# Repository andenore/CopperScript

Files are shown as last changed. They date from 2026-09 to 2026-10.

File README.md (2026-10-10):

# CopperScript

CopperScript is a semantic, strongly typed language for describing PCB
connectivity, electrical intent, and design constraints.

Contributors and LLM agents adding components should read
[AGENTS.md](AGENTS.md) and the
[component integration guidelines](docs/component-integration-guidelines.md),
including RF matching/reference-layout checks and switched-power hard macros
or strong placement/trace-width constraints.

The v0.1 compiler parses `.copper` source into a typed intermediate
representation and runs electrical-rules checks (ERC). It deliberately does not
claim fabrication readiness from routing guidance. Its prototype physical
workflow can place components and attempt geometry-checked detailed routing,
but a routed board still requires independent physical and KiCad DRC signoff.

The [mechanical-geometry specification and checklist](docs/mechanical-geometry.md)
adds polygonal outlines, cutouts and round mounting holes to the physical IR.
Try the routed L-shaped inspection probe (including performance profiling):

```console
uv run python -m examples.mechanical_probe.mechanical_example
```

Output: ignored `build/mechanical-example/`. The frontend supports a separate
[`mechanical` section](docs/mechanical-language.md) for circle/rectangle/polygon,
rounded and closed line/arc outlines, cutouts, NPTH holes/slots and physical rules.
Curved-query limits are explicit; complete manufacturing qualification remains
separate from routing and inspection export. Board-specific
builders live under `examples/`, never in the generic `pcbir` package. The
[examples index](examples/README.md) keeps each standalone example and its
assets in one directory.

A local [mechanical/floorplan editor](docs/mechanical-editor.md) displays real
footprint pads/courtyards, mechanical geometry and locked DXF/enclosure guides.
It supports rough auto-placement, ratsnest/copper filters, checked dragging,
temporary poses and reviewed persistent source locks/geometry edits with undo.
Named datums/edges, attachments, body-only overhangs, height/access policies,
atomic closed-path editing and an optional VS Code host share generic compiler
code. Temporary placement remains unsaved unless explicitly locked into source;
source changes always require diff review and Save. The
[verified implementation checklist](docs/mechanical-editor-plan.md) records tests
and limitations, including convex curved paths and reference-only DXF overlays.

```powershell
uv run copper edit-mechanical examples/mechanical_editor_demo/board.copper --footprint-root "C:/Program Files/KiCad/10.0/share/kicad/footprints"
```

The tool opens a loopback-only browser UI; Ctrl+C stops the service.
Use `--no-browser` to open its printed URL yourself. Footprints may resolve from
explicit roots or pinned Git library assets; proxy inspection is opt-in only.
Scroll the wheel to zoom under the pointer; hold the right mouse button to pan.
Ordinary left-drags apply after checking (with Undo). Numeric poses and rough
auto-placement remain explicit previews; apply or discard them before more edits.

Try `make EXAMPLE=mechanical-curves route` for rounded geometry/slot routing or
`make EXAMPLE=mechanical-reference edit` for a checksum-pinned enclosure guide.
Source edits stale previous routed/fill outputs; rebuild before using them.

[Importable mechanical profiles](docs/mechanical-profiles.md) split reusable
outlines, holes, keepouts and anchored connector placement into separate `.copper`
files. They create no electrical connections. Try the fictional carrier demo
(uses the existing pinned CopperLib connector, no manual library checkout):

```powershell
uv run copper check examples/mechanical_profile_project/board.copper --locked
uv run copper edit-mechanical examples/mechanical_profile_project/board.copper --locked
```

For a real host pattern, see the [CM4 baseboard example](examples/cm4_baseboard/README.md).
It binds two real Hirose 100-pin sockets to a CopperLib mounting profile with
four holes, separates project-owned mechanics from connections, and reserves
module/antenna clearance. It includes a minimal Makefile, editor/placement
commands and a profiled routing workflow that saves ground fills and verifies
zero opens/violations with native KiCad. This four-layer eMMC carrier is a
**routed prototype**, not an order-ready board; no manual CopperLib checkout
is required.

```powershell
make EXAMPLE=cm4 route
```

All examples use the [same Make targets and generic build runner](docs/make-builds.md),
not per-board routing scripts. `make compile-examples` compiles all complete
registered examples; `make EXAMPLE=cm4 compile` builds just one. GNU Make is
required in addition to Python/uv (use `mingw32-make` on Windows if that is its name).

A [50 mm circular LED-ring example](docs/round-led-ring.md) uses an offset nRF52832
as a non-radio controller, twelve GPIO-controlled LEDs and a rear CR2032 holder.
It exports a true KiCad circle and fixed radial placement, with profiling and an
optional routing run:

Its circle, rear ground pour and all fixed placements are declared directly in
`examples/round_led_ring/board.copper`. No Python builder is needed to export it:

```powershell
uv run copper export-kicad-pcb examples/round_led_ring/board.copper --locked `
  -o build/round-led-ring/round_led_ring.kicad_pcb
```

The optional example wrapper adds placement previews, profiling and native checks:

```powershell
uv run python -m examples.round_led_ring.round_led_example `
  --offline
```

Output: ignored `build/round-led-ring/`; default is a placed, unrouted inspection
board. See the linked guide for `--route` and independent ground-fill checks.

## GitHub inspection builds

The [board-routing workflow](.github/workflows/board-routing.yml) attempts the
complete full-vertical routing flow on relevant `main` pushes and manual runs.
Every pushed tag also routes the nRF52 hard-macro example and publishes an
experimental prerelease with source distributions, KiCad projects/local
footprints, six layer SVG previews, reports, logs, profiling and checksums.
CopperLib is fetched by pinned URL into the managed cache; no separate checkout
is required. Failed or timed-out attempts remain inspection drafts, never
manufacturing releases. See [CI setup and downloads](docs/github-board-builds.md).

## Quick start

An opt-in [physical hard-macro trial](docs/physical-hard-macros.md) preserves
Nordic RF matching copper and demonstrates a separate Johanson antenna tee,
corner fill exclusions and whole-assembly rotations. CopperLib downloads through
the pinned URL dependency automatically:

```powershell
uv run python -m examples.nrf_antenna_macro.hard_macro_trial `
  --offline
```

Output: ignored `build/nrf-hard-macro/`. This is an RF-only geometry probe,
not an operational radio or full-vertical routing integration.

A [small powered nRF52/CR2032 example](docs/nrf52-coin-cell.md) adds a 10-pin
SWD connector, two LEDs, two buttons and the radio support circuit:

```powershell
uv run python -m copperscript check examples/nrf52_coin_cell/board.copper --locked
uv run python -m examples.nrf52_coin_cell.nrf52_example --offline
```

Output: `build/nrf52-coin-cell/`. The RF macro is locked and pre-routed;
the remaining circuit is placed but unrouted. Add `--route` to attempt the full
pipeline (the current nRF example still fails package-access gates; see its
linked report/remaining-work guide). This is not production signoff.

Python 3.11 or newer is required. From the repository root:

```console
python -m copperscript check examples/valid_board/board.copper
python -m copperscript check examples/invalid_board/board.copper
python -m copperscript power-check examples/valid_board/board.copper
```

The examples already have a committed lock. Populate the URL dependency cache,
then reproduce without network access:

```console
python -m copperscript check examples/full_vertical/board.copper --locked
python -m copperscript check examples/full_vertical/board.copper --locked --offline
python -m copperscript audit-footprints examples/full_vertical/board.copper --locked --offline
```

Compile a valid design to normalized JSON IR:

```console
python -m copperscript compile examples/valid_board/board.copper -o board.json
```

Generate a self-contained KiCad 8 schematic:

```console
python -m copperscript export-kicad examples/valid_board/board.copper -o valid_board.kicad_sch
```

Generate a KiCad 8 PCB draft with resolved footprint geometry:

```console
python -m copperscript export-kicad-pcb examples/resolved_footprint_board/board.copper -o build/resolved/board.kicad_pcb
```

All PCB export commands automatically write a same-stem `.kicad_pro`, a
project-local `fp-lib-table`, and a `CopperScript.pretty/` footprint library
beside the PCB. No manual KiCad library registration is needed: keep that
generated directory together when sharing or moving it. These are generated
outputs, not user-maintained source libraries. Backend export uses resolved
assets and does not modify your global KiCad configuration. Input resolution
may fetch pinned URL dependencies before generation. See [generated KiCad
projects](docs/kicad-project-export.md) for portability and safety details.

[Managed footprint dependencies](docs/footprint-dependencies.md) resolve exact
GitHub/GitLab `.kicad_mod` asset URLs or KiCad `Library:Footprint` identifiers
bound through `footprint-library` in `copper.mod`. They share the pinned package
cache and `copper.lock`, so no manual footprint download or installation path
is needed. Try the [standalone example](examples/managed_footprints/README.md).

Local `.kicad_mod` paths in imported parts/modules resolve from the declaring
source; board-local paths resolve from the board. Unbound KiCad identifiers can
still use explicit roots:

```console
python -m copperscript export-kicad-pcb board.copper --footprint-root path/to/kicad-footprints
```

Placement remains a deterministic inspection grid and routing is not generated,
so the output is not yet fabrication-ready. Generated proxy pads remain
available for backend development through explicit opt-in:

```console
python -m copperscript export-kicad-pcb examples/valid_board/board.copper --allow-proxy-footprints
```

Produce a deterministic legal placement candidate and a four-gate readiness
report:

```console
python -m copperscript plan-layout examples/valid_board/board.copper --allow-proxy-footprints --candidates 3 -o planned.kicad_pcb --report layout-report.json
```

The planner estimates global routing congestion but does not generate copper.
Its report therefore marks Route as not run and Verify as blocked. See the
[physical layout workflow](docs/layout-workflow.md) for the research,
consolidated stages, algorithms, and limitations.
Placement now estimates facing escape corridors from connected SMD pad demand,
reserving space for via banks from both packages and a transit lane. Fixed
poses and rigid/proximity units remain authoritative; unresolved corridors
appear as `ESCAPE_CHANNEL_DEFICIT` warnings in the layout report. Optional
`--escape-margin-mm 0.5` and `--escape-transit-lanes 1` control this soft
estimate on `plan-layout`, `route-global` and `route-board`, not DRC clearance.
See the [escape-aware placement plan](docs/escape-aware-placement-plan.md).
The physical planner also uses soft supply-domain distribution objectives:
`--power-domain-weight 0.25` is the default; `0` disables domain attraction.
Multi-supply parts participate in each rail group without a hard boundary or
midpoint rule. Declared plane nets have reduced generic wirelength attraction.
Package preflight reserves plane contacts by default with fanout enabled;
`--no-early-plane-stitch` opts out for comparisons. Regional power pours are
explicit `copper_zone` constraints, not automatically inferred planes. See the
[power-domain and routing plan](docs/power-domain-routing-plan.md) and
[language reference](docs/language-reference.md).
The [unprofiled full rerun and layer review](docs/routing-domain-access-review.md)
connects all signal nets and GND pads; one USB return-via warning still blocks
signoff. It also documents the subsequent removed-corner occupancy correction
and the remaining full-rerun requirement.
The [detailed-routing research](docs/detailed-routing-research.md) explains
the geometry checks, fabrication-rule profile, and current full-board limits.

Produce deterministic multilayer global-routing guides after transactional
placement feedback:

```console
python -m copperscript route-global examples/valid_board/board.copper --allow-proxy-footprints -o global-route.json
```

Global guides reserve corridors, layers, and proposed transitions for ordinary
signal nets; declared copper-zone nets are reported as deferred and consume no
global wire corridor. Guides are not tracks or fabrication data.

Attempt detailed routing and write a native DRC report plus an inspection-only
KiCad PCB draft:

```console
python -m copperscript route-board examples/valid_board/board.copper --allow-proxy-footprints --report route-report.json -o routed-draft.kicad_pcb
```

Detailed signal tracks prefer long straight runs and 45-degree bends. Nets with
declared copper zones (typically GND) are deferred from ordinary maze routing;
`route-board` instead attempts short pad escapes and plane vias. Their copper
fill remains provisional until KiCad refills the zones and verifies physical
connectivity. A net named GND without a declared zone receives no implicit
plane.

If a zone pad remains inaccessible, the router first tries a bounded local
rip-up: it reserves a legal plane escape, identifies the ordinary nets that
block it, and reroutes only those nets. If that fails, escape feedback tries
alternative via exits and legal local placement changes from a clean placement.
Use `--zone-local-ripup-trials 0 --zone-escape-trials 0` to disable both, or
adjust `--zone-escape-movement-mm` for the placement step. These trials never
move components under existing copper. Soft plane-aware layer costs and
alternating inner-layer directions can be tuned with
`--layer-preference-cost` and `--direction-preference-cost` (zero disables
either preference); they do not override explicit layer restrictions or DRC.
Accepted ordinary copper is straightened unless `--no-route-smoothing` is
given. Opt-in `--layer-assignment-passes`, `--local-demand-cost` and
`--guide-escape-mm` move ordinary guide runs away from same-layer crossings and
full channels; see the [layer-balance review](docs/routing-layer-balance-review.md).
A reserved package escape is one terminal of its pin, beside the pin's own
surface access and its launch via on every layer; escape copper the finished
route does not need is removed (`--no-escape-terminals` restores port-only
terminals). Opt-in `--package-destination-ports` turns boundary ports toward
each pin's nearest other terminal.
For intentional diagonal placement, add a
`constraint allowed_orientations(U1) { values = "0,45,90"; }`; unconstrained
parts retain 0/90/180/270-degree candidates.

The command exits nonzero when routing or DRC is incomplete. Even a successful
native check does not qualify proxy footprints or replace KiCad and CAM review.
Use `--progress` for flushed phase/group/trial events during long runs; the
shared Make routing workflow enables this automatically and saves them in
`routing.log`. Full ground-feedback trials can each rebuild the routing.
Progress is not completion or signoff evidence; see [routing progress](docs/routing-progress.md).
`--pitch-mm`, `--passes`, and `--search-budget` bound detailed-routing work;
exhausting the search budget is reported per net rather than silently accepting
an unfinished path.
The report's `critical_lane_review` section reviews the exported copper of every
critical net: track lengths, layers and vias, pair and `length_match` skew,
spacing to other copper inside and outside breakout regions, coupled length to
other pairs and bends. `route-board` and `python -m pcbir.critical_preflight`
(for its critical copper) print it as one `CRITICAL LANES:` line; see the
[language reference](docs/language-reference.md#critical-routing-and-qualification).
For difficult boards, `--fanout` pre-escapes crowded SMD pads, `--soft-ripup`
and `--maximum-ripup-blockers 4` try bounded transactional rerouting, and
`--detailed-feedback-trials 4` retries legal placement changes against exact
routing failures. These experiments do not waive physical DRC. Pass
`--verify-plane-fill "C:/Program Files/KiCad/10.0/bin/kicad-cli.exe"` to
refill a disposable KiCad copy and include authoritative open-net/island
findings in the report; a zone outline or stitched via alone is not proof of
connectivity. See [routing research tasks](docs/routing-research-tasks.md).
The [routing-review todo](docs/routing-review-todo.md) tracks correctness and
optimization work; the [first-pass repeated review](docs/routing-review-pass1.md)
records independent KiCad results and the remaining six-layer bottlenecks.
The [second-pass review](docs/routing-review-pass2.md) verifies joint ground
escapes with zero KiCad unconnected items; critical-net and production signoff
remain outstanding.
The [third-pass review](docs/routing-review-pass3.md) confirms consistent
duplicate-land closure and feedback reports without changing the verified copper.

### Full-vertical routing from a fresh checkout (Windows / PowerShell)

This runs the complete placement/global-routing, fanout, detailed-routing,
package-ground escape feedback, native DRC and independent KiCad plane-check
workflow. The [2026-10-06 clean-revision rerun](docs/routing-shared-reference-review.md)
at `52adb05` passes with **49/49 ordinary nets, all eight critical nets, zero
resource overflow and zero KiCad violations/unconnected items**. Every saved
copper layer has zero via/pad overlaps and zero off-angle tracks. The run takes
about 30 minutes without function profiling. Native manufacturing-file export
also succeeds; electrical, impedance and assembly qualification remain separate.

The current example has explicit USB/RF profiles, source-backed
[RF circuit corrections](docs/rf-layout-audit.md), fixed mechanical anchors,
power-domain-aware placement and negotiated package access. USB transitions
explicitly share the declared In1.Cu reference; required return vias remain the
default for other policies. The command below recomputes the current source,
not a historical board. The [cheap critical preflight](docs/full-vertical-example.md#explicit-critical-profiles-and-cheap-preflight)
is also available for inspecting access before a long run.

If exact critical routing fails, optionally add `--critical-feedback-trials 1`
to `route-board` or the critical preflight. This bounded
[critical placement feedback](docs/critical-placement-feedback.md) tries legal
whole-unit rotations/moves and rebuilds all critical copper; it does not relax
profile limits or imply fabrication readiness. Each trial can take minutes.
The historical [pass-9 verification](docs/routing-review-pass9.md) used an
incorrect choke winding mapping. **Do not fabricate those historical USB
routes.** [Pass 11](docs/routing-review-pass11.md) corrected the CopperLib mapping
from Coilcraft's schematic. Copper DRC cannot validate internal component
connections; electrical qualification remains open even with clean routing.
The [paired refinement pass](docs/routing-review-pass10.md) removes redundant
search-step segments while preserving connectivity. It does not yet shorten
the real-board USB detours.
The [access/miter review](docs/routing-review-pass12.md) removes the oblique RF
access segments and small USB backtrack at the unchanged corrected placement.
All eight critical nets remain connected. The earlier corrected-input
[full rerun and six-layer review](docs/routing-review-pass13.md) kept their
copper and all 51 placements unchanged: KiCad finds zero GND/critical opens,
but three ordinary signal nets remain open (34 unconnected items), alongside
the eight library findings. The review records spare inner/bottom capacity,
guide-cost and tree/seam cleanup tasks. [Per-net policy telemetry](docs/routing-search-policy.md)
reports requested/effective detailed layer costs without changing routing.
Production gates remain outstanding.
The historical [compatible-escape increment](docs/routing-review-pass17.md) improved the
matched partial package stage from 72 to 74 exits. Two MCU exits remain pending;
that stage predates the successful current full rerun linked above.
The [escape-first increment](docs/package-access-first.md) now reserves ordinary
package exits before critical long routes with `--fanout`. If package access or
critical compatibility fails, ordinary area routing is blocked with zero search
passes. Bounded legal placement feedback rebuilds the reservations; use
`--package-access-trials 0` to disable moves without disabling the gate.
Directional placement margins now account for ordinary/power/ground access;
the joint preflight still verifies the actual reservations. An allocated fanout
via is not complete-board connectivity.
The [boundary-capacity increment](docs/package-boundary-access.md) now gates area
routing on mutually compatible ordinary paths beyond package collars. Its
matched-placement diagnostic proves 76/76 local witnesses after a multi-bend
fallback. A ready preflight now commits owned local paths and exact-layer
boundary anchors for detailed routing; blocked preflights retain provisional
witnesses only. Neither local access nor those stubs replace full-board routing.
[Pass 18](docs/routing-review-pass18.md) allocates all 76 ordinary exits at the
unchanged saved placement, but the modem-side USB pair then fails. The access
gate correctly blocks area routing. Subsequent alternate-owner preflight passes
both USB pairs, four RF groups, selected ground contacts and all 76 ordinary
boundary paths. The current full rerun subsequently reserves 104 ordinary exits
and all 80 requested GND contacts and passes full-area/fill/native DRC gates.

Install Git, [uv](https://docs.astral.sh/uv/getting-started/installation/), and
KiCad 10 with its footprint libraries first. The latest closure run used
KiCad 10.0.6 and Python 3.13.1. Only CopperScript needs checking out:

```powershell
# Use consistent package line endings in these new checkouts.
git clone -c core.autocrlf=false -c core.eol=lf https://github.com/andenore/CopperScript.git
Set-Location CopperScript

uv sync --python 3.13
# Fetch the exact locked URL dependency (subsequent runs can use --offline).
uv run --no-sync python -m copperscript check examples/full_vertical/board.copper --locked
```

`copper.mod` pins CopperLib's GitHub commit; `copper.lock` verifies its exact
part, footprint and physical-asset inventory in `.copper-cache/pkg/`. No manual
library checkout, footprint download or lock refresh is required. Canonical
package line endings are declared in `.gitattributes`. This reproduces routing
inputs/options, not byte-identical historical output. After fetching,
`--locked --offline` verifies every package byte without changing the lock.
If resolution fails, investigate changed bytes/revisions rather than relocking.
Initial cloning, `uv sync` and uncached URL dependencies need network access.
See uv's
[project workflow](https://docs.astral.sh/uv/guides/projects/) for environment setup.

After the setup above, run the complete workflow with:

```powershell
make EXAMPLE=full-vertical route
```

The shared Make workflow recomputes placement and routing from source with the six-layer
settings below, including the pinned placement scene, critical routing, fanout,
ordinary routing, ground feedback, native DRC and independent KiCad plane
verification and saves native filled copper. Each run writes a fresh `build/full-vertical/runs/<UTC-run-id>/` with
`board.kicad_pcb`, `board.kicad_pro`, `route-report.json`, `routing.log` and
`run.json` (command, timestamps, elapsed time and exit code). `build/` is ignored
by Git. Errors/interruption may leave only logs/partial artifacts; file existence
does not imply routing success. No Gerbers are generated.

The generic runner uses the current Python/uv environment and downloads the locked
dependencies if uncached; it never updates `copper.lock`. Set `RESOLVE_ARGS="--locked --offline"`
to prohibit fetching. It discovers `kicad-cli` on PATH or the standard Windows
KiCad 10 installation. Managed Git footprints are resolved from the lock; the
optional `KICAD_FOOTPRINTS` setting is used for native KiCad verification.
Override paths when needed, preview without routing using `BUILD_ARGS=--dry-run`, or
select a new/empty directory inside `build/`:

```powershell
make EXAMPLE=full-vertical route BUILD_ARGS=--dry-run
make EXAMPLE=full-vertical route `
  KICAD_CLI="C:/Program Files/KiCad/10.0/bin/kicad-cli.exe" `
  KICAD_FOOTPRINTS="C:/Program Files/KiCad/10.0/share/kicad/footprints" `
  RUN_DIR="build/my-routing-run"
```

The runner preserves the router's exit code: **1** means unmet routing/DRC
gates, **2** means setup/execution error, and **130** means interruption.
GNU Make itself returns nonzero (usually 2) when its recipe fails.
An existing nonempty output directory is rejected so old results cannot be
mistaken for a new run. Exit 0 still does not constitute manufacturing signoff.
Allow tens of minutes for a full-vertical run; the shared workflow is not a claim
that every example has passed complete routing.

Function profiling is enabled by default. Each run also saves `routing.prof`,
readable/JSON hotspot summaries and `phase-timings.json` under the same ignored
directory. Instrumentation adds overhead; use `PROFILE=none` for uninstrumented
speed comparisons (phase events are still saved). See
[profiling and optimization assessment](docs/routing-performance.md) for details,
current evidence and the prioritized optimization work list.
The detailed [optimization todos](docs/routing-optimization-todo.md) track implementation.
Package preflight can now negotiate alternate ordinary/critical/selected-ground
escape patterns before placement repair. The default is at most two proposals;
use `EXTRA_ROUTE_ARGS="--package-pattern-trials 0"` for a baseline comparison.
Every accepted pattern preserves prior exits and passes fresh owner/native
checks; this does not certify onward area routing. See
[package-access design and remaining work](docs/package-access-first.md).
Local repair now supports bounded blocker-cone expansion; use
`EXTRA_ROUTE_ARGS="--zone-dependency-expansions 0"` to compare without that extension.
Small noncritical placement moves also try bounded incremental repair. Use
`EXTRA_ROUTE_ARGS=--no-incremental-placement-repair` to compare against full placement reroutes;
unsupported moves always retain that fallback.
Inspect a run without changing it using `uv run --no-sync python -m pcbir.routing_benchmark summarize "build/full-vertical/runs/<run-id>"`.
The [performance guide](docs/routing-performance.md) explains guarded before/after comparisons.

For the equivalent explicit CLI invocation, adjust the KiCad paths if your
installation is elsewhere. From the CopperScript repository root, run:

```powershell
$kicadCli = "C:\Program Files\KiCad\10.0\bin\kicad-cli.exe"
New-Item -ItemType Directory -Force "build/full-vertical" | Out-Null

uv run --no-sync python -m copperscript route-board examples/full_vertical/board.copper `
  --locked --offline --layers 6 --fab-profile jlcpcb-six-layer `
  --hard-macro examples/full_vertical/buck-macro.json `
  --hard-macro examples/full_vertical/nrf-antenna-macro.json `
  --candidates 3 --placement-candidate candidate-00 `
  --feedback-iterations 1 --router-iterations 5 --critical-feedback-trials 0 `
  --pitch-mm 1 --passes 2 --search-budget 20000 `
  --soft-ripup --fanout --constrained-pins-first --progressive-guides `
  --repair-budget-multiplier 10 `
  --plane-contact-radius-mm 5 `
  --zone-escape-trials 4 --zone-local-ripup-trials 6 `
  --verify-plane-fill $kicadCli `
  --report build/full-vertical/route-report.json `
  -o build/full-vertical/board.kicad_pcb

$routingExitCode = $LASTEXITCODE
Write-Host "Routing exit code: $routingExitCode (1 means a draft with unmet gates; inspect the report)"
```

This recomputes placement and copper from `.copper` and footprints; it does not
load an earlier routed board. Allow tens of minutes: the recorded pipeline took
about 19 minutes plus final export/verification, and harder feedback trials can
take substantially longer. No external timing wrapper is required. KiCad library
versions can change geometry and results; record the installed version and
footprint inputs when comparing runs.

The explicit CLI outputs are `board.kicad_pcb`, its same-stem `board.kicad_pro`, and
`route-report.json` under `build/full-vertical/`. Open the board with its project
so KiCad uses the exported design rules. The report includes the independent
`plane_verification` result. The [latest complete run](docs/routing-shared-reference-review.md)
exits **0** with no ordinary opens, native violations, unconnected items or
resource overflow. Its explicit-copper IR report still defers GND to native
plane fill; `routing_complete=true` does not mean `fabrication_ready=true`.
An output file or zero airwires is not electrical, USB/RF or assembly
qualification. Older failed reports remain unchanged as historical evidence.
Vias avoid all pads by default, including same-net pads and annulus-edge contact.
The shared routing workflow does not enable blanket via-in-pad. Explicit
`--ground-via-in-pad` permits filled-and-capped GND vias for this six-layer
profile; that process must be explicitly qualified with the fabricator before
ordering a board.

For independent copper-layer plots and via/pad/bend metrics, see
[the layer-review workflow](docs/routing-layer-review.md).

After a run passes, generate native Gerbers/drills from its saved filled board
using the [manufacturing-file workflow](docs/manufacturing-files.md):

```powershell
uv run --no-sync python -m copperscript export-manufacturing `
  "build/full-vertical/runs/<run-id>/board.kicad_pcb" `
  --kicad-cli "C:/Program Files/KiCad/10.0/bin/kicad-cli.exe" `
  --skip-independent-cam `
  -o "build/full-vertical/runs/<run-id>/manufacturing"
```

This refuses native opens/violations. It produces `gerbers-drill.zip` and
`manufacturing-package.zip`, not an independently qualified release. The
explicit CAM skip follows the requested prototype workflow. This fixture has
no reviewed assembly BOM/CPL; supplier availability and component/support-circuit
qualification still require review before ordering.

To repeat the final independent refill/DRC on a saved copy without modifying
the routed draft:

```powershell
Copy-Item "build/full-vertical/board.kicad_pcb" "build/full-vertical/verified.kicad_pcb"
Copy-Item "build/full-vertical/board.kicad_pro" "build/full-vertical/verified.kicad_pro"
& $kicadCli pcb drc --format json --severity-all --refill-zones --save-board `
  --output "build/full-vertical/kicad-drc.json" "build/full-vertical/verified.kicad_pcb"

$drc = Get-Content "build/full-vertical/kicad-drc.json" -Raw | ConvertFrom-Json
Write-Host "Unconnected items: $($drc.unconnected_items.Count)"
$drc.violations | Group-Object type | Select-Object Name, Count
```

Keep all reported findings visible. The second review found zero unconnected
items, no shorts/clearance/dangling findings, and four library issues plus four
library mismatches; this is a recorded result, not a guarantee for changed inputs.

Validate and inspect a KiCad footprint before resolving it into a physical
design:

```console
python -m copperscript check-footprint path/to/package.kicad_mod --strict
```

For a development installation with the `copper` command:

```console
python -m pip install -e ".[test]"
copper check examples/valid_board/board.copper
python -m pytest
```

## Example

```copper
board SensorBoard {
    use library "tiny";
    import sensors "github.com/copperscript/examples/sensors";
    import stm32 "github.com/copperscript/examples/stm32";

    component U1: stm32.STM32G0B1CBT6;
    component U2: sensors.BME280;
    component R1: RESISTOR { value = 4.7kohm; }

    configure U1.I2C1 as SENSOR_BUS {
        SDA = PB7;
        SCL = PB6;
    }

    net I2C_SDA {
        U1.PB7;
        U2.SDA;
        R1.2;
    }

    supply V3V3 {
        voltage = 3.3V;
        external = true;
    }
}
```

See the [design specification](docs/design-specification.md), the
[language reference](docs/language-reference.md), and the complete [valid
example](examples/valid_board/board.copper).

Device-library authors should use the compact, table-driven
[device generation workflow](docs/device-generation.md) rather than writing
large MCU definitions by hand.

The implemented [rich device model](docs/rich-device-model-proposal.md) describes
how CopperScript can represent flexible Nordic pin routing, mode-dependent FX10
pins, differential ADC channels, multi-unit op-amps, and package connection
rules and the cross-vendor acceptance fixtures used to validate them.

The [hierarchical example](examples/hierarchical_board/board.copper) instantiates a
reusable [5 V to 3.3 V buck supply](examples/packages/power/buck_5v_to_3v3.copper)
and imports the sensor part from a separate package.

## Packages

Imports use stable URL-like package paths and an explicit local alias:

```copper
import power "github.com/copperscript/examples/power";
module PWR: power.Buck5VTo3V3;
```

Versions and development replacements are deliberately kept out of source
files. They live in `copper.mod`:

```text
module github.com/anden/CopperScript
require github.com/copperscript/examples v0.1.0
replace github.com/copperscript/examples => ./examples/packages
```

The compiler resolves the longest matching required module, loads all
`.copper` part and module definitions in the selected package directory, and
records the complete downloaded asset inventory in `copper.lock`. Without a `replace`, v0.1 fetches
tagged GitHub modules into `.copper-cache`; package source is parsed as data and
no package code is executed. Local replacements remain editable and retain
their current content hash as IR provenance without being locked in the sum
file.

## Compiler architecture

```text
.copper source
    -> lexer
    -> source-aware syntax tree
    -> hierarchical electrical IR
         |-> JSON IR
         |-> KiCad schematic backend
         `-> derived flat view -> electrical-rules checker
                              `-> power-state analyzer
                              `-> footprint resolver + draft physicalizer
                                      `-> physical IR
                                          |-> legal placement + routability estimate
                                          `-> KiCad PCB backend
```

The stages are intentionally separate so editor tooling and a future language
server can reuse parsing, semantic lowering, and ERC independently.

Key modules:

- `pcbir.lexer` and `pcbir.parser` — dependency-free source frontend.
- `pcbir.syntax` — source locations and syntax-tree declarations.
- `pcbir.compiler` — semantic lowering and typed unit validation.
- `pcbir.packages` — manifests, package resolution, Git cache, and checksums.
- `pcbir.model` and `pcbir.quantities` — immutable semantic IR.
- `pcbir.elaborate` — explicit hierarchy-to-flat derivation for consumers that
  require a global connectivity view.
- `pcbir.erc` — reusable electrical-rules passes.
- `pcbir.power` — explicit steady-state power-domain analysis.
- `pcbir.physical` — immutable, backend-neutral board geometry, footprints,
  placements, nets, tracks, vias, stackup, and design rules.
- `pcbir.footprints` — deterministic `.kicad_mod` reference resolution from
  board-relative paths or explicit KiCad library roots.
- `pcbir.physicalize` — resolved-footprint and typed placement-constraint
  lowering; proxy geometry is an explicit development fallback.
- `pcbir.placement` — hierarchy-aware analytical placement, hybrid
  legalization, route-aware detailed refinement, and deterministic Pareto
  candidate generation.
- `pcbir.layout` — four-gate readiness orchestration and placement reporting.
- `pcbir.routing` — deterministic multilayer global routing with
  negotiated-congestion guides and explicit overflow diagnostics.
- `pcbir.routeflow` — full-route candidate selection, bounded legal placement
  moves, atomic rollback, stagnation control, and fresh-route certification.
- `pcbir.critical` — profile-driven locked copper for critical, differential,
  clock, CAN, RF-feed, power, and length/via-constrained routes.
- `pcbir.detailed` — guide-aware deterministic general routing with legal pad
  escape, exact foreign-copper clearance, locked critical copper, and bounded
  whole-pass rerouting. See [detailed-routing research](docs/detailed-routing-research.md).
- `pcbir.geometry`, `pcbir.any_angle`, and `pcbir.shove` — shared exact integer
  predicates, deterministic visibility walkaround, and atomic recursive line
  shove with fail-safe rollback.
- `pcbir.drc` — fail-closed exact-copper checks, explicit coverage, scoped
  waivers, and content-bound physical signoff tokens.
- `pcbir.flow` — compatible global/critical/detailed routing and DRC
  orchestration with no proxy-to-copper shortcuts.
- `pcbir.manufacturing` — gated KiCad 10 Gerber/drill/netlist releases with
  independent structural CAM parsing, manifests, checksums, and atomic publish.
- `pcbir.process_drc` — separate provenance-bearing fabrication, stencil, and
  assembly capability gates.
- `pcbir.engineering` — evidence-graded screening results that explicitly state
  claim scope and model limitations.
- `pcbir.cam_qualification` and `pcbir.constraint_coverage` — fail-closed
  independent-tool evidence and end-to-end ownership of hard constraints.
- `pcbir.physical` — immutable placement, exact copper, typed zone/keepout
  intent, and content-bound external fill provenance. Manufacturing boards with
  zones are authoritatively refilled and saved by the pinned KiCad toolchain.
- `pcbir.importers.kicad_mod` — dependency-free, fail-safe KiCad footprint
  parser and normalizer.
- `pcbir.devicegen` — compact JSON/CSV device bundles, bounded extraction work
  packets, validation, and deterministic library generation.
- `pcbir.backends` — immutable backend artifacts and the KiCad schematic and
  PCB generators.
- `pcbir.serializer` — versioned JSON IR output.
- `pcbir.cli` — checking, compilation, KiCad export, and footprint inspection
  commands.

Python IR constructions are confined to test fixtures. `.copper` is the only
user-facing source format accepted by the compiler.

The [full-vertical acceptance design](docs/full-vertical-example.md) combines
an STM32G0C1, CAN, an EG800G cellular modem over UART and USB, an nRF52832
Bluetooth slave, low-power motion sensing, GNSS, user I/O, and two SWD ports.
It is the integration fixture for progressing from CopperScript source toward
reviewed manufacturing outputs; its documentation distinguishes implemented
checks from the remaining production-layout work.

## Current ERC checks

- Unknown parts, components, pins, nets, and supply sources
- Duplicate component, net, supply, and interface names
- Pins assigned to multiple nets
- Multiple push-pull or power outputs on one net
- Supply voltages outside declared pin limits
- Invalid, missing, or off-net supply sources
- Disconnected and unsourced power inputs
- I²C signal bindings, pin compatibility, and SDA/SCL pull-ups
- MCU peripheral completeness, package-pin availability, and mux validity
- Duplicate exclusive peripheral/pin selections and incompatible mux-resource settings
- Package DNC/required-pin rules and required net traits
- Functional-unit endpoint resolution to canonical physical pins
- Differential-pair completeness and finite device-mode selections
- Parametric route-rule pad membership and power-domain operating ranges

`power-check` separately evaluates named rail states and warns when a driven net
may back-power an I/O domain declared off. It is intentionally a conservative
steady-state analysis, not firmware or transient simulation.

Physical constraints are separate from connectivity. During physical lowering,
placement regions, keepouts, fixed locations, legal orientations, alignment,
minimum/maximum distance, and explicit placement groups become typed physical
IR and are enforced by `plan-layout`. Hierarchy, interfaces, and proximity
constraints also produce soft semantic placement groups.

The physical Python API also supports [rigid reference-layout clusters](docs/rigid-placement-clusters.md).
Unlike soft groups, these retain identity-bound local footprint poses and
keepouts during whole-cluster placement/refinement and routing feedback.
Full-vertical now binds the experimental TPS62130A and Nordic/Johanson
[hard macros](docs/physical-hard-macros.md) by default. Their local copper is
locked, but regulator current/thermal performance and RF/antenna tuning remain
unqualified. See the [integration plan](docs/full-vertical-macro-ground-plan.md).

## Exact assembly-selection prototype

Exact board-side manufacturer/MPN and supplier selections can be prototyped with
`copper assembly snapshot`, `copper assembly check` and `copper assembly bom`.
These are offline checks, not stock lookup or production approval. See
[assembly pinning](docs/assembly-pinning.md) for the workflow and JLCPCB API scope.

## KiCad schematic backend

The initial backend targets KiCad 8's `20231120` `.kicad_sch` format. It embeds
deterministic generic symbols derived from part definitions, places symbols on
a backend-owned grid, and connects pins through short stubs and named labels.
Generated coordinates and UUIDs never enter the CopperScript IR.

This first revision emits one flat sheet. Hierarchical designs are elaborated
explicitly and retain their original qualified component paths in hidden
`CopperScriptPath` properties. Native KiCad hierarchical sheets and mappings to
standard KiCad symbols are planned follow-up work.

## Physical IR and KiCad PCB backend

The physical IR is separate from the electrical IR and stores exact geometry
as integer nanometres. It currently models polygonal board outlines, two-layer
stackups, basic design rules, footprint bodies, pads and courtyards, component
placement, regions, keepouts, fixed/relative rules, semantic groups, physical
net-to-pad assignments, track segments, and vias. It validates cross-references
when constructed.

The KiCad PCB backend targets KiCad 8's `20240108` board format. It emits a
self-contained board with deterministic UUIDs, embedded footprints, net
assignments, copper tracks and vias when present, and a closed `Edge.Cuts`
outline. Each PCB export also writes a same-stem `.kicad_pro` with the physical
IR's minimum clearance and default net-class widths/vias; open the board with
that project for KiCad DRC. Backend tests include a completely routed synthetic
physical board. Generated reference designators are on fabrication layers
until a collision-aware silkscreen labeling pass is available.

The `.copper` frontend supports selected placement, routing, and copper-zone
constraints, while arbitrary board-outline authoring is still pending.
`export-kicad-pcb` resolves selected `.kicad_mod` files into
physical IR, checks that their numbered pads exactly match the electrical part,
and arranges components on a deterministic grid. These unrouted drafts must not
be sent for fabrication. Generic proxy geometry is available only with
`--allow-proxy-footprints` and remains clearly marked in output warnings.

`plan-layout` replaces the inspection grid with a deterministic, clearance-legal
placement and emits coarse routability metrics. It still creates no tracks and
explicitly blocks fabrication sign-off.

## CAM and RF/power qualification

Final-native CAM audits and RF/power contract assessments are documented in
[engineering qualification](docs/engineering-qualification.md). The
[implementation checklist](docs/qualification-todo.md) separates tested algorithms
from missing qualified geometry adapters, supplier inputs and prototype evidence.

## KiCad footprint importer

`load_kicad_mod()` and `parse_kicad_mod()` convert KiCad 6–8 footprint files
into `PhysicalFootprint`. The initial importer covers common SMD, plated and
non-plated through-hole pads, circular and oval drills, rotations, independent
mask/paste presence, round-rectangle ratios, and the usual line, rectangle,
circle, arc, and polygon graphics. Imported geometry can be emitted directly by
the KiCad PCB backend.

The importer is intentionally fail-safe. Custom/trapezoid pads, copper or mask
graphics, drill offsets, and unrepresented fabrication modifiers are rejected.
Presentation-only omissions such as 3D models and user text produce explicit
warnings; `--strict` promotes those warnings to errors. Source format, version,
generator, path, and SHA-256 checksum are retained as footprint metadata.

Managed footprint URLs and manifest-bound `Library:Footprint` identifiers use
the declared provider revision and inventory. Local `.kicad_mod` paths are
relative to the declaring source. Unbound `Library:Footprint` identifiers search
`<root>/Library.pretty/Footprint.kicad_mod` and
`<root>/Library/Footprint.kicad_mod` for each `--footprint-root`. Resolution
fails on zero or multiple matches, and the selected name must agree with the
footprint name declared inside the file. CopperScript never searches an
installed KiCad library implicitly.

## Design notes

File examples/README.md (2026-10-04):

# CopperScript examples

Each standalone example owns a directory so its source, helper code, local
assets and generated reference inputs stay together. The reusable component
packages under `packages/` are separate from these board and language examples.

| Example | Entry point |
| --- | --- |
| Device model showcase | `device_model_showcase/board.copper` |
| Full vertical integration board | `full_vertical/board.copper` |
| Hierarchical board | `hierarchical_board/board.copper` |
| Invalid diagnostics fixture | `invalid_board/board.copper` |
| Mechanical anchors | `mechanical_anchors/board.copper` |
| Mechanical curves | `mechanical_curves/board.copper` |
| Mechanical editor demo | `mechanical_editor_demo/board.copper` |
| Mechanical outline | `mechanical_outline/board.copper` |
| Mechanical reference assets | `mechanical_reference/board.copper` |
| Mechanical routing probe | `mechanical_probe/mechanical_example.py` |
| nRF52832 coin-cell board | `nrf52_coin_cell/board.copper` |
| nRF antenna hard-macro probe | `nrf_antenna_macro/board.copper` |
| Resolved local footprint | `resolved_footprint_board/board.copper` |
| Round LED ring | `round_led_ring/board.copper` |
| Valid compiler fixture | `valid_board/board.copper` |

The CM4 carrier, managed-footprint, and simulation examples already use
multi-file directories and retain their existing folder names.

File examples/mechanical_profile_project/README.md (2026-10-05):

# Split-file mechanical profile example

This is a compiler/editor demonstration, not a complete circuit, Raspberry Pi
HAT, or production-ready board. It uses an existing CopperLib debug header.

```text
board.copper                 Components, nets and explicit profile bindings
mechanics/carrier.copper     Reusable outline, holes, keepouts and pad anchor
```

The board applies `carrier.Carrier as host`, binding `debug` to `J_DEBUG`.
Imported holes become `host/H1` and `host/H2`; the board's extra `LOCAL` hole
remains project-owned. The profile fixes header pad 1 at `(15mm,10mm)`, with
90-degree front-side orientation and an exact footprint requirement. It creates
no component or electrical connection. Profiles can be consumed by additional
boards, or published in a versioned library and imported by URL-like package path.

From the CopperScript repository root:

```powershell
uv run copper check examples/mechanical_profile_project/board.copper --locked
uv run copper edit-mechanical examples/mechanical_profile_project/board.copper --locked
uv run copper export-kicad-pcb examples/mechanical_profile_project/board.copper --locked -o build/mechanical-profile/demo.kicad_pcb
```

Add `--offline` after dependencies are cached. This example inherits the
repository's pinned `copper.mod` and lock; copying it to a separate project
requires that project's own CopperLib requirement and lock, not a manual
CopperLib checkout. Local mechanics remain normal project source, without a
separate locked dependency.

Source saving is not yet enabled in the editor. Imported connector poses cannot
be dragged; imported/local geometry has ownership tooltips. Layer-scoped copper
keepouts are physical obstacles, not proof of routing or assembly qualification.

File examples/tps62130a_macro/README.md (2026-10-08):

# TPS62130A macro layout probe

This single-regulator board uses the CopperLib electrical module and its current
hard-macro asset. It has no CopperVigo components or ordinary board routing.
The output is a KiCad board for inspecting the regulator's own copper and filled
planes. The default 180° view puts VIN on the left, the inductor and VOUT on the
right, and the broad GND return below, matching the orientation of TI datasheet
Figure 11-1. The generated `board.copper` and local dependency manifest are
saved alongside the board for reproducibility.

From the CopperScript repository root, with a sibling CopperLib checkout and
KiCad footprints installed:

```sh
.venv/bin/python -m examples.tps62130a_macro.trial
```

Use `--copperlib PATH`, `--output-dir PATH`, `--footprint-root PATH`,
`--enabled`, or `--rotation 90` to vary the isolated probe. The script runs
KiCad 10 refill and DRC when `kicad-cli` is installed, and requires each owned
GND zone to have actual filled copper and the fixed VIN, SW and VOUT polygons
to remain netted.
This is a geometry probe,
not a production regulator qualification.

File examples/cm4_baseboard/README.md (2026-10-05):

# Raspberry Pi Compute Module 4 baseboard

A real CM4 connector/mounting-pattern example using importable mechanical
profiles, not a fictional host. **This is a routed carrier prototype, not an
order-ready PCB.** The installed CM4 must have eMMC with its OS already flashed
using a CM4IO or another USB-capable carrier. CM4 Lite and CM5 are not supported
by this example. No firmware is supplied.

The 70 x 70 mm, four-layer carrier contains two Hirose
`DF40C-100DS-0.4V(51)` sockets, regulated external 5 V input, a 3.3 V UART
header, four GPIO signals, a GLOBAL_EN shutdown jumper, a low-current activity
LED, and GPIO_VREF decoupling. The module itself is removable and purchased
separately, not an extra soldered footprint/BOM item.

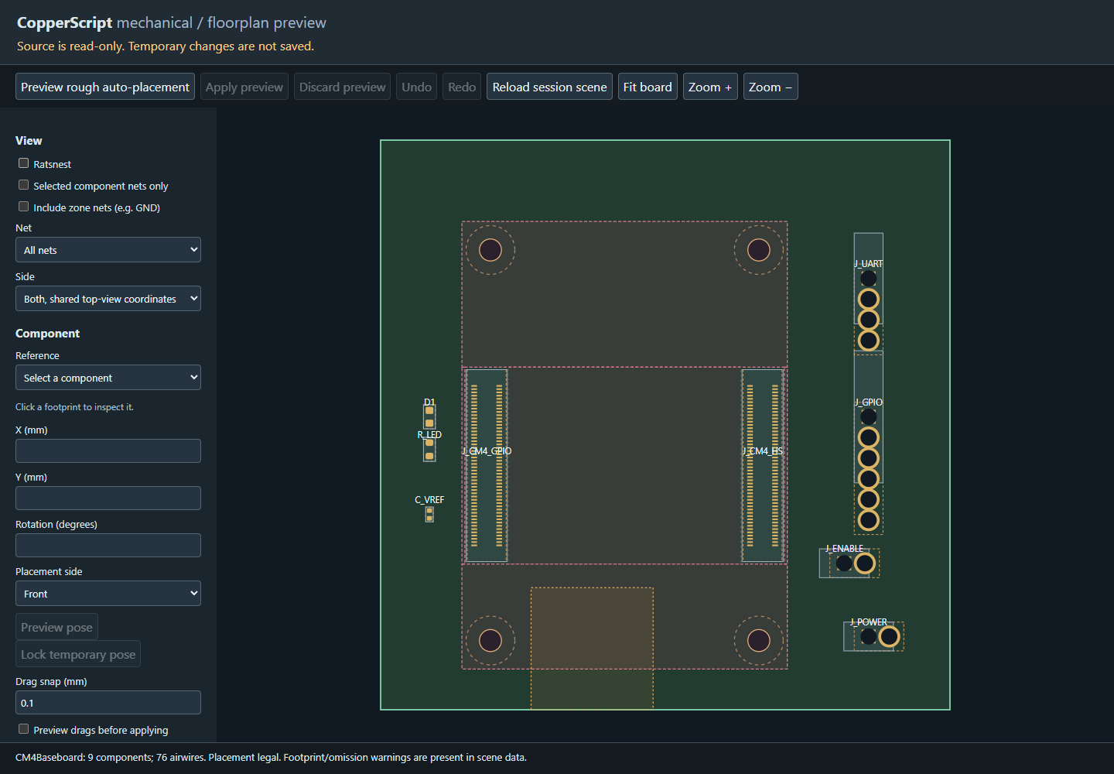
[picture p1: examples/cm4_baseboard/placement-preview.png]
CM4 carrier placement draft: two sockets, four holes and antenna clearance


Pink regions reserve the module body; the orange region is the antenna copper
keepout. This preview deliberately shows placement only, not completed routing.

## Reusing the mechanical pattern

`board.copper` owns electrical connections. `mechanics/carrier.copper` owns
the carrier outline, rules and four-layer antenna keepout. It imports
`cm4.CM4Mounting` from **CopperLib via its GitHub package URL**, then explicitly
binds its `gpio` and `high_speed` roles to the two sockets. No manual CopperLib
checkout is needed. `copper.mod` pins one revision; `copper.lock` authenticates
the downloaded library content. Local mechanical files remain editable.

The profile gives both connectors a 270-degree orientation and locks their
actual pad-1 positions, not guessed body centres. All 200 placed pad centres
are checked against Raspberry Pi's official CM4IO v5 carrier footprint.
It also contributes four M2.5 mounting positions with 2.7 mm NPTH carrier
drills, spaced 33 x 48 mm. The module envelope is x=10..50, y=10..65 mm.
There is no profile transform at the use site yet; changing this datum requires
an explicit profile revision, not moving one connector independently.

The selected 1.5 mm mating height leaves **no spare component height below the
CM4**. Front placement keepouts reserve its body, with two narrow courtyard
corridors for the sockets. Do not add other parts in those corridors. The
antenna clearance spans x=18.5..33.5, y=55..70 mm, excludes all copper on all
four layers, and reaches the bottom board edge. This is a conservative
projection of the datasheet's preferred antenna clearance, not RF qualification
or enclosure validation. Check the assembled module, screw/spacer heights,
cooling and surrounding metal in 3D before manufacture.

## Run from a CopperScript checkout

At the repository root, install the project once with `uv sync --extra test`.
The pinned Git footprint providers are resolved from `copper.lock`. On Windows:

```powershell
uv run --no-sync copper check examples/cm4_baseboard/board.copper --locked
uv run --no-sync copper plan-layout examples/cm4_baseboard/board.copper --locked `
  --layers 4 --fab-profile jlcpcb-four-layer `
  -o build/cm4-baseboard/cm4_baseboard.kicad_pcb `
  --report build/cm4-baseboard/placement.json
uv run --no-sync copper edit-mechanical examples/cm4_baseboard/board.copper --locked `
  --layers 4 --fab-profile jlcpcb-four-layer
```

The editor shows the locked imported sockets, mounting holes, keepouts and
toggleable ratsnest. Wheel zoom and right-button pan work as in other examples.
Run a fresh editor session for this board; existing sessions retain their own
in-memory poses. The editor currently previews poses but does not save them.

On Linux/macOS with `make`, from this example directory:

```sh
make check
make layout
make edit
```

The shared Makefile resolves managed footprints from the pinned Git providers.
Set `KICAD_FOOTPRINTS` only when native KiCad verification needs a nonstandard
installed footprint path. macOS and other custom installations should also
provide that override for native checks.

The `Makefile` produces placement drafts under ignored `build/cm4-baseboard`.
It intentionally does not call this a release/manufacturing build.
After the initial dependency download, add `--offline` to CLI commands for
cached builds. A full KiCad footprint installation is only needed for native
KiCad verification and routing.

### Complete routing and ground fill

From the repository root (Windows, KiCad 10 installed):

```powershell
make EXAMPLE=cm4 route
```

The shared [Make workflow](../../docs/make-builds.md) fetches pinned imports if needed, runs package escape
and detailed routing with profiling enabled, then **saves the ground fills**
and runs native KiCad DRC on that exact output board. No rule relaxation or
via-in-pad permission is added. Default outputs go in a timestamped directory
under ignored `build/cm4-baseboard/runs/`; open its `board.kicad_pcb` in KiCad.
`route-report.json`, `kicad-drc.json`, logs, input/output hashes and performance
reports are retained together. Success requires zero native violations and
zero unconnected items; a failed build returns nonzero and retains diagnostics.

For Linux/macOS or another KiCad installation, supply paths explicitly:

```sh
make EXAMPLE=cm4 route \
  KICAD_CLI=/usr/bin/kicad-cli \
  KICAD_FOOTPRINTS=/usr/share/kicad/footprints
# Or from this example directory:
make route KICAD_CLI=/usr/bin/kicad-cli KICAD_FOOTPRINTS=/usr/share/kicad/footprints
```

Set `RESOLVE_ARGS="--locked --offline"` after the first dependency download.
`RUN_DIR` selects a new/empty directory below the repository's `build/`; repeat
runs default to fresh timestamped directories. Use `PROFILE=none` for timing
comparisons. GNU Make is required (`mingw32-make` is also supported on Windows).
The example Makefile contains settings only; the same `make/board.mk` recipes
compile and route other boards without custom per-example Python scripts.

## Header wiring

| Header | Pins in footprint-number order |
| --- | --- |
| J_POWER | 1: regulated +5 V input; 2: GND |
| J_UART | 1: CM4 3.3 V sense; 2: CM4 TX/GPIO14; 3: CM4 RX/GPIO15; 4: GND |
| J_GPIO | 1: CM4 3.3 V; 2: GPIO2; 3: GPIO3; 4: GPIO17; 5: GPIO27; 6: GND |
| J_ENABLE | 1: GLOBAL_EN; 2: GND; leave open normally, short to power off |

Supply regulated 4.75..5.25 V at J_POWER. There is no reverse-polarity,
overvoltage, fuse or USB-C power-negotiation circuitry: use a suitable bench
supply and verify power routing/current sharing before connecting hardware.
Hirose rates each contact at 0.3 A; a supply's rating does not prove the socket
contacts can carry that current evenly. Every fitted ground contact and all
six 5 V contacts need a real carrier connection, not a routing waiver.

UART requires enabling/configuring the appropriate CM4 UART. Use a **3.3 V
logic** adapter, not RS-232 or 5 V logic. Cross host RX/TX and never inject power
through J_UART/J_GPIO. CM4 3.3 V outputs supply GPIO_VREF and the LED; the
`external = true` 3.3 V declaration describes the plugged-in module's source,
not permission to attach an independent 3.3 V supply. GPIO2/GPIO3 already have
CM4 pullups; extra I2C hardware is not modeled or validated here.

## Validation and remaining work

ERC checks the socket pin map, required power/ground contacts, 5 V limits and
reserved pins. Sockets expose passive signal contacts; this is **not** a full
active CM4 peripheral/mux/power-state model. Electrical sequencing, backfeed,
timing, loading and firmware assignments still need review.

Routing verified with KiCad 10.0.6: **all 11 ordinary nets routed**, GND connected
through escapes and filled In1.Cu/B.Cu zones, **zero unconnected items and zero
native DRC violations**. A separate copper-layer audit found zero via/pad
overlaps and only horizontal, vertical or 45-degree segments. In2.Cu carries
most signal length; In1.Cu is the ground reference. Some 90-degree joins remain,
so this is a connectivity/DRC-verified prototype, not an optimized reference
layout. The pre-fill IR-only checker still reports GND open because it does not
model filled zone copper; native filled-board evidence closes that check.

No Gerbers/assembly release or production-ready claim is made. Power traces
currently use the prototype minimum width: power routing/current sharing,
thermal performance and protection require review before powering hardware.
Manufacturing export remains a separate step.
The pin headers also need exact orderable selections before assembly ordering.
USB recovery, SD/Lite support, Ethernet, HDMI, camera, display and PCIe are
deliberately absent rather than partially connected.

Sources: [CM4 datasheet](https://datasheets.raspberrypi.com/cm4/cm4-datasheet.pdf)
(Fig. 4 and Table 6), [official CM4IO design files](https://pip.raspberrypi.com/categories/1210-design-files),
and [Hirose connector](https://www.hirose.com/en/product/p/CL0684-4033-4-51).
The downloaded sources and hashes are recorded in CopperLib's
`packages/profiles/raspberry_pi/cm4/evidence`;
raw vendor files are not redistributed with this example.

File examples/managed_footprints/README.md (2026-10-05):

# Managed footprint dependencies

This isolated project imports reusable resistor/capacitor parts and resolves
their geometry from a pinned KiCad Git repository commit. The resistor uses a
manifest-bound KiCad namespace; the capacitor uses an exact module URL. Both
share one repository download and one complete content inventory.

From the repository root, install the compiler and prepare the dependency:

```text
python -m pip install -e .
python -m copperscript lock examples/managed_footprints/board.copper
python -m copperscript audit-footprints examples/managed_footprints/board.copper --locked --offline --json
python -m copperscript export-kicad-pcb examples/managed_footprints/board.copper --locked --offline -o build/managed-footprints.kicad_pcb
```

The first command that resolves managed geometry downloads the complete pinned
footprint repository into this project's `.copper-cache`. The example's
`copper.lock` is created by `lock`; commit it in your own project. `--locked`
verifies the selected revision and inventory, and `--offline` requires the cache
to exist already. A lockfile alone does not contain the downloaded geometry.

No KiCad installation or `--footprint-root` is needed to audit or generate the
PCB. Native KiCad inspection remains a separate tool step. The layout is an
inspection draft; this example does not attempt manufacturing qualification.
See [footprint dependencies](../../docs/footprint-dependencies.md).

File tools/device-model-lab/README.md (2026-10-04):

# CopperScript device-model compatibility lab

This bounded research lab is kept with CopperScript tooling rather than in
CopperLib's reusable component catalogue. It records a provenance-first
`STM32G0B1CBT6` proof, CubeMX reconciliation fixtures and cross-vendor model
gap case studies. The results are incomplete and are not production packages.

From this directory, install the optional test/upstream dependencies and run:

```powershell
python -m copperscript_stm32g0 validate
python -m copperscript_stm32g0 generate
python -m copperscript_stm32g0 coverage
python -m pytest
python -m copperscript_stm32g0 compatibility
```

The normalized bundle is in `data/bundles/stm32g0b1/`; generated files are in
`generated/`. Source acquisition is opt-in and writes only ignored cache data.
The compatibility reports classify support gaps without changing CopperScript's
language or the generic CopperLib package contract.

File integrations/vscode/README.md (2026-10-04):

# CopperScript mechanical editor for VS Code

Optional custom text editor for `.copper` boards. Source stays authoritative;
reviewed edits use native WorkspaceEdit, document Undo/Redo, encoding and Save.
Unsaved text edits are compiled in memory. No backend source writes, downloads,
shell invocation or public server. A trusted **local workspace** is required.

Pin CopperScript in your project dependencies/lock first, run its normal fetch
workflow, and compute the exact compiler content identity:

```sh
uv run --locked --offline python -m pcbir.editor.document --fingerprint
```

Set `copperscript.mechanical.compilerDigest` to that 64-character result and
`copperscript.mechanical.footprintRoots` to installed KiCad footprint directories.
The default `compilerCommand` is `["uv", "run", "--locked", "--offline", "python"]`.
You may explicitly configure a pinned virtual environment's interpreter instead.
Commands are argv arrays, never shell strings. Compiler changes fail closed until
you intentionally update the digest. Layer/profile/template/macro settings must
match your build. Imports and footprint resolution remain locked/offline.

Build shared assets with `node integrations/vscode/build.cjs`, then launch an
Extension Development Host with `code --extensionDevelopmentPath=<absolute
build/vscode-extension/extension> <project-directory>`. On a `.copper` tab use
**Reopen Editor With → CopperScript Mechanical / Floorplan**. It is not the default
text editor. Select a component and **Show component source declaration** to open
its root declaration (or hierarchical instance) beside the board view.

Review source edits and choose Save reviewed source. Native document changes
invalidate old previews; invalid text remains editable in the regular text view
and can recover on the next valid document version. Native Undo/Redo restores
source, while temporary placement history is separate. A failed save leaves the
reviewed native edit dirty and undoable, rather than writing around VS Code.

This host deliberately uses VS Code's [custom text editor API](https://code.visualstudio.com/api/extension-guides/custom-editors)
and [workspace trust](https://code.visualstudio.com/api/extension-guides/workspace-trust).
Routed-reference import is currently available in the standalone host; advanced
mechanical formats remain governed by the main editor checklist.

Offline installable artifact (no npm/marketplace build dependencies):

```sh
node integrations/vscode/build.cjs
python integrations/vscode/package.py -o build/copperscript-mechanical.vsix
code --install-extension build/copperscript-mechanical.vsix
```

Packaging uses fixed archive timestamps and whitelisted runtime assets. Existing
VSIX files are never overwritten. CI publishes the staged extension as an artifact
and includes it in tagged inspection releases. This does not publish to Marketplace.

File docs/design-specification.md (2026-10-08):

# CopperScript design specification

**Status:** Draft specification with accepted architectural decisions
**Applies to:** CopperScript language, compiler, IRs, rule engines, and backends
**Last updated:** 2026-10-06

This document records the durable design decisions for CopperScript. It is the
normative architectural reference; the README explains usage and the language
reference describes current syntax.

The terms **MUST**, **MUST NOT**, **SHOULD**, and **MAY** express requirement
strength. Sections marked "Current implementation" describe temporary reality
and do not override the target architecture.

## 1. Purpose

CopperScript is a semantic language for electronic design. Authors describe
components, connectivity, electrical intent, and constraints. Tooling derives
validation results, exchange artifacts, and eventually physical layouts.

The central principle is:

> Describe electrical intent and constraints explicitly. Describe geometry only
> where physical geometry is itself the intent.

CopperScript is not a textual encoding of a schematic drawing application and
must not become one.

## 2. Architectural domains

The compiler architecture separates four domains:

```text
CopperScript source
        |
        v
+----------------------+       +----------------------+
| Electrical design IR |       | Constraint set       |
| parts, instances,    |<------| rules and targets    |
| nets, supplies,      | refs  | no connectivity      |
| interfaces           |       | ownership            |
+----------------------+       +----------------------+
        |                               |
        +---------------+---------------+
                        v
                +------------------+
                | Layout engine    |
                +------------------+
                        |
                        v
                +------------------+
                | Physical IR      |
                | placement,       |
                | routing, stackup |
                +------------------+
```

Schematic presentation is not another authoritative IR domain. It is a backend
artifact derived from the electrical design.

### 2.1 Electrical design IR

The electrical IR defines what the circuit is. It MAY contain:

- reusable part and pin definitions;
- package-independent device pads, electrical profiles, functional units,
  signal groups, power domains, peripherals, and route rules;
- component instances and selected footprints;
- explicit peripheral and pin-mux selections;
- nets and their endpoints;
- supplies, nominal voltages, and power sources;
- named discrete power states for analysis;
- protocol interfaces and their signal bindings; and
- typed electrical properties required for validation or generation.

It MUST NOT contain:

- schematic symbol coordinates or rotations;
- wire paths, junction drawing positions, or label positions;
- pages, sheets used only for drawing organization, title blocks, or view state;
- colors, fonts, zoom, selection, or other UI state;
- PCB placement, routing, board-outline, stackup, zone, or via geometry; or
- backend-specific object identifiers when they can be derived deterministically.

### 2.2 Constraint set

Constraints express requirements on a design; they do not define connectivity.
The compiler MUST lower constraints into a logically separate `ConstraintSet`
that refers to electrical objects through stable semantic references.

Changing or removing a constraint MUST NOT silently add, remove, or reconnect a
net endpoint. Conversely, moving a component between nets MUST require an
explicit connectivity edit rather than a constraint change.

Constraints MAY cover multiple domains, including:

- electrical limits, such as voltage, current, impedance, or timing;
- placement requirements, such as maximum distance or keep-together groups;
- routing requirements, such as width, clearance, topology, or length matching;
- manufacturing requirements; and
- advisory notes that remain machine-addressable.

Constraints SHOULD be declarative and typed. A constraint states the required
outcome, not a sequence of operations for producing it.

Source syntax MAY place constraints near related declarations for readability,
but source proximity MUST NOT merge their semantic ownership with connectivity.

### 2.3 Physical layout IR

The physical IR will describe one concrete realization of an electrical design.
It MAY contain board outline, stackup, component placement, footprint geometry,
tracks, vias, copper zones, and other fabrication geometry.

The physical IR MUST be a separate model generated from:

1. the electrical design IR;
2. the constraint set;
3. selected library and fabrication data; and
4. layout-engine decisions.

PCB coordinates belong here. Schematic drawing coordinates do not.

The physical IR MUST retain traceable references to the electrical objects it
implements. A track, pad, or zone may identify a net; it must not redefine that
net's logical membership.

The initial physical IR uses integer nanometres for coordinates and dimensions
so backend output is deterministic and does not accumulate binary floating
point error. It contains a closed polygonal board outline, stackup, basic design
rules, resolved footprint geometry, placements, physical net-to-pad mappings,
track segments, and vias. Physical objects use stable electrical component and
net names for traceability.

The model validates its internal references independently of any backend. A
placement must resolve a footprint, a net endpoint must resolve an existing
placement and pad, and copper geometry must resolve a physical net and stackup
layer. This structural validation is not a substitute for geometric DRC.

### 2.4 Presentation and tool artifacts

Backends MAY generate coordinates and other presentation data required by a
target format. Such data is backend-owned and MUST NOT flow back into the
electrical IR merely because a target application requires it.

For example, a KiCad schematic backend may arrange symbols on a grid and place
net labels. Those positions are rendering decisions, not CopperScript design
semantics.

## 3. Core semantic decisions

### 3.1 Connectivity has one source of truth

`Net.endpoints` is the canonical connectivity definition. Components, supplies,
interfaces, constraints, and backend renderings MUST NOT create a second
connectivity mechanism.

The compiler MUST reject or diagnose a pin assigned to more than one net.

### 3.2 Parts and component instances are distinct

A `PartDefinition` describes reusable facts about a part: pins, electrical pin
capabilities, device-pad bonds, limits, manufacturer data, and compatible
physical packages.

A `ComponentInstance` describes use of that part in one design: reference,
value, chosen footprint, and instance properties.

Backend symbol bindings and library lookup information SHOULD live in explicit
adapter or library metadata rather than in user-authored connectivity.

### 3.3 Supplies are explicit semantic objects

A supply annotates an existing net with voltage and sourcing information. It
does not create the net or connect pins implicitly.

Power-source validation and voltage-range checking consume supply annotations.
Ground is not a special parser primitive; it is a named supply/net with explicit
semantics.

### 3.4 Interfaces overlay connectivity

Interfaces describe protocol-level meaning, such as I²C signal roles and device
bindings. They refer to existing nets and pins and MUST NOT duplicate or replace
net membership.

Protocol-aware checks MAY require supporting components, such as I²C pull-up
resistors, by examining ordinary components and nets.

### 3.5 Quantities are typed

Physical values MUST carry dimensions. Units are normalized internally while a
display unit may be retained for diagnostics and serialization.

Cross-dimension operations, such as comparing voltage with resistance, MUST be
rejected. Backends MUST NOT infer a unit from an untyped number where the
language requires a physical quantity.

### 3.6 References are semantic, not positional

Components, nets, interfaces, and constraints refer to stable semantic names or
IDs. Source offsets and generated coordinates are provenance or presentation;
they are not design identity.

Renaming support should eventually update all semantic references through the
compiler model rather than textual search and replace.

### 3.7 Hierarchy is reusable electrical structure

A module defines a reusable electrical design with typed boundary ports. A port
MUST connect to exactly one internal net, and a parent connects a module instance
through ordinary net endpoints. Ports therefore expose connectivity without
creating a second connectivity system.

Modules MAY instantiate other modules. Circular imports or instantiation cycles
MUST be rejected.

The authoritative electrical IR MUST preserve module definitions, module
instances, typed ports, local component and net names, and boundary connections.
A module definition MUST be represented once regardless of how many times it is
instantiated. Compilation MUST NOT replace this structure with a flattened
netlist.

Hierarchy elaboration is an explicit derived operation. It MAY produce
deterministic qualified identities such as `PWR/U1` for ERC, global analysis, or
backends that need a flat connectivity view. The derived view MUST NOT become
the source of truth and MUST NOT be required by hierarchy-aware backends.

Constraints declared inside a module are instantiated and qualified with that
module. They remain in the constraint domain rather than becoming part of the
module's connectivity definition.

### 3.8 Packages have stable source identities

Reusable parts and modules are shared through packages identified by URL-like
paths such as `github.com/vendor/library/sensors`. Source files import a package
under a local alias and refer to its exports through qualified names. An import
path identifies source; it does not select a version.

Dependency versions and local development replacements MUST live in the
project-level `copper.mod`, not in individual source imports. Downloaded module
content MUST be authenticated by `copper.sum`. All resolved dependencies,
including mutable local replacements, retain their current content hash as
compiled IR provenance. A package is declarative: the compiler parses `.copper`
definitions and MUST NOT execute dependency-provided code.

Resolution uses the longest required module-path prefix. v0.1 supports GitHub
Git repositories and explicit local `replace` directives; this may later be
generalized without changing source import identity.

Reusable production part, device, footprint, and circuit-module definitions
MUST be maintained in the separate CopperLib project, whose stable module path
is `github.com/andenore/CopperLib`. The CopperScript compiler repository MAY
contain deliberately tiny built-in fixtures and compiler tests, but product
examples MUST consume newly created reusable definitions from CopperLib rather
than duplicate them locally. Local development uses an explicit `copper.mod`
replacement for the sibling CopperLib checkout.

### 3.9 Complex devices separate capabilities from packages

Complex programmable parts such as MCUs MUST distinguish three concepts:

- a package-independent `DeviceDefinition` describing named silicon pads,
  power domains, peripherals, peripheral signals, mux options, and shared
  configuration resources;
- a `PartDefinition` describing one orderable/package variant, its physical
  package pins, and explicit bonds from those pins to device pads; and
- a `PeripheralSelection` describing the explicit mux choices made for one
  component instance.

A device pad and a physical package pin are different identities. A mux option
maps a device pad to one peripheral signal and retains the target-specific
selector needed by a backend, such as `AF6`. A package pin may bond to one or
more device pads, and multiple package pins may bond to the same logical pad
where the package requires it. ERC resolves a selected package pin through its
declared bonds before validating mux availability.

Physical pins and device pads use an `ElectricalProfile` rather than one pin
type or capability bag. Signal domains, directions, drive modes, extensible
traits, and typed ranges are orthogonal. A pad may therefore be analog and
digital, bidirectional, and support both push-pull and open-drain drive without
inventing a combined enum value. Protocol signals declare required profiles;
ERC checks that a selected physical endpoint satisfies them.

Part categories and interface type names are open strings. Standard meanings
use the `std.` namespace, while dependency packages may define namespaced
vocabulary. Generic ERC MUST consume typed fields rather than infer behavior
from an unknown taxonomy string.

Functional units are package-independent semantic views over device pads. A
unit terminal resolves through its pad and package bonds to one canonical
physical pin. Source endpoints MAY use paths such as `U1.A.OUT`; connectivity
and pin-on-multiple-net checks operate on the resolved physical identity. Units
do not create connectivity and may guide backend presentation without adding
schematic geometry to IR.

Signal groups describe relationships such as positive and negative members of
a differential pair. Package pins carry explicit normal, required,
do-not-connect, or optional connection policy and may require net traits such
as `ground`. These are structural electrical rules, not name-based heuristics.

Finite mode groups and equality-only conditions control pad, bond, group, or
route availability. A component makes an explicit choice or uses a declared
default. General boolean expressions and conditions derived from connectivity
are not part of the language.

An optional, physically numbered package pin may have no electrical profile
while its function is unresolved. It is a structural placeholder only: ERC
must reject any net attached to it. This separates complete land-pattern
coverage from evidence-backed electrical modeling.

Explicit mux rows remain appropriate for irregular mappings such as STM32
alternate functions. Regular routing such as Nordic PSEL uses concrete named
pad sets and a typed selector scheme, avoiding an N-by-M expansion while still
retaining a deterministic concrete selection in compiled IR.

Optional resource and setting fields express device-wide configuration state.
Selections are exclusive by default. Exclusive selections requiring different
settings for the same resource conflict; multiple signals requiring the same
setting are compatible. A selection explicitly marked `firmware_managed` MAY
share a peripheral, pin, or resource only when every conflicting selection is
also firmware-managed. This
waiver suppresses only resource-ownership conflicts: unknown pads, invalid mux
options, missing required signals, and electrical incompatibilities remain
errors. A design may omit peripheral configuration and use a pin as ordinary
GPIO when detailed firmware mode checking is not useful.

Peripheral configuration annotates component behavior and MUST NOT create or
modify net connectivity. A configured pin is connected only by appearing as a
net endpoint. This preserves nets as the single source of electrical
connectivity.

v0.1 requires explicit pin assignments. Automatic pin assignment MAY later be
implemented as constraint solving, but its result MUST lower to the same
concrete `PeripheralSelection` IR and retain every selected pin and mux
selector. Device packages are declarative data. Source document, revision,
location, URL, and checksum are optional metadata and MUST NOT be required for
compilation. Generated production libraries SHOULD retain such provenance when
available so data can be audited; hand-authored or experimental definitions may
omit it.

### 3.10 Power domains and discrete power states

Device pads MAY belong to named power domains. Each domain identifies the
device supply pads that establish its powered state. I/O pads may also declare
their unpowered behavior as `high_impedance`, `tolerant`, `clamped`, or
`unknown`.

A board MAY define named power states by assigning each relevant `Supply` the
state `on`, `off`, or `unknown`. Power states annotate the existing electrical
design; they MUST NOT create rails, sources, switching connections, or implicit
net membership. Modules do not own board-level power scenarios in v0.1.

Power-state analysis is a separate IR consumer from ordinary ERC. The v0.1
analyzer performs conservative steady-state checks, including warning when a
driven net reaches a clamped or unknown I/O pad whose domain is off. It does not
simulate firmware, analog transients, ramp timing, regulator dynamics, or the
internal behavior of power switches. Later sequencing and transition models
MUST build on the same explicit domains and states rather than embedding a
hidden simulator in connectivity checking.

### 3.11 Generated device libraries use compact normalized data

Large devices SHOULD be maintained as normalized metadata and tables rather
than hand-authored repetitive CopperScript. The repository generation workflow
uses JSON for device/package metadata and CSV for pads, pins, peripheral
signals, and mux options. Deterministic tooling validates references and emits
ordinary `.copper` definitions; generated source remains declarative and is
compiled through the same frontend as hand-written packages.

The normalized bundle is authoritative library input. Generated CopperScript
MUST be reproducible and SHOULD carry a generated-file notice. CI SHOULD fail
when checked-in generated files differ from the bundle.

Unknown or disputed extracted values use an explicit marker and MUST block
generation. Tooling SHOULD produce small work packets containing only selected
or unresolved rows plus the relevant enum vocabulary and optional provenance.
This permits datasheet agents to work on bounded tables without repeatedly
loading complete devices or emitting repetitive syntax.

Machine-readable vendor data SHOULD be preferred over PDF extraction. Source
provenance remains optional as required by CS-027, but generators SHOULD retain
it whenever available. Generation tooling MUST NOT execute dependency-provided
code.

## 4. Language and compiler

`.copper` is the only user-facing source format. Executable Python is permitted
only in internal tests and development fixtures.

The compiler pipeline is:

```text
UTF-8 source
    -> lexer
    -> source-aware syntax tree
    -> semantic lowering
    -> electrical IR + constraint set
    -> ERC and constraint validation
    -> one or more backend artifacts
```

Each stage SHOULD have a narrow API and be independently testable. Parsing MUST
NOT perform backend generation. Backends MUST NOT reparse CopperScript source.

Diagnostics MUST have stable machine-readable codes. Syntax and semantic
diagnostics SHOULD include source spans. ERC diagnostics must eventually map
back to the declaration or reference that caused them so a language server can
publish precise editor diagnostics.

Compilation MUST be deterministic for identical source, libraries, compiler
version, and options.

## 5. Validation

Electrical-rules checking is a consumer of the electrical IR, not parser logic.
It SHOULD remain usable by tests, editor tooling, importers, and backends.

ERC currently covers unknown references, duplicate references, pins on multiple
nets, conflicting outputs, supply voltage limits, unsourced power inputs, basic
I²C rules, and explicit device mux selections. Device checks include package-pin
availability, required peripheral signals, valid mux choices, exclusive pin and
peripheral use, electrical compatibility, and shared resource settings. New
checks SHOULD be independent passes with stable diagnostic codes.

Discrete power-state analysis is also an independent IR pass. It reports
unknown state rails and possible back-power paths without changing electrical
validity or connectivity. Firmware-managed sharing waives ownership conflicts,
not structural or electrical validation.

Constraint validation is distinct from ERC even when both run under `copper
check`. This separation allows electrical validity, constraint consistency, and
physical feasibility to be reported independently.

A backend MUST NOT silently repair an invalid electrical design. Generation may
stop on errors or proceed only through an explicit diagnostic/testing option.

## 6. Backend architecture

A backend consumes compiled semantic models and produces named artifacts. It
MUST NOT mutate the electrical IR or constraint set.

Conceptually:

```text
Backend.generate(
    electrical_design,
    constraint_set,
    backend_options,
) -> ArtifactManifest
```

An artifact manifest may contain one or more files, warnings, target-version
metadata, and provenance.

Target-specific names, symbol mappings, file versions, and generated UUIDs
belong in the backend or its adapter registry. They SHOULD NOT leak into the
core electrical model unless they represent genuine cross-backend semantics.

Backends SHOULD generate stable ordering and deterministic identifiers so small
source changes produce reviewable diffs.

### 6.1 KiCad schematic backend

The first external backend generates a KiCad schematic as an
interoperability artifact. Its goals are to:

- validate that CopperScript electrical semantics map to a real EDA tool;
- provide a visual, inspectable schematic;
- carry references, values, footprints, nets, and labels into KiCad; and
- support KiCad's normal schematic-to-PCB workflow.

It is not a layout engine and MUST NOT introduce schematic coordinates into the
electrical IR.

The initial implementation:

- targets KiCad 8 and schematic format `20231120`;
- creates embedded generic symbols from CopperScript part definitions, with a
  future adapter layer responsible for mappings to standard KiCad libraries;
- creates deterministic, version-4-shaped UUIDs from stable semantic identity;
- uses a simple backend-local grid arrangement;
- uses short pin stubs and named net labels instead of aesthetic wire routing;
  and
- verifies generated artifacts through deterministic fixtures and should also
  use KiCad tooling when it is available.

The first revision emits one flat sheet by explicitly elaborating the compiled
hierarchy. Qualified CopperScript instance paths are retained in hidden
`CopperScriptPath` properties when they cannot be used directly as KiCad
references. This is an interoperability limitation, not a change to the
authoritative hierarchical IR. Native KiCad sheets are planned after the basic
artifact path is proven.

The generated schematic is not the source of truth. Round-trip import and
back-annotation are outside the first implementation and require a separate
design decision.

### 6.2 KiCad PCB backend

A KiCad PCB backend consumes the physical IR, not schematic drawing data. It
serializes placement and routing decisions while preserving references to
electrical nets and components.

Generating an unrouted board skeleton directly from the electrical IR MAY be a
useful intermediate feature, but any automatically chosen placement belongs to
backend output or physical IR, never to the electrical IR.

The initial implementation:

- targets KiCad 8 board format `20240108`;
- emits embedded footprint pads and simple body outlines rather than relying on
  the receiving installation's footprint libraries;
- emits physical net assignments, track segments, vias, and a closed
  `Edge.Cuts` outline;
- uses deterministic, version-4-shaped UUIDs derived from stable object
  identity; and
- accepts only `PhysicalBoard`, making the electrical/physical boundary
  explicit in its public API.

The temporary physicalization adapters are not placement engines. The normal
path resolves verified footprints and creates deterministic grid placement;
`prototype_physicalize` additionally creates generic proxy pads only when the
caller explicitly requests that development fallback. Both outputs MUST be
marked as not fabrication-ready, and the backend MUST report the remaining
placement/routing limitations as warnings.

### 6.3 Physical-design workflow

The user-visible physical-design workflow has exactly four gates: Prepare,
Place, Route, and Verify. Detailed activities such as floorplanning, global
placement, legalization, local refinement, and routability estimation are
internal Place substeps rather than independent public phases. Global corridor
and layer assignment, detailed routing, rip-up/reroute, and tuning are Route
substeps. DRC, electrical/thermal/RF analysis, DFX, and CAM inspection are
independently reportable Verify checks.

A completed Place gate MUST mean that all represented components are inside the
board and satisfy represented component-clearance constraints. It SHOULD include
a coarse global-routing estimate so congestion can feed back into placement.
Such an estimate MUST NOT be represented as routed copper. Route remains not run
until geometrically valid tracks and vias exist, and Verify MUST remain blocked
until required sign-off checks have passed.

Placement MUST consume typed physical constraints rather than interpreting
source text. The physical IR represents courtyard geometry, keepouts, placement
regions, fixed placement, legal orientations, minimum/maximum distance,
alignment, and semantic groups. Groups derived from preserved module hierarchy,
interfaces, and proximity constraints provide soft clustering intent without
changing electrical connectivity.

Reference-layout macros are separate **hard rigid physical clusters**. Their
member poses MUST be bound to resolved footprint geometry and source identity,
with an explicit evidence locator and anchor physical pad/origin. Translation
and permitted rotation MUST preserve all local poses and layer-scoped keepouts.
Fixed members freeze the unit; conflicting fixed poses, unsupported mirroring,
incompatible footprints or overlap between rigid clusters MUST fail closed.
Ordinary legalization, refinement and placement/routing feedback MUST NOT split
a macro. No electrical net/pin mapping changes with a physical transform.

An explicit physical scene MAY bind a content-addressed vendor reference to
resolved footprint hashes and declared physical pad/net roles. This binding MUST
be data-only, reject mismatches and unknown rules, and leave connectivity in the
electrical source. A source locator's local filesystem path is not asset identity.
An explicit internal macro courtyard gap MAY differ from the ordinary additional
gap; non-overlap, external spacing and all copper/fabrication checks still apply.
Provisional footprint adaptation MUST NOT be reported as reference-layout or RF
qualification. See
[rigid-placement-clusters.md](rigid-placement-clusters.md) for the initial API,
bounded-search limitations and separation from RF qualification.

The initial placement engine uses deterministic multi-seed analytical global
placement, hybrid discrete legalization, hard relative-rule repair, and legal
local refinement with coarse per-layer routing feedback. Wirelength and
routability metrics use transformed footprint pads. Multiple legal results are
Pareto-filtered and deterministically ranked; reports MUST retain both the
selected result and candidate metrics. Proxy crossings, vias, pin escape, and
congestion are estimates only and MUST NOT be serialized as routed copper.
High-pin-count packages receive a soft escape-channel spacing objective,
measured between placed courtyards. It may use free board area but MUST NOT
override fixed positions, board/keepout legality, or relative constraints;
close-placement companions move together when a legal cluster translation
improves the score. Spacing remains a placement heuristic, not a routing
guarantee.

Automated placement and routing artifacts MUST retain their algorithm identity,
gate state, metrics, and non-fabrication-ready status. See
`docs/layout-workflow.md` for the researched algorithm choices and implemented
scope.

### 6.4 Footprint importers

External footprint formats are adapters into `PhysicalFootprint`; they are not
alternate physical IRs. Importers MUST normalize exact geometry, retain source
identity and checksum metadata, and report every unsupported construct. They
MUST reject fabrication-relevant geometry that cannot be represented rather
than silently approximating or dropping it.

The KiCad `.kicad_mod` importer parses KiCad 6–10 S-expressions without
executing code or requiring KiCad. It supports ordinary SMD and through-hole
pads, circular and slotted drills, pad rotations, mask and paste layer presence,
paste-only apertures, per-pad zone/heatsink/layer-removal properties,
footprint-local clearance, round-rectangle ratios, and common footprint drawing
primitives including mask and paste artwork. Simple footprint-local copper
keepouts are typed, transformed with each placement (including back-side
mirroring), conservatively excluded from routing grids, checked against exact
copper geometry in DRC, signed with the geometry, and emitted
as deterministic KiCad board zones. Active footprint-placement keepouts,
connected footprint zones, and polygon holes remain unsupported and fail
closed. Ignored
presentation-only constructs produce warnings, and strict mode promotes all
warnings to errors. Custom pads, copper graphics, drill offsets, and
unsupported fabrication modifiers are errors until the physical IR can retain
them losslessly.

Board-level `PlacementKeepout` constrains component placement only; it is not a
copper obstacle for global or detailed routing. Only typed copper keepouts may
block tracks and vias. The two keepout classes must not be conflated.

Footprint selection and footprint resolution are separate phases. The
electrical IR retains the user-selected string; physical lowering resolves it
through a dedicated adapter. A direct `.kicad_mod` path is relative to the
board source. A KiCad `Library:Footprint` identifier is searched only in
explicit caller-provided roots. The resolver MUST NOT inspect an installed EDA
tool's implicit library configuration because that would make builds
machine-dependent. No match and multiple matches are both errors.

The selected name MUST agree with the name declared inside the footprint file.
Before placement, the set of non-empty electrical pad numbers MUST exactly
match the part's physical pin numbers. Duplicate footprint primitives sharing
one pad number are allowed, and unnumbered non-plated mounting holes are ignored
for electrical matching. Proxy geometry requires explicit opt-in and MUST
remain marked as non-fabrication-ready.

Repeated physical lands with one pad number are one logical electrical pin,
but they remain distinct copper objects for layout and independent KiCad DRC.
The PCB flow SHOULD bridge them with exact-clearance copper where legal and
MUST report any unbridgeable lands as pending. Existing exact copper paths on
any common physical layers MUST be reused rather than demanding a redundant
surface bridge. Land closure MUST precede full/subset candidate scoring and
its actual added copper MUST be measured. Native checking MUST include multiple
physical lands even when a net contains just one logical pad reference.
It MUST NOT interpret a shared
pad number alone as proof that all lands are externally connected. A future
explicit, qualified internal-tie declaration may avoid unnecessary copper,
but no such waiver is implied by the current footprint importer.

## 7. Serialization and versioning

Serialized IR MUST declare a schema identifier and version. Readers MUST reject
unsupported incompatible schema versions rather than guessing.

The default serialized electrical IR MUST preserve hierarchy. A serialized flat
view, if offered for debugging or interoperability, MUST be clearly identified
as derived and non-authoritative.

Serialization SHOULD be stable and suitable for testing, inspection, and tool
integration. It is a compiler artifact, not necessarily the long-term source
format.

Backend artifacts MUST identify CopperScript as their generator where the
target format provides such a field.

## 8. Non-goals for v0.1

The following are deliberately outside the current scope:

- production-ready automatic PCB placement and routing;
- copper pours and direct fabrication output;
- schematic beautification beyond a deterministic basic rendering;
- importing arbitrary KiCad projects into CopperScript;
- lossless round trips through external EDA tools;
- advanced design variants and parameterized/generic modules; and
- global component sourcing or lifecycle management.

These exclusions prevent target-tool details from distorting the language
before its semantic core is stable.

## 9. Current implementation and required refactoring

The current `Board` dataclass combines electrical objects and a `constraints`
tuple. This is transitional. Before physical-layout work expands, it SHOULD be
replaced by a package-level result similar to:

```text
CompiledDesign
  electrical: ElectricalDesign
  constraints: ConstraintSet
```

The current constraint syntax may remain unchanged; the separation is semantic
and architectural, not necessarily visual in source.

Footprint strings are opaque selections in electrical IR. The physical
resolver interprets explicit `.kicad_mod` paths and KiCad library identifiers;
the KiCad PCB backend itself receives only normalized physical IR.

## 10. Open design questions

These questions are intentionally unresolved:

- Should stable identities be explicit in source or derived from qualified
  semantic paths?
- Should stable hierarchical identities remain path-derived if instances are
  renamed, or should source-level persistent IDs be introduced?
- Can separate constraint-profile files override or extend inline constraints?
- What is the serialized schema for the physical IR?
- Which external-tool edits, if any, are safe to back-annotate?
- How are multiple footprint candidates selected before layout?

An open question MUST NOT be treated as an implicit decision by a backend.

## 11. Decision log

| ID | Status | Decision |
|---|---|---|
| CS-001 | Accepted | CopperScript describes semantic intent, not drawing primitives. |
| CS-002 | Accepted | `.copper` is the sole user-facing source format. |
| CS-003 | Accepted | Net endpoint lists are the single source of connectivity. |
| CS-004 | Accepted | Part definitions and component instances are separate concepts. |
| CS-005 | Accepted | Physical quantities are dimensioned and unit-aware. |
| CS-006 | Accepted | Supplies and interfaces annotate existing connectivity. |
| CS-007 | Accepted | Constraints are semantically separate from electrical connectivity. |
| CS-008 | Accepted | Electrical IR contains no schematic UI or presentation coordinates. |
| CS-009 | Accepted | PCB geometry belongs in a separate physical IR. |
| CS-010 | Accepted | Backends are target-specific consumers of compiled models. |
| CS-011 | Accepted | Backend-generated identifiers and output are deterministic. |
| CS-012 | Accepted | KiCad schematic generation is the first interoperability backend. |
| CS-013 | Accepted | Generated schematics are artifacts, not authoritative design input. |
| CS-014 | Accepted | ERC remains independent of parsing and backend generation. |
| CS-015 | Accepted | Serialized IR is explicitly schema-versioned. |
| CS-016 | Accepted | Modules expose typed ports through ordinary net endpoints. |
| CS-017 | Accepted | The authoritative IR preserves hierarchy; flattening is an explicit, non-authoritative derived view. |
| CS-018 | Accepted | Reusable parts and modules are imported from URL-like package paths under explicit local aliases. |
| CS-019 | Accepted | Dependency versions and local replacements belong in `copper.mod`, not source imports. |
| CS-020 | Accepted | Downloaded package content is verified by `copper.sum`; all dependencies retain hash provenance and dependency code is never executed. |
| CS-021 | Accepted | Package-independent device capabilities are distinct from package-specific physical part pins. |
| CS-022 | Accepted | Peripheral configuration annotates pin behavior and never creates connectivity; nets remain authoritative. |
| CS-023 | Accepted | Explicit mux selections lower to typed IR containing concrete pins, selectors, and shared resource settings. |
| CS-024 | Accepted | Automatic pin assignment is deferred and must eventually lower to the same explicit selection IR. |
| CS-025 | Accepted | Device pads and physical package pins are distinct identities connected by explicit bonds; mux options name device pads. |
| CS-026 | Accepted | Physical pins and device pads carry capability sets rather than one mutually exclusive electrical pin type. |
| CS-027 | Accepted | Source-document and revision provenance is optional; production generators should retain it when available. |
| CS-028 | Accepted | Peripheral selections are exclusive by default; `firmware_managed` suppresses ownership/resource-sharing conflicts but not structural or electrical validation. |
| CS-029 | Accepted | Power domains and named discrete rail states are explicit IR, analyzed by a separate conservative steady-state pass. |
| CS-030 | Accepted | The initial schematic backend targets KiCad 8 format `20231120`, owns all presentation geometry, embeds generic symbols, and explicitly derives a flat single-sheet artifact. |
| CS-031 | Accepted | Large device libraries use compact normalized JSON/CSV bundles and deterministic source generation; unresolved values block generation and bounded work packets minimize extraction context. |
| CS-032 | Accepted | Electrical profiles separate signal domains, directions, drive modes, traits, and typed ranges. |
| CS-033 | Accepted | Part categories and interface type names are open; generic behavior depends on typed semantics, not taxonomy strings. |
| CS-034 | Accepted | Functional-unit terminals resolve to canonical physical pins and never create connectivity. |
| CS-035 | Accepted | Signal groups represent differential and other multi-signal relationships independently of protocols. |
| CS-036 | Accepted | Package pins have typed connection policies, required net traits, and conditional bonds. |
| CS-037 | Accepted | Device modes are finite named choices and conditions are conjunctions of equality selections. |
| CS-038 | Accepted | Regular pin routing uses concrete pad sets and selector schemes; irregular mappings retain explicit mux options. |
| CS-039 | Accepted | The physical IR is a backend-neutral immutable model using integer nanometres, validated references, and traceability to electrical component and net identities. |
| CS-040 | Accepted | The KiCad PCB backend consumes only physical IR and initially targets KiCad 8 format `20240108`; prototype proxy footprints are explicitly non-fabrication-ready. |
| CS-041 | Accepted | Footprint importers normalize external files into physical IR, retain checksum provenance, and fail instead of silently losing unsupported fabrication geometry. |
| CS-042 | Accepted | Footprint resolution is explicit and deterministic: board-relative files or caller-provided library roots only; ambiguity and electrical pad mismatches are errors. |
| CS-043 | Accepted | CopperLib is the canonical project for new reusable part, device, footprint, and circuit-module definitions; product examples import them rather than duplicating them in the compiler repository. |
| CS-044 | Accepted | Physical design exposes four gates—Prepare, Place, Route, Verify. Placement includes legalization and routability feedback; estimates never masquerade as routed copper, and release remains blocked until routing and sign-off pass. |
| CS-045 | Accepted | Placement consumes typed physical constraints and preserved semantic hierarchy, then uses deterministic analytical global placement, hybrid legalization, pad-aware route feedback, detailed refinement, and Pareto-ranked candidates. |
| CS-046 | Accepted | Global routing uses deterministic multilayer capacity guides and negotiated congestion; guides and proposed vias are planning artifacts and only detailed routing may create physical copper. |
| CS-047 | Accepted | Placement–routing feedback is transactional: only complete global-route improvements are accepted, rejected moves roll back atomically, and a fresh full reroute is required for certification. |
| CS-048 | Accepted | Critical nets route before ordinary nets from explicit physical profiles; coupled bundles and exact locked copper retain external qualification assumptions, and geometric proxies never claim impedance, SI, RF, current, or thermal signoff. |
| CS-049 | Accepted | General detailed routing consumes global guides, preserves locked critical copper, owns exact tracks and vias, and reroutes in bounded deterministic passes. Each net's pad-aware grid uses physical-coordinate resource identities. Foreign-net and unconnected pads and locked copper are immutable geometric obstacles. Existing ordinary routes may be tentatively crossed only for a transactional rip-up proposal; the proposal is committed solely if all displaced nets reroute and exact clearances hold. Congestion costs alone cannot legalize overlapping copper. Routing success never substitutes for physical DRC. |
| CS-050 | Accepted | Physical signoff is fail-closed and reports check coverage separately from findings; exact waivers are fingerprint-bound, and every signoff token is content-bound to the complete physical geometry, rules, policy, and report. |
| CS-051 | Accepted | Manufacturing releases use a qualified KiCad CLI as the geometry exporter, require a matching complete signoff token, generate Gerber X2 plus metric drill and IPC-D-356 data, and publish atomically only after independent CAM parsing, manifesting, and checksums succeed. |
| CS-052 | Accepted | Routing stages compose in one direction through immutable typed results: global guides, locked critical copper, general exact copper, physical DRC, then manufacturing; a partial or stale result cannot satisfy a later gate. |
| CS-053 | Accepted | Copper zones and keepouts are typed physical intent. CopperScript owns their deterministic identity, rules, and freshness fingerprint; a pinned KiCad refill is the authoritative manufacturing fill until a native filler passes differential qualification. Stale or missing required fill evidence blocks release. |
| CS-054 | Accepted | Routing and physical DRC share deterministic integer geometry predicates. Interactive shove operations are transactions: recursive movement commits only when the complete result is legal, while locked-object or boundary conflicts return the original immutable board. |
| CS-055 | Accepted | A differential pair is one atomic routed object. Signoff measures coupled and uncoupled portions, skew, and geometrically paired transitions; impedance remains an explicitly external claim. |
| CS-056 | Accepted | Stackups are ordered physical copper/dielectric constructions. Vias select a named fabrication technology whose span, drill, annular-ring, aspect-ratio, and microvia-adjacency limits are validated and exported consistently. |
| CS-057 | Accepted | Fabrication, stencil, assembly, engineering-analysis, and CAM qualification are separate gates. Process limits carry source/revision provenance; engineering results state evidence grade, scope, and validity; unavailable required evidence yields `incomplete` or `blocked`, never an optimistic pass. |
| CS-058 | Accepted | Every normalized hard or external constraint has named downstream consumers and a verifier. Missing ownership or results block release. Soft preferences may affect scoring but cannot weaken a hard requirement. |
| CS-059 | Accepted | Independent CAM tools are identified by exact version and executable digest. Production qualification compares normalized semantics from the required tool tuple over the exact hashed staged bytes; parser disagreement fails and a missing capability is incomplete. |
| CS-060 | Accepted | Coupled route shoves expand collisions by complete net so pair/bus geometry moves atomically. Locked conflicts roll back the immutable transaction; deterministic acute-angle cleanup may replace only a safe degree-two spike and remains subject to physical DRC. |
| CS-061 | Accepted | Differential-pair completion uses bounded local tuning, paired layer transitions, and explicitly bounded return vias. External impedance evidence is content-addressed and suppresses only the corresponding unqualified-model warning; geometric DRC remains mandatory. |
| CS-062 | Accepted | Physical DRC normalizes copper to integer point/segment/polygon spines swept by exact radii, uses a stable spatial broad phase and exact rational narrow-phase decisions, checks normalized zone fills and concave boundaries, and guarantees incremental results equal the authoritative full run. Unsupported copper primitives fail at import rather than being approximated. |
| CS-063 | Accepted | Fabrication, stencil, and assembly DRC derive mask, paste, silk, drill/slot, courtyard, orientation, edge-plating, height, and outer-layer balance evidence from normalized physical assets under a provenance-bearing process profile. Required unsupported artwork yields `incomplete`, and manufacturing profiles may require all three gates to pass. |
| CS-064 | Accepted | Engineering analyses always report status, evidence grade, claim scope, validity limits, and any report digest. Analytical impedance/delay, return-path, DC/via drop and reduced-order thermal results are screening evidence; only explicit content-addressed external reports may claim external-solver evidence. |
| CS-065 | Accepted | CAM qualification adapters parse the exact staged bytes under an exact executable identity. The release profile may require a pinned multi-parser PASS; missing tools/capabilities are incomplete and parser disagreement fails publication. PyGerber is pinned as a semantic parser; subprocess-isolated libgerbv re-exports RS-274X for normalization through the same rendering path. |
| CS-066 | Accepted | `copper.lock` content-addresses local replacements and remote modules alike with a canonical per-file asset inventory. Production uses `--locked --offline`; missing entries, byte drift, symlinks, and remote cache misses fail closed. |
| CS-067 | Accepted | Source `routing` constraints lower directly to `NetRoutingRule`, including critical-net geometry, layers, pair/return-path limits, and content-addressed impedance evidence. Constraint ownership metadata survives semantic and serialized IR. |
| CS-068 | Accepted | Footprint readiness is an explicit whole-board audit that resolves every selected asset, retains its source SHA-256, validates electrical pad mappings, and reports all gaps in one result. Proxy footprints cannot satisfy it. |
| CS-069 | Accepted | KiCad fabrication-only pad apertures are distinct from electrical copper pads. The physical IR retains paste/mask apertures, footprint clearance, heatsink/zone behavior, and unused-layer removal; export, process DRC, geometry fingerprints, and audit preserve those distinctions. |
| CS-070 | Accepted | A CAM-required manufacturing release must freshly qualify its exact tool tuple against a hashed positive/negative corpus before inspecting staged production artwork. The manifest records corpus hashes; a missing tool, missing corpus, unsafe file, parser disagreement, or failed case cannot be published as a qualified release. |
| CS-071 | Accepted | CAM-required release reconciles metric Excellon hits and IPC-D-356 pad/via records against the signed physical IR before publication. KiCad drill and IPC-D-356 coordinates are Cartesian-up relative to PCB/IR Y-down; unknown drill commands and missing, extra, moved, or remapped contacts fail closed. |
| CS-072 | Accepted | Footprint-local copper keepouts are first-class physical IR. They move and mirror with placements and participate in routing, DRC, KiCad export, and geometry-bound signoff; unsupported embedded zones fail closed. |
| CS-073 | Accepted | Prototype fabrication rules are selected explicitly, never inferred from a footprint or target name. The JLCPCB four- and six-layer profiles currently use their published 0.09 mm minimum copper space and track-width floor while retaining 0.20 mm ordinary tracks. Router acceptance checks exact copper and copper keepouts against those rules; a profile alone cannot certify KiCad project rules, stackup, assembly, or manufacturing readiness. |
| CS-074 | Accepted | Detailed routing builds a deterministic nonuniform search grid that includes connected pad centers as well as regular coarse coordinates. Multiple direction-diverse, geometry-checked pad accesses are search alternatives; only the selected lead-ins become copper. Physical-distance costs and an admissible heuristic prevent irregular grid spacing from distorting route preference. A bounded guide-corridor search precedes bounded unrestricted walk-around; budget exhaustion is explicit and never commits partial copper. |
| CS-075 | Accepted | Source `copper_zone` constraints identify a net and physical layers without adding coordinates to the electrical connectivity IR. Lowering creates deterministic, unfilled physical zone intent with an explicit board-edge inset. The declaration alone cannot close a net or satisfy release: authoritative refill, connected-copper validation, and content-bound signoff remain separate downstream gates. |
| CS-076 | Accepted | KiCad footprint pad positions remain footprint-local, but emitted pad angles include the component placement angle. Export and native DRC must agree on rotated copper shapes; a textually valid board is not proof that rectangular pads remain separated after rotation. |
| CS-077 | Accepted | Every exported KiCad PCB is paired with a same-stem KiCad project carrying the physical IR's minimum clearance, explicit minimum track width, and Default net-class widths/vias. Default widths and via sizes are not mislabeled as global fabrication minima. The project is included in manufacturing staging, checksum inventory, and KiCad DRC; a standalone board checked under machine defaults is not an authoritative signoff result. |
| CS-078 | Accepted | Imported footprint-local keepouts remain nested inside their footprint on KiCad export, with board-space polygon coordinates in PCB artifacts and canonical local coordinates in library artifacts. Board-level keepouts remain board-level. Native DRC exempts the owning footprint's own pads from its local keepout while still checking foreign pads, tracks, and vias; flattening a local keepout into a board rule area changes semantics and is forbidden. |
| CS-079 | Accepted | Until a geometry-aware silkscreen label pass exists, automatically generated reference designators go to the fabrication layer, not silkscreen. This preserves assembly identity without printing overlapping text. Imported footprint silkscreen graphics remain intact; an unimplemented label placement pass cannot be counted as silkscreen signoff. |
| CS-080 | Accepted | Inner-zone pad stitching is a distinct, provisional physical step: exact-clearance surface traces and vias may escape pads into the declared zone outline, but an outline is not a fill. Unstitched pads remain explicit, and even a fully stitched pad set cannot satisfy connectivity or manufacturing release until a pinned fill and connected-copper check prove the resulting plane. |
| CS-081 | Accepted | Physical IR uses board coordinates with Y increasing downward. A positive KiCad footprint or pad angle maps local +X toward board -Y at 90 degrees; native placement, clearance, DRC, and KiCad export must use the same transform. Geometry equivalence is checked against KiCad DRC on routed drafts, not inferred from textual footprint syntax. |
| CS-082 | Accepted | Non-plated footprint drills are mechanical obstacles across every copper layer, including when their pad number is empty. Routing and native DRC enforce the board's explicit minimum copper-to-hole clearance, which is exported to KiCad project rules and bound to the physical signoff digest. The only exception is a `hole_clearance(COMPONENT)` constraint: it applies a smaller, reasoned value between that component's own copper pads and its own non-plated holes, and nothing else. Native DRC records every pair that passes only because of it, the value enters the signoff digest, and the export writes a matching same-stem `.kicad_dru` rule so KiCad's DRC agrees. |
| CS-083 | Accepted | Detailed-route repair distinguishes an exhausted search budget from an exhaustive no-path result. A coarse-grid no-path failure receives one bounded half-pitch retry (not finer than 0.25 mm); budget exhaustion does not inflate the search graph. All retries retain exact copper and hole-clearance checks. |
| CS-084 | Accepted | Multi-pass detailed routing retains two baseline admissible-heuristic passes, then varies weighted-A* guidance deterministically across later passes. Every proposed route still passes exact geometric clearance, and the merge stage accepts only compatible complete alternatives; search-weight diversity never weakens the physical-rule gate. |
| CS-085 | Accepted | Dense SMD fanout is an explicit physical package-access stage before ordinary detailed routing. With fanout enabled, CS-131 moves ordinary local reservations ahead of critical long routes. It uses legal, non-via-in-pad track/via pairs, preserves exact clearance, records unresolved pads, and exposes only verifiable locked-copper via anchors to the downstream router. Fanout is not electrical connectivity intent or a proof of overall route completion. With CS-163 a reserved escape is one terminal of its pad, not its replacement. With CS-172 a pin whose net may not change layer escapes on its own surface instead of to a via. |
| CS-086 | Accepted | Placement feedback may use exact detailed-routing failures after global routing. It moves only legal, movable components on a bounded trial set, reruns every routing and DRC stage from an unrouted placement, and accepts only a strictly improved completion/DRC score. Existing copper is never dragged implicitly with a component. |
| CS-087 | Accepted | Detailed repair may transactionally rip up a bounded group of ordinary nets, but cannot displace locked critical/fanout copper. It tries deterministic displaced-net orders, rebuilds the clearance state for each trial, and commits only when the candidate and every displaced net reconnect. A failed trial leaves the original route unchanged. Within one routing run, a search repeated with identical inputs (board and checkpoint identity, ordered clearance insertions, net, rule, guide, anchors, congestion, mode and options) may return the earlier attempt from a bounded memo; any changed blocking geometry is a new search, and reuse never changes selected copper. |
| CS-088 | Accepted | Filled-plane connectivity requires version-qualified, same-stem KiCad PCB/project refill and DRC evidence bound to the exact source, exported, filled-board, and report bytes. Any open connection, isolated island, missing report field, tool error, or other DRC violation fails the gate. Provisional zone outlines and pad stitching never count as this evidence. |
| CS-089 | Accepted | Drill-to-drill spacing is checked independently of electrical net, including same-net via pairs and via-to-plated-pad holes. The incremental router and authoritative native DRC share this requirement; copper clearance alone cannot certify hole spacing. An existing same-net via may be reused at its exact position without drilling another hole. |
| CS-090 | Accepted | Pre-escape vias are provisional until a detailed route uses a second copper layer. After routing, an unused fanout via is removed while its connected surface stub may remain, trimmed back to the centre of a same-net land it crosses so no end is left open; abandoned stubs and vias of failed nets are removed. Before final DRC, route-board sweeps ordinary nets once more and cuts any routed track whose open end runs past a land of its net that it crosses back to that land's centre, if the net stays connected; input, hard-macro, critical and zone copper are never changed. With CS-163, the land, via and boundary witness copper a successful net does not need is released transactionally and no stub is left open. KiCad dangling-via findings remain a required independent check. |
| CS-091 | Accepted | Global resources estimate usable copper crossings and legal via sites from physical geometry, never from footprint courtyards. A through-via consumes one shared site resource across its full physical span. Pads may offer multiple individually DRC-checked local access candidates; a `region_only` access certifies only its pad exit, not a complete path to the coarse guide center, and is reported separately. Only detailed copper plus DRC can establish connectivity. |
| CS-092 | Accepted | A nearly board-wide inner copper zone reserves that layer for its net. Foreign-net global, critical, fanout, and detailed tracks may not consume it; legal through-vias may cross it. Coarse guides are geometric capacity reservations rather than mandatory detailed-route layers, so bounded detailed search may project a guide across other allowed signal layers while retaining exact via and copper checks. |
| CS-093 | Accepted | Repeated footprint lands with one logical pad number remain separate physical copper objects. A bounded, exact-clearance post-route stitch may join them; separate legal plane contacts may also join them only after authoritative filled-plane verification. Blocked lands are reported, not silently accepted as externally connected. Native logical-pin connectivity and independent KiCad physical connectivity must both pass before release. |
| CS-094 | Accepted | An early plane-pad escape stage can reserve legal surface traces and through-vias before ordinary detailed routing. With fanout enabled, CS-131 places selected plane contacts after ordinary access reservations and critical routing; without fanout, they follow critical routing directly. Signal routing treats these provisional escapes as locked copper. Broad reservation of every GND pad is not the default: it can block a nearby signal or high-fanout power exit. Explicitly selected pads or bounded feedback may reserve only late-failing lands, then rebuild and compare the complete signal route before acceptance. Filled-zone continuity still requires independent evidence. |
| CS-095 | Accepted | A zone net explicitly deferred for filled-copper verification is not a detailed maze-route failure and MUST NOT trigger ordinary detailed-route placement feedback. Actual signal search failures remain trial targets. Pending zone-pad contacts have a separate escape-aware placement objective that can nominate local moves without treating the zone itself as a failed global wire route. |
| CS-096 | Accepted | Provisional surface-pad-to-plane-via escapes first try a short straight or two-segment 45-degree path, then a bounded two-segment Manhattan or three-segment lateral path on the pad side. An arbitrary-angle direct lead-in is a last-resort local fallback, not a long-net routing style. Repeated same-number lands may use the same bounded detour. Every new segment must satisfy exact foreign-copper, keepout, and board-edge clearance; a candidate through-via must satisfy drill and edge rules. Local paths do not assert filled-plane continuity, and unresolved contacts remain pending. |
| CS-097 | Accepted | A logical pad number can identify multiple physically separate SMD lands. Plane stitching must inspect and escape every such land independently, reporting the logical pad as stitched only if all target lands receive legal provisional plane contacts. The electrical IR may retain one pad reference, but that reference alone cannot certify physical continuity of repeated lands; the authoritative filled-zone and KiCad connectivity gates remain mandatory. |
| CS-098 | Accepted | Provisional plane-via candidate grid step and search radius are explicit, reportable routing parameters. Finer search is an experiment, not permission to relax geometry or manufacture rules; only independently refilled KiCad DRC may establish whether it reduces actual opens without adding slivers or other findings. |
| CS-099 | Experimental | A plane-pad escape may use an explicitly selected local trace width only if it is at least the physical IR's minimum track width and clearance floor, never below 0.09 mm, and no narrower than a net-specific width rule. The default remains the ordinary 0.20 mm board track. JLCPCB currently lists 0.09 mm minimum width/space for [six-layer boards](https://jlcpcb.com/resources/6-layer-pcbs); this capability is not a current-carrying, yield, assembly, or CAM qualification. The minimum track width is signed by native DRC and emitted in the same-stem KiCad project; narrow escapes still require independent KiCad DRC and later manufacturing signoff. |
| CS-100 | Experimental | After direct pad-to-via attempts, an opt-in bounded second pass may connect an unescaped zone-net SMD land to a same-side, same-net land already proven to reach a prospective plane via. Only exact-clearance local surface paths within the declared contact radius are accepted; newly rescued lands become anchors for a finite chained retry. This is provisional connectivity only, and filled-zone/KiCad verification remains required. The default radius is zero because the present full-vertical board gained copper without reducing KiCad opens. The contact radius is explicit in route reports. |
| CS-101 | Experimental | A six-layer JLCPCB GND plane escape may optionally place a 0.30 mm diameter / 0.20 mm drill through-via at the center of an SMD GND land when ordinary off-pad access fails. It must satisfy exact all-layer copper, keepout, edge, actual-drill spacing, and drilled-hole-to-foreign-copper checks; any violation leaves the land pending. Such a via is explicitly tagged `filled-capped` in physical IR and counted in the route report. When one exists, the companion KiCad project pins its 0.30/0.20 mm via and 0.05 mm annular minima for independent DRC without relaxing the separate hole-clearance rule. KiCad PCB/Gerber geometry alone does not specify plated-over-filled via processing: the fabrication order must explicitly require it. This is not available for other profiles or non-GND nets, and it does not by itself prove filled-plane continuity or assembly readiness. See [JLCPCB's POFV process dimensions](https://jlcpcb.com/news/free-via-in-pad-6-20-layer-pcbs-pofv). |
| CS-102 | Accepted | General detailed routing uses an eight-heading octilinear search: long straight runs and 45-degree diagonals are preferred through Euclidean step cost and angle-proportional turn cost; a 90-degree turn remains legal when needed. A high-fanout net with at least 16 pads starts in four-heading mode to bound Steiner-tree search growth; a smaller net may also retry once in four-heading mode if octilinear search exhausts its bounded state budget. Each net reports whether this orthogonal mode was used. Only horizontal, vertical, or exact 45-degree shortcuts may replace a detailed path. Exact-clearance and blocked-grid checks remain mandatory, and collinear segments may be merged only without moving copper or erasing a branch junction. Short pin-access lead-ins may have other angles when exact legal access requires them. |
| CS-103 | Accepted | A declared copper-zone net is plane-first by default across global planning, detailed routing, and the `route-board` CLI: it consumes no fictitious global wire corridor and is not maze-routed as a long ordinary net. Global reports explicitly count it as deferred rather than connected or failed. The CLI attempts local pad-to-plane escapes and vias after signal routing; a bounded feedback trial may selectively reserve late-failing pads early. Zone intent and provisional escapes do not establish continuity: authoritative zone refill, connected-copper check, and KiCad DRC are still required. A net merely named `GND` without a declared zone is not silently treated as filled copper. |
| CS-104 | Accepted | Placement geometry and exact legality checks admit explicitly allowed 45-degree orientations; no orthogonal-only normalization may reject such a rule. Unconstrained components retain cardinal default orientations so connectors and assembly-sensitive components are not rotated diagonally without design intent. Candidate generation, transformed pad coordinates, courtyard clearance, region rules, relative constraints, and KiCad export all use the same angle. |
| CS-105 | Accepted | When direct, two-segment, and bounded lateral pad-to-plane-via paths fail, a bounded eight-heading local search may find a short legal off-pad via exit. It checks every edge against exact foreign copper, keepouts, and board edge, checks the via against all spanned layers and drilled-hole rules, and coalesces only collinear segments. Legal coarse via candidates guide A*; the search may inspect finer sites when no coarse site is available. Adjacent same-net lands may share an already committed plane via. The result remains a provisional contact, not proof of filled-plane continuity. |
| CS-106 | Accepted | After the ordinary signal route and late zone-pad escape, a bounded placement/escape feedback pass may target only still-pending zone pads. It tests the nearest local exit, then legal nearby component moves and explicitly allowed rotations from an unrouted placement snapshot, prioritizing components with more pending lands; alternative exit directions follow. Each candidate is preflighted for local contact, fully rerouted with its placement fixed, stitched again, and accepted only if it reduces pending zone pads without worsening the identity of failed signal nets, global/critical status, or hard native DRC. An accepted improvement consumes trial budget, carries its reserved early contacts into subsequent reroutes, and retargets any newly pending pad. A rejected trial never mutates accepted copper. Reports retain each trial outcome and rejection reason. This bounded transactional placement-and-route loop follows the margin/routability principle in [NS-place](https://arxiv.org/abs/2210.14259) and prioritizes package escapes and power access as advised by [TI's AM62x escape-routing guide](https://www.ti.com/lit/an/sprad13a/sprad13a.pdf); it is not an assertion that those methods are implemented verbatim. |
| CS-107 | Accepted | Before moving placement for a late-failing zone pad, a bounded local transaction may remove only detailed-router-created ordinary copper, find an exact-clearance candidate pad escape, query the committed-copper index for its actual blocking nets, and reroute only those nets around the reserved escape. Critical routes, fanout, pads, earlier plane contacts, keepouts, and other ordinary nets stay fixed. Fanout cleanup is scoped to attempted nets; removing input vias requires explicit ownership evidence, and failed subset attempts preserve input escapes. Acceptance compares unaffected-copper identity and fresh complete-candidate ordinary-net connectivity, not cached connected flags. All displaced nets must reconnect, no new ordinary net may open, pending zone pads must decrease, and hard native DRC must not regress; otherwise the immutable original route is retained. Committed metrics are recomputed from actual copper. The final filled-zone and independent KiCad DRC gates remain authoritative. |
| CS-108 | Accepted | Global and detailed routing use soft layer and direction costs in addition to congestion, via, and bend costs. A full-board dedicated plane makes adjacent inner signal copper preferable for long ordinary runs, while surface layers and layers without an adjacent declared reference receive small nonnegative penalties; absent a dedicated plane, no inner-over-outer preference is inferred. With multiple inner signal layers, preferred horizontal and vertical directions alternate. These are optimization hints, not hard restrictions: 45-degree paths, short surface escapes, legal crossings of preferred headings, explicit per-net layer rules, and exact DRC remain valid. If a biased detailed search strands an ordinary signal under its finite budget, it retries with neutral costs and keeps the more complete result. High-speed/RF return-path or impedance signoff is not inferred from a layer preference. |
| CS-109 | Accepted | Planar baseline, layer, and wrong-way search costs use physical length with a shared 1 mm reference, not edge count or configured grid pitch. Integer micro-costs preserve nanometre-scale subdivision invariance; bend and via events remain separately weighted. The baseline planar rate is 10 cost units/mm. Inserting pad-access coordinates must not remove an otherwise valid physical 45-degree successor: octilinear search follows the nearest coordinate-compatible diagonal ray beyond intermediate axis splits, retaining blocked-grid and exact copper clearance checks. Neither a preferred heading nor a grid coordinate is electrical connectivity intent. |

| CS-110 | Accepted | Native explicit-copper connectivity is a layer-aware contact graph of rounded track shapes, placed pad shapes and vias over their actual spans. Positive-area overlap at interior T/cross contacts, pad edges and annuli counts; shared boundaries alone, a nonzero copper gap, a foreign net or an absent common layer do not. Open drills are not solid disks, while explicitly filled/capped vias have surface caps. Repeated pad numbers do not invent a connection between separate lands. Zone outlines and unverified fills never substitute for independent filled-zone connectivity evidence. Optional installed-KiCad differential regression tests exercise these predicates. |
| CS-111 | Accepted | A late zone-escape feedback trial reserves the failing package's entire same-zone-net pin group, including already escaped neighbour pins, before fanout and ordinary routing. Reservations do not extend automatically to unrelated packages or rails. Accepted sequential trials retain those package reservations, compare fresh explicit-copper connectivity, and require independent filled-zone verification. No hard-coded reference or pin number determines this grouping. |
| CS-112 | Accepted | Nonuniform-grid line-of-sight follows physical coordinates. Exact polygon containment detects even narrow concave-outline crossings; physical track-blocking keepouts and on-ray blocked nodes remain obstacles, while off-ray index-space nodes and via-only keepouts cannot remove a track ray. The actual width/clearance query remains mandatory. Cached ray results contain only static outline/keepout/node legality, bound to immutable geometry and axes, not mutable copper clearance. Physical-span via legality is cached only within a single immutable single-net search and never reused after a clearance-index mutation. Neither cache bypasses a check. |

| CS-113 | Accepted | Duplicate-land closure runs before full and subset routing feedback evaluates connectivity. Stitching uses the same exact copper-contact graph as native DRC, reuses existing pad-edge/interior/track/via/multilayer paths, and only joins disconnected physical land groups with bounded, clearance-checked paths on allowed layers. Failed search flags, deferred zone nets and resource overflow are not promoted to success; added ordinary copper and fresh native opens update candidate metrics/status. Native checking includes separated lands on a single-logical-pad net. Final helper reports distinguish surface-pending work from independently verified zone contacts. Only fresh board/export-bound KiCad evidence with zero unconnected items/islands and no non-library violations may resolve pending zone-net references. Library issues remain visible signoff failures; native findings, signoff tokens and fabrication readiness are never waived by this reconciliation. |

| CS-114 | Accepted | Critical copper is committed atomically only after fresh native physical DRC verifies the candidate together with all physical pads, keepouts, board edges, drill envelopes and previously accepted critical geometry. Only unrelated opens and full-route completeness are expected omissions in this early stage; no geometry error is waived. A failed candidate contributes no locked copper. Aligned differential terminals may use a midpoint channel with symmetric 45-degree tapers; non-aligned pair escapes still require joint search, never independent ordinary-net repair. Single-ended critical nets may use bounded exact maze search against immutable earlier reservations, with the original profile rechecked before acceptance. General fanout, subset repair and duplicate-land closure cannot synthesize or prune critical copper. Explicit USB/RF example profiles are geometric intent, not evidence of impedance, antenna performance or manufacturer reference-layout compliance. |

| CS-115 | Accepted | Non-aligned differential terminals use a joint same-layer package escape and heading-aware common-spine search, never two independent maze routes. Legal paired exits preserve member order; coupled lanes use offset-line intersections at straight/45-degree corners. The package taper is actual reserved copper, not an invented straight extension behind its port. Search retries at 1/0.5/0.25 mm with at most eight port combinations and 30,000 expanded states per search at each pitch. Full cross-member geometry, existing critical reservations, original profile budgets and fresh native DRC gate atomic acceptance. Reports retain aggregate searches/states/candidate attempts, including unsuccessful searches. Parallel projected overlap is unioned when measuring coupling so split and unequal mitered edges do not erase or duplicate coupled length. This geometric proxy is not impedance or signal-integrity evidence. New paired layer transitions, non-octilinear pin rows and multi-terminal pairs remain unsupported by this search and fail closed; coarse-guide transitions are proposals, not mandatory copper. Explicitly permitted 45-degree placements are supported without changing electrical pin mapping. |

| CS-116 | Accepted | Reference-layout macros are hard rigid clusters in the physical IR, distinct from soft semantic groups. Local member poses are bound to resolved footprint SHA-256 identities and an explicit source locator, with a unique physical anchor pad/origin. Bounded legalization and refinement transform complete units; fixed members freeze their unit, conflicting fixed poses fail, and ordinary component swaps/repairs cannot split it. Layer-scoped local copper keepouts follow the same transform into routing clearance, native DRC and KiCad export. Rules/templates participate in routing and signoff fingerprints. Front-side translation and explicitly permitted rotation, including 45 degrees, are initially supported; mirroring and overlapping macros fail closed. Reference copper is not transplanted, and no template/source locator is automatic RF, impedance, return-path or fabrication qualification. |

| CS-117 | Accepted | Opt-in physical JSON scenes bind content-addressed reference data to complete resolved footprint digests and declared physical pad/net roles before placement. They execute no template code, fetch no source and change no connectivity. Unknown fields or changed/missing identities fail closed. The machine-local footprint source_path is excluded from asset hashes; source bytes, geometry, library identity and remaining metadata stay bound. Explicit internal macro courtyard gaps never exempt courtyard overlap, external component spacing or copper/fabrication checks. The Nordic three-member example preserves reference midpoint/rotation/physical C3 numbering but is explicitly a provisional footprint adaptation; matching-ground copper, support circuit, antenna and actual stackup remain separate qualification requirements. |

| CS-118 | Accepted | Exact board-edge checks may recognize a four-vertex axis-aligned rectangle and test segment capsules/via disks against its convex erosion using doubled integer distances. Odd-nanometre diameters and boundary tangency retain the original predicate. Only immutable rectangle classification is cached; nonrectangular, concave and invalid vertex orders retain the original exact polygon/edge checks. This changes computation cost, not outline, clearance, search budget or copper acceptance. |

| CS-119 | Accepted | Before accepting a surface-only single-ended critical guide, compare bounded via-free local alternatives on a layer common to every actual physical land and permitted by the routing/plane policy. For two to eight lands, straight/45-degree-first legal paths form a weighted terminal graph; a deterministic minimum spanning tree must include every land, including repeated pad numbers. Clock/RF feed point-to-point limits remain enforced. Original profile budgets and fresh complete-candidate native DRC gate acceptance; a connected incumbent changes only for strictly shorter copper, and failed proposals never displace it or earlier critical reservations. Differential/CAN pairs, global transition ownership and general-net maze routing retain their existing owners. This is not a Steiner solver, source-reference copper transplant or RF qualification. |

| CS-120 | Accepted | Critical routing may emit observational started/finished group notifications. Preflight checkpoints record the running group, completed results and elapsed wall time separately from routing geometry/fingerprints, retaining incomplete status on interruption. Progress/timing telemetry cannot certify connectivity, relax budgets, or promote partial routing to production readiness. |
| CS-121 | Accepted | Opt-in bounded critical placement feedback must use legal whole-unit moves from an unrouted snapshot, rebuild global guides and every critical reservation, and accept only a strict subset of failed critical net identities with no fresh hard native DRC errors. Fixed/rigid/orientation rules, original critical budgets and prior connectivity are preserved. Reports retain rejected trials; this stage cannot certify ordinary routing, impedance or fabrication readiness. |
| CS-122 | Accepted | A joint-search pair may undergo bounded shared-spine compaction/shortcut proposals only with unchanged original package escapes, lane order and endpoint headings. Both lanes are remeasured and checked atomically against original profiles and fresh native DRC with prior reservations. Rejected proposals retain the accepted pair; neither member length may increase. Collinear segment reduction alone cannot be reported as physical wirelength or bend improvement. |
| CS-123 | Accepted | Physical pad coverage and copper connectivity do not validate a component's internal conductive paths or coupled-winding polarity. Source-backed library corrections require topology-specific regressions, updated dependency identities, and fresh routing/electrical review; historical geometry reports must explicitly identify superseded electrical acceptance. Logical signal names must not be reassigned merely to shorten routes. Sources remain optional in the general IR; this decision does not claim a general internal-component circuit solver. |
| CS-124 | Accepted | General detailed routing and its single-ended critical fallback select and emit the same bounded exact octilinear pad-to-grid access path, preserving the actual terminal, net, width and layer. Try both diagonal/straight orders before orthogonal-corner fallbacks; every leg requires board-edge and exact copper/keepout legality. No oblique chord or terminal snapping substitutes for failed access. Tentative rip-up may cross removable tracks but never immutable geometry; its normal transactional acceptance remains mandatory. Other access/zone/fanout owners are not silently rewritten. |
| CS-125 | Accepted | Joint paired offset construction must preserve each spine edge's forward heading in both physical lanes. Adjacent miters consuming a short spine edge may collapse or reverse an inner lane; reject the whole construction and continue bounded search/refinement. Near-goal search may try at most 24 direct/collar tails per state, retaining cheap bridges before one/two-pitch advances and two-leg half/full-pitch S-turn approaches into the fixed end collar. Both original port headings, expanded-state/port-pair limits, full lane/escape clearance and profile/native checks remain mandatory. Never trim one member, move original package escapes or accept stale incumbent provenance to remove a cusp. |
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

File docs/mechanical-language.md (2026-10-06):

# Mechanical source specification

Status: accepted and implemented (unreleased v0.1).

Named datums, stable straight boundary edges and component/pad/mating-face
attachments are supported; see [advanced mechanical intent](advanced-mechanical-intent.md).
That specification also defines component-owned body overhang, declared height,
side-specific enclosure limits and moving/rotating tool-access regions. None of
these mechanical policies relax copper DRC or alter the manufacturing outline.
`examples/mechanical_anchors/board.copper` demonstrates a rear 45-degree pad anchor
and an edge-relative mating-face point. Open it with
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

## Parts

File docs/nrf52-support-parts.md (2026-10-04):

# nRF52 demo support parts

Prototype-only support package for CopperScript's CR2032 hard-macro example.
The holder is [Keystone 3034](https://www.keyelco.com/product.cfm/product_id/798),
which accepts a CR2032. Its KiCad footprint has two positive lands numbered 1
and a negative contact numbered 2. The holder is passive; an installed cell,
not the empty holder, supplies energy.
The positive tabs are explicitly internally connected (`internal_pad_groups =
"1"`); solder both for mechanical retention, but no PCB bridge is required.
The negative contact still needs an external connection. See the repository's
[internal-contact generation checklist](../../internal-pad-connectivity.md).

The crystal and LED are explicit **reference placeholders**, not orderable
parts. Crystal oscillator terminals follow KiCad's Crystal_GND24 convention
(1/3 signal, 2/4 case ground). Select and verify an actual 32 MHz, CL=8 pF crystal
against [Nordic's reference circuitry, QFN48 LDO Table 1](https://docs.nordicsemi.com/r/bundle/ps_nrf52832/page/ref_circuitry.html).
The LED follows KiCad's cathode=1, anode=2 convention. Choose a low-current LED
with suitable forward voltage and check brightness over battery discharge.

Production publication is blocked by the unresolved orderable crystal/LED,
component tolerances, antenna tuning, and battery pulse-current performance.
No charging, cell protection, power switching or debug-probe power injection
is implied by these definitions.

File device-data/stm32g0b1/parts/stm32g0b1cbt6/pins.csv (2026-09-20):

name | number | bond | domains | directions | drive_modes | traits | connection | required_net_traits | voltage_min | voltage_max
VDD | 24 | VDD
VSS | 23 | VSS
PA2 | 10 | PA2
PA3 | 11 | PA3
PB6 | 45 | PB6
PB7 | 46 | PB7

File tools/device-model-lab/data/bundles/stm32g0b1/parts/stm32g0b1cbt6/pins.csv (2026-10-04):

name | number | bond | domains | directions | drive_modes | traits | connection | required_net_traits | voltage_min | voltage_max
PA0 | 25 | PA0 | digital | bidirectional |  |  | required
PA1 | 26 | PA1 | digital | bidirectional |  |  | required
PC0 | 21 | PC0 | digital | bidirectional |  |  | required
PC1 | 22 | PC1 | digital | bidirectional |  |  | required

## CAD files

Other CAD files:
examples/mechanical_reference/mechanical-assets/enclosure-guide.dxf

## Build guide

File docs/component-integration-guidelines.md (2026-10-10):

# Component integration guidelines for agents

Apply these rules when adding or replacing components in CopperScript examples,
projects or reusable circuit definitions, including components imported from
CopperLib. A correct pin map and electrical connectivity are only part of the
integration; preserve the manufacturer's layout-dependent requirements too.
This is contributor guidance, not a claim that the compiler enforces every item.

## Repository ownership: reusable components belong in CopperLib

Generic component definitions and circuit modules that can be reused by other
projects belong in CopperLib, together with their reusable footprints, evidence,
tests and physical hard macros. Check the existing catalogue before creating a
duplicate; consuming projects should import the shared package rather than copy
or maintain a project-local version. This applies even when the first use is a
single example or board.

Keep board-specific composition, placement, mechanics, selected operating
configuration and application constraints in the consuming project. Expose
reusable support/layout obligations through the library contract without baking
in one board's reference designators or coordinates. Clearly isolated synthetic
compiler test fixtures are not reusable component catalogue entries.

## RF components: always review matching and layout

1. Inspect the exact manufacturer's datasheet, reference schematic and reference
   layout for the selected part/package, bands and intended RF interface.
   Record source URLs, revision/page/figure locators and hashes for consumed
   assets. Do not treat distributor CAD as manufacturer layout qualification.
2. Explicitly determine whether chip matching, a balun, antenna tuning, filters
   or other RF support are required, already integrated, or unresolved. A
   nominal 50-ohm module port does not establish that its board antenna needs
   no matching. Record evidence when no external network is required; do not
   invent a network or omit one merely because ERC passes.
3. Check the reference layout for critical pin-to-part distances, orientations,
   topology, short interconnects, ground returns, layer/reference-plane and
   impedance requirements, return vias and antenna keepouts. Translate them
   into explicit physical constraints. Use a reviewed hard macro where fixed
   placement alone cannot preserve prescribed copper or matching-ground paths.
4. Check the placed and routed result with the real footprints and stackup.
   Component-centre proximity alone cannot prove short pin-to-pad routing.
   Preserve antenna copper/component exclusions and avoid generic ground fills
   or stitching that bypass a prescribed matching return. Different packages,
   antennas, bands or stackups require reviewed adaptations and tuning; do not
   reuse values or dimensions blindly.

## Switched power: prefer a hard macro, otherwise strong constraints

For switching regulators, converters and switching chargers, ideally generate
a source-backed physical hard macro from the applicable manufacturer's reference
layout. Include topology-specific support and preserve input/output capacitors,
inductor placement, high-di/dt current/return loops, switching-node geometry,
quiet feedback/sense paths and thermal/ground connections. Bind exact footprints,
pad/net roles, copper, ports, keepouts and permitted transformations. Label
authored or adapted geometry honestly; it is not automatically vendor-qualified.

If a macro cannot be created or reused safely, at minimum:

- Declare strong, explicit relative/fixed placement, orientations and
  pin-relative distance limits for critical support components; soft placement
  groups and generic proximity preferences are not sufficient.
- Define trace widths or conductor geometry for critical power/current paths,
  based on operating peak/RMS current, copper thickness, temperature rise and
  voltage-drop limits. Review neckdowns at pads and via current capacity.
  Do not rely on default board widths or widen every net indiscriminately.
- Bound the actual critical routes and loop geometry, maintain short local
  returns and keep feedback/sense routing away from switching copper. A short
  distance between component origins does not establish a small switching loop.
- Encode requirements using supported physical constraints, routing profiles or
  macro assets, and test generated placement/routing against them. Explicitly
  document missing enforcement and require manual geometry review for those
  gaps; do not invent language syntax or silently relax limits to get a pass.

Numerical limits must come from the applicable reference or a documented
engineering derivation, not a universal guessed distance or trace width. If
the source does not establish a requirement, mark it unresolved and explain
what evidence is needed. A standalone reusable part may delegate host-specific
geometry, but must expose these support/layout obligations to its consumers.

## Verification and handoff

Keep evidence and unresolved adaptations with the part/circuit or board. Add
regression checks for matching topology, exact footprint/pad bindings, critical
placement and conductor dimensions where enforceable. Inspect all relevant
copper layers after native refill/DRC. Rebuild physical outputs when parts,
footprints, constraints or reference evidence change.

ERC, a legal placement, short routes and zero native DRC errors do not certify
RF performance, converter stability, power transients, thermal behavior or EMI.
State those qualification limits and do not describe an unresolved design as
production-ready.

Implementation references:

- [Physical hard macros](physical-hard-macros.md)
- [Language constraints and routing profiles](language-reference.md)
- [Device and part generation](device-generation.md)
- [CopperLib hard-macro review checklist](https://github.com/andenore/CopperLib/blob/main/docs/hard-macro-review-checklist.md)

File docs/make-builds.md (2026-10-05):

# Shared Make builds

Every board uses the same recipes in `make/board.mk`. Board settings live in
`make/examples/*.mk`; electrical/mechanical intent remains in `.copper`, and
explicit hard-macro/placement scenes remain data files. There are no CM4 or
full-vertical Python routing wrappers. CI uses these same Make configurations;
it explicitly sets `PLACEMENT_TEMPLATES=` for its full-vertical run to preserve
its source-only placement policy, and owns timeout/artifact handling separately.

Requires GNU Make, an installed CopperScript environment (`uv sync --extra test`
from this checkout), and KiCad 10 plus its footprints for physical targets.
On Windows GNU Make is an additional tool, not bundled with CopperScript;
`mingw32-make` can be used wherever commands below say `make`.

## From the repository root

```sh
make EXAMPLE=cm4 check
make EXAMPLE=cm4 compile
make EXAMPLE=cm4 route
make EXAMPLE=full-vertical route
make EXAMPLE=nrf52 route
make EXAMPLE=round-led-ring route
make compile-examples
make check-examples
```

Targets:

| Target | Result |
| --- | --- |
| `all` (default) | ERC and JSON compilation; no expensive routing |
| `check` | ERC |
| `compile` | Hierarchical electrical/mechanical JSON IR |
| `layout` | Placement draft and report, not a routed board |
| `edit` | Mechanical/floorplan editor |
| `route` | Profiled package escape/routing, saved copper fill and native DRC |
| `compile-examples` (root only) | Compile all 16 registered complete examples |
| `check-examples` (root only) | Run `check`, `compile`, and a dry-run of `route` for every registered complete example |

`compile-examples` and `check-examples` exclude `examples/invalid_board/board.copper` and the intentionally
incomplete `examples/nrf_antenna_macro/board.copper` probe. It does not waive ERC. A selectable
example is not a promise of successful routing or production readiness: only
an actual passed route/fill/DRC run establishes that board's connectivity.
The CM4 four-layer routing preset has been verified with KiCad 10.0.6.

`check-examples` checks the fast targets and expands every route recipe without starting
routing. CI additionally runs the `layout` and non-interactive `edit` targets for the
physical examples (`cm4`, `full-vertical`, `nrf52`, `round-led-ring`, the mechanical
examples, and `resolved-footprint`) on each commit. Electrical and simulation fixtures
without complete footprint identities still run their complete fast target set. Actual
routing remains limited to release tags.

Compilation/placement outputs live under ignored `build/<board-name>/`.
Each route gets a fresh `build/<board-name>/runs/<UTC-id>/`; open its
`board.kicad_pcb` alongside its generated `.kicad_pro`, `fp-lib-table` and local
`.pretty` library. The directory also contains the route/native reports, logs,
profiling summaries, hashes and `run.json`. No recursive clean target deletes
past evidence. Set `RUN_DIR` to a **new/empty path below project `build/`** if a
fixed CI destination is needed.

The generic `pcbir.build` runner resolves this board's imports through its
nearest manifest, fetches only pinned URL dependencies, then routes offline.
It never assumes CopperLib or a sibling checkout. It preserves routing errors,
saves filled copper in the deliverable and accepts success only with ERC pass,
complete routing, native fill verification, zero violations of any severity
and zero unconnected items. Profiling does not change exit semantics.
The shared default chooses among the placement planner's actual legal candidates;
it does not force `candidate-00`, which may have been rejected. To reproduce an
explicit candidate, set `EXTRA_ROUTE_ARGS="--placement-candidate candidate-01"`;
an unavailable requested identity remains an error rather than a silent fallback.
GNU Make normally returns 2 when a recipe fails; inspect `run.json` for the
underlying routing exit code. No failure is suppressed with `-` or `|| true`.

## Overrides

KiCad paths are automatically discovered for `route` from environment/PATH or
the standard Windows KiCad 10 installation. On Linux, `layout` and `edit` use
`/usr/share/kicad/footprints` by default. Set `KICAD_FOOTPRINTS` for a custom
or nonstandard KiCad installation; physical settings and explicit scenes are
shared across targets.

```powershell
make EXAMPLE=cm4 route KICAD_CLI="C:/Program Files/KiCad/10.0/bin/kicad-cli.exe" KICAD_FOOTPRINTS="C:/Program Files/KiCad/10.0/share/kicad/footprints"
make EXAMPLE=cm4 layout KICAD_FOOTPRINTS="C:/Program Files/KiCad/10.0/share/kicad/footprints"
make EXAMPLE=cm4 route RESOLVE_ARGS="--locked --offline"
make EXAMPLE=cm4 route BUILD_ARGS=--dry-run
make EXAMPLE=cm4 route PROFILE=none
make EXAMPLE=full-vertical route EXTRA_ROUTE_ARGS="--zone-dependency-expansions 0"
```

`make -n EXAMPLE=cm4 route` prints recipes without executing them. `BUILD_ARGS=--dry-run`
runs setup/command validation against cached dependencies without writing output.
`PHYSICAL_ARGS`, `ROUTE_ARGS` and `EXTRA_ROUTE_ARGS` accept normal CLI options;
the shared runner controls output paths, report paths and final fill verification.
Profiles are preferences, never hardcoded geometry or weakened DRC rules.

## Another source or project

Any `.copper` board can use the root recipes, not just registered examples:

```sh
make SOURCE=examples/hierarchical_board/board.copper compile
make SOURCE=path/to/my_board.copper route LAYERS=4 FAB_PROFILE=jlcpcb-four-layer
```

Use the default `EXAMPLE=valid` when overriding `SOURCE` to avoid carrying
another example's optional physical scenes. For an independent repository,
include or copy the shared `make/board.mk`, install CopperScript and use a
settings-only Makefile such as:

```make
SOURCE := board.copper
LAYERS := 4
FAB_PROFILE := jlcpcb-four-layer
include make/board.mk
```

The independent project owns its manifest/lock and `build/` gitignore entry;
it needs no example-specific Python script. Its `PYTHON` setting must select
the environment with CopperScript installed. In this checkout the CM4 local
Makefile also includes the shared recipes: `make -C examples/cm4_baseboard route`.

Successful routing is **not manufacturing signoff**. Power/current review,
mechanical/RF qualification, exact assembly selections and manufacturing export
remain separate obligations; this workflow does not create Gerbers or waive DRC.

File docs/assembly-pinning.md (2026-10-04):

# Exact assembly selections (prototype)

Electrical library revisions and procurement identities are separate pins.
`assembly.lock` binds a board's compiled electrical IR to explicit manufacturer
MPNs and supplier ordering codes. It never resolves substitutes from stock.
Every assembled component must be covered; non-assembled library parts are
excluded. Hierarchical references retain their qualified paths.

```sh
copper assembly snapshot board.copper --locked --offline -o assembly.lock
# Fill manufacturer, mpn, supplier, supplier_part and optional catalogue URL.
# Review exact package, ratings, pin mapping and footprint before reviewed=true.
copper assembly check board.copper --locked --offline --lock assembly.lock --report build/assembly.json
copper assembly bom board.copper --locked --offline --lock assembly.lock -o build/bom.csv
```

Snapshot creation refuses to overwrite an existing lock. Circuit/library changes
invalidate the electrical digest; review differences and deliberately create a
new snapshot rather than silently accepting new parts. Missing fields, unknown
or duplicate references, mismatched parts/footprints, and unreviewed selections
fail the check. BOM export requires both ERC and assembly checks to pass.
Constraint diagnostic source locations are excluded from this digest, so the
same locked design works across checkout paths and operating systems. Actual
constraints, hierarchy, document evidence and library revisions remain bound.
The CSV contains JLCPCB's component-selection columns plus manufacturer/MPN.
No stock lookup, order submission or manufacturing signoff is implied.
The separate [native manufacturing exporter](manufacturing-files.md) can consume
this BOM and the final routed KiCad board to generate a matching JLCPCB CPL.
The footprint reference is pinned, but its geometry checksum still
requires the independent footprint/manufacturing audit.

## JLCPCB access experiment

JLCPCB publishes a [developer portal](https://api.jlcpcb.com/) and
[API access application instructions](https://jlcpcb.com/help/article/jlcpcb-online-api-available-now).
Its Components API covers specifications, inventory and pricing. Account
approval is required; endpoints and authentication must follow the integration
documentation supplied by JLCPCB. Do not guess endpoints, scrape private APIs,
or call a catalogue-page lookup an authenticated API test.

The initial experiment uses public catalogue evidence only. Catalogue presence
is not live stock, a reservation, or approval of a particular assembly order.
Live availability belongs in a timestamped report under ignored `build/`, not
in deterministic compilation. No credentials belong in a lockfile or Git.

Supplier offers should eventually live beside exact reusable CopperLib parts.
This bounded prototype uses explicit board-side selections without changing
the electrical language or claiming generic passives are qualified replacements.
There are no board-specific rules or selections in `pcbir`.

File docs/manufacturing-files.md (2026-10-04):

# Native manufacturing-file generation

`export-manufacturing` consumes the **final routed KiCad board**, preserving
native copper fill, arcs, circles, cutouts and slots. It requires a matching
`.kicad_pro` so native DRC retains the design rules. It does not reconstruct the
board from electrical IR or bypass DRC.

```sh
copper export-manufacturing build/board.kicad_pcb \
  --kicad-cli kicad-cli --skip-independent-cam -o build/manufacturing
# Optional: include a reviewed BOM and matching JLCPCB placement file.
copper assembly bom board.copper --locked --offline --lock assembly.lock -o build/bom.csv
copper export-manufacturing build/board.kicad_pcb \
  --skip-independent-cam --bom build/bom.csv -o build/assembly-manufacturing
```

The explicit acknowledgement is mandatory. This is **manufacturing-file
generation**, not the independently qualified release API. That API and its
strict circular-outline qualification gate remain unchanged. Firmware is not
required to manufacture an unprogrammed board.

The command stages a copy, refills its zones, runs native KiCad DRC at all
severities, and refuses violations, opens, incomplete reports, failed exports
or an existing output directory. Failed stages are removed; the input board
is never changed. It exports every declared copper layer, both masks,
silkscreens and pastes, Edge.Cuts, metric plated/nonplated drills and IPC-D-356.
Gerbers subtract mask openings from silkscreen. Absolute drill and plot origins
are consistent. `gerbers-drill.zip` contains only artwork and drills; reports,
PCB/project, native positions, manifest and SHA-256 checksums accompany it.
`manufacturing-package.zip` packages all these files and their checksums; the
checksum list covers archive contents, not the outer package itself.
Inventory checks are not independent geometric CAM verification.
For repeat builds, `--replace` permits replacement of a recognized generated
directory only after all new exports pass; previous output is retained in a
`.manufacturing-previous-*` sibling, not deleted. Inputs must live outside the
output directory. Review/remove old ignored build snapshots when no longer needed.

With `--bom`, JLCPCB CPL columns are generated from native KiCad millimetre
positions, both sides, a shared unmirrored origin and native CCW rotations.
Reference sets must match; unpopulated references are filtered explicitly.
Centroids are KiCad footprint origins, not inferred body or pad centroids:
use centred footprints and check asymmetric packages. No guessed global
rotation correction is applied. Verify pin 1, LED/battery polarity and
supplier-specific orientation in the assembly preview before submitting.
See [JLC's native KiCad export guidance](https://jlcpcb.com/help/article/how-to-generate-the-bom-and-centroid-file-from-kicad)
and [CPL conventions](https://jlcpcb.com/help/article/pick-place-file-for-pcb-assembly).

The manifest states `independent_cam=skipped_by_request`,
`qualified_release=false`, and `supplier_availability=not_checked`.
Native DRC does not establish supplier stock, assembly capability, electrical
function, acceptable component selections or factory order approval. Select
fabrication parameters when ordering; exported files do not purchase anything.

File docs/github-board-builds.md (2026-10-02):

# GitHub board inspection builds

`.github/workflows/board-routing.yml` runs on relevant `main` pushes, all pushed
tags and **Actions → Route and publish board inspection drafts → Run workflow**.
It invokes the real complete routing workflow, not a dry run or saved historical
PCB. Tags also route the nRF52/CR2032 hard-macro example. Manual runs can select
that example too. All generation stays in ignored `build/` directories.

## Download and inspect

Each run uploads an Actions artifact, retained for 90 days. Download and unzip
it, then open `board-inspection-drafts.zip`. Each board directory retains its
PCB, project, `fp-lib-table` and project-local `.pretty` footprint library:
keep these together when opening KiCad. `inspection/` contains a separately
refilled copy, native `kicad-drc.json`, command logs and direct SVG exports of
F.Cu, In1.Cu, In2.Cu, In3.Cu, In4.Cu and B.Cu. SVGs open in a browser.
Reports, streamed routing logs, available cProfile stats/phase timings, exact
input hashes and the unchanged authoritative package lock are included. The
artifact manifest hashes every packaged file; `SHA256SUMS.txt` covers the outer
release assets. Source wheel/sdist and both repositories' source ZIP snapshots
accompany the board ZIP when their build stages succeed.

Tag pushes create a GitHub **prerelease** with every asset produced by the build,
even if routing remains incomplete. This is a lasting, publicly downloadable
inspection snapshot, not a production acceptance. There are no implicit
Gerbers/drills or gate bypasses. `READ-ME-FIRST.txt` always labels the ZIP an
experimental inspection draft. A zero routing exit alone is insufficient:
Actions also requires a passing route report/ERC and independent KiCad refill/DRC
without violations or unconnected items. Missing reports, timeouts and failed
gates fail the run without discarding diagnostics. RF, USB, battery, assembly
and fabrication qualification remain separate.

An interrupted run may have only logs, provenance and partial profiles: the
router does not necessarily write a final PCB before finishing. Missing files
are not replaced by an old result. Cancelling the whole Actions job or losing
the runner can prevent even the final upload; artifacts cannot be guaranteed
after an externally killed job.

## Dependencies: one checkout, pinned URLs

Only CopperScript is checked out. The normal package resolver downloads the
`github.com/andenore/CopperLib` URL requirement from `copper.mod` into the
project-managed `.copper-cache/pkg/` directory. Its full Git commit and exact
asset inventory must match `copper.lock`. CI refuses a local CopperLib
replacement or a floating tag/branch. Library physical assets and custom
footprints use the same cache; no sibling directory, manual library checkout
or manually maintained KiCad library table is required.

Preparation fetches the pinned URL with locked resolution, then compiles both
examples offline and records provenance. It **never rewrites or refreshes
`copper.lock`**, nor accepts changed bytes through line-ending normalization.
Routing thereafter uses `--locked --offline`. A missing/unpublished commit,
inventory mismatch or cache corruption fails setup rather than substituting
the latest library. Push the pinned CopperLib revision before tagging
CopperScript; GitHub cannot fetch a commit that only exists locally.

The committed `.github/board-toolchain.json` pins Python 3.12.12 and the official
KiCad 10.0.6 x86_64 installer by SHA-256. The latter installs matching footprint
libraries, avoiding floating external footprint downloads. Actions are pinned
by full commit and Python build/test tools by exact version. The fresh Windows
runner checks out source with canonical LF bytes. The generated project keeps
its own exported footprints, so recipients do not need CopperLib or matching
global KiCad library registrations to inspect it.

Ensure Actions is enabled and repository/org policy permits the tag-only
publish job's `contents: write` permission. No PAT or self-hosted runner is
needed. Routing/build steps only have read permission. A separate tag-only job
gets the write token, verifies downloaded asset checksums, creates a private
draft release, uploads every asset, then publishes it as a prerelease. An upload
failure leaves a private draft rather than a partially advertised release.
Existing releases are never silently overwritten: resolve a failed draft
deliberately or use a new tag. There are no PR or `pull_request_target` triggers
and no persistent self-hosted machine exposed to contributed code.

## Budgets and honest failures

GitHub-hosted routing uses a 270-minute full-vertical budget and a 20-minute
nRF52 budget, leaving time within the six-hour job limit for installation,
source distributions and inspection. Manual runs may reduce the full-vertical
budget to 1–270 minutes. A complete attempt is not a guarantee that the search
finishes on a hosted runner; timeouts remain visible as failures. The wrapper
first interrupts the worker process group, allowing Python profiling finalizers
to save, then force-terminates it after 45 seconds if needed. Blocking native
calls or forced termination may leave no profile. `ci-process.json` records
timeout and forced termination separately. Independent DRC and every layer
export also have bounded timeouts. Profiling stays enabled; these timings are
not uninstrumented benchmarks. Runs serialize per branch/tag without cancelling
earlier runs.

## Local inspection packaging

The packaging stage can inspect an existing fresh run locally:

```powershell
uv run python scripts/ci_board_bundle.py package `
  --output build/ci-routing --dist build/ci-dist `
  --kicad-cli "C:\Program Files\KiCad\10.0\bin\kicad-cli.exe"
uv run python scripts/ci_board_bundle.py check --output build/ci-routing
```

CI routing generates `build/ci-routing/full-vertical/` and (if selected)
`build/ci-routing/nrf52-coin-cell/`. Do not mix previous runs into these trees.
The helper tests cover locked URL preparation, refusal of local replacements,
real process interruptions with saved cProfile data, deterministic self-contained
ZIPs, per-layer exports and refusal to publish corrupted assets or overwrite
releases. Native smoke testing of the original placed nRF52 fixture produced
all six SVGs, zero geometry violations and 52 intentionally unrouted items;
the inspection gate correctly rejected completion.

## References

- [GitHub workflow syntax and permissions](https://docs.github.com/en/actions/reference/workflows-and-actions/workflow-syntax)
- [GitHub Actions limits](https://docs.github.com/en/actions/reference/limits)
- [GitHub release REST API](https://docs.github.com/en/rest/releases/releases)
- [Official KiCad 10.0.6 release](https://github.com/KiCad/kicad-source-mirror/releases/tag/10.0.6)
- [KiCad CLI documentation](https://docs.kicad.org/10.0/en/cli/cli.html)

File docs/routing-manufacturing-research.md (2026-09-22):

# Routing-to-manufacturing research and implementation recommendations

Status: implemented baseline, researched 2026-09-22.

The manufacturing path was exercised end to end with installed KiCad 10.0.6:
KiCad DRC passed and the independent verifier accepted seven Gerber files, two
separated drill files, and one IPC-D-356 netlist before atomic publication.

This document records six separate research tasks for workflow steps 4–9. The
recommendations form one sequence: each stage consumes a typed, immutable result
from the prior stage, and no planning proxy can satisfy a manufacturing gate.

## 4. Congestion estimator and global router

**Research task.** Identify a deterministic method that predicts whether a
placed PCB is routable, assigns layers and corridors, handles capacity, and
does not pretend to create manufacturable copper.

**Findings.** FastRoute-style G-cell graphs are the established separation
between placement and exact routing. PathFinder's present-cost plus historical-
cost negotiation robustly resolves shared-resource congestion over successive
reroutes. OpenROAD similarly treats global routes as guides for a separate
detailed router and permits deliberate capacity derating.

**Recommendation and implementation.** Use a multilayer G-cell capacity graph,
multi-source A* for multi-terminal trees, and bounded PathFinder-style
negotiation. Represent width plus clearance as physical demand. Emit corridors,
proposed layer changes, overflow and stable fingerprints, never tracks or vias.
Implemented in `pcbir.routing`.

## 5. Placement–routing feedback loop

**Research task.** Determine how real routing results should improve placement
without destabilizing hard constraints or accepting a locally better but
incomplete route.

**Findings.** Routability-driven placement works well as an iterative two-stage
system: placement proposes geometry and routing supplies non-differentiable
congestion evidence. NS-Place explicitly optimizes net separation and then
legalizes. A router in the loop provides stronger evidence than another smooth
wirelength proxy.

**Recommendation and implementation.** Route every retained legal candidate;
select by a lexicographic vector led by unrouted nets and overflow; make bounded
hotspot-driven legal moves; reroute; accept only strict improvements; otherwise
roll back atomically and reduce movement. Stop on stagnation and certify the
winner with a fresh full global route. Implemented in `pcbir.routeflow`.

## 6. Specialized critical-net routing

**Research task.** Decide which nets must route before ordinary signals and
which claims a geometric router can safely make without a field solver or
electrical simulation.

**Findings.** High-speed guidance consistently treats differential geometry,
layer continuity, via count, uncoupled length, return paths, skew and impedance
as explicit design constraints. Protocol values cannot safely be hard-coded by
the router because stackup, device generation and context determine the actual
requirement. Geometric compliance is not electrical qualification.

**Recommendation and implementation.** Route only explicitly profiled nets as
critical. Order them by declared priority; route differential/CAN nets as
coupled bundles; handle clock, RF-feed, power and other constrained single nets;
materialize their exact copper first and lock it. Check representable geometric
budgets and retain explicit external impedance/SI/RF/current/thermal assumptions.
Implemented in `pcbir.critical`.

## 7. General detailed router

**Research task.** Select a practical first algorithm that converts global
guides into exact tracks and vias while respecting locked critical copper and
leaving a path toward richer PCB geometry.

**Findings.** TritonRoute's architecture separates pin access, track assignment,
initial routing, search-and-repair, and integrated DRC. Guide-aware maze/A*
routing plus deterministic rip-up/reroute is a stronger baseline than greedy
point-to-point traces. Pin access must be a first-class input.

**Recommendation and implementation.** Build legal pin-access nodes on a fine
multilayer grid, treat critical copper and component bodies as hard obstacles,
prefer but permit bounded deviation from global guides, grow multi-terminal
trees with deterministic A*, and repeat with present and historical resource
costs. Materialize exact `TrackSegment` and `Via` objects and fail partially
rather than claiming success with conflicts. Implemented in `pcbir.detailed`.

The baseline is orthogonal and grid based. It does not yet provide push-and-
shove, arcs, arbitrary-angle traces, plane fills, neck-down escape shapes or
post-route length tuning; these are later improvements behind the same IR.

## 8. Physical DRC and signoff

**Research task.** Define a release gate that distinguishes a violation-free
run from a complete run, supports controlled waivers, and becomes invalid after
any geometry change.

**Findings.** Production DRC must check both connectivity and pairwise physical
constraints. KiCad checks copper objects including pads, tracks and vias, but
tool success alone does not prove that every domain-specific analysis ran.
Safety standards and electrical simulation have scopes beyond geometric DRC.
Coverage therefore has to be reported independently from findings.

**Recommendation and implementation.** Run fail-closed checks over exact
physical IR for placement legality, opens, cross-net shorts/clearance among
pads/tracks/vias, copper edge spacing, track profile constraints, layer/length/
via budgets, and via structure. List unsupported analyses explicitly. A required
check that cannot run makes coverage incomplete and the decision fail. Bind
waivers to a stable finding fingerprint, and bind the signoff token to canonical
footprint, placement, copper, board, rule, policy and report digests. Implemented
in `pcbir.drc`; KiCad DRC runs again during export as a second engine.

The initial geometric engine conservatively bounds non-circular pads by their
maximum radius. This may reject legal dense geometry, but it cannot silently
relax clearance. Final solder-mask, zone, creepage, SI and thermal checks remain
visible unsupported coverage until their models exist.

## 9. Manufacturing export and independent CAM verification

**Research task.** Choose the authoritative export path and package checks that
minimize the risk of a valid IR producing incomplete or ambiguous factory data.

**Findings.** Gerber X2 remains a standard image transfer format; Excellon/XNC
remains common for drill data; IPC-D-356 carries an independent electrical test
netlist. KiCad 10 exposes non-interactive DRC and export commands. Writing a new
Gerber generator would add substantial format and qualification risk, while an
intelligent format such as IPC-2581 can be added later as another profile.

**Recommendation and implementation.** Treat the generated KiCad PCB as an
intermediate export artifact and pin a qualified KiCad major version. Require a
matching complete passing CopperScript signoff token; reject proxy footprints;
run KiCad DRC with violation exit codes; generate explicit-layer Gerber X2,
metric separated drill files, and IPC-D-356; parse outputs independently for
format, units, layer function/polarity, termination and expected file counts;
write SHA-256 checksums and a provenance manifest. Build in a sibling staging
directory and rename it into place only after all gates pass. Implemented in
`pcbir.manufacturing`.

## Compatibility contract and sequence

`pcbir.flow.run_routing_pipeline()` composes steps 4–8:

1. placement/global-route feedback produces one certified placement and global
   guide fingerprint;
2. critical routing consumes those guides and adds locked exact copper;
3. detailed routing preserves that copper and routes ordinary nets;
4. physical DRC digests the exact routed board and produces its signoff token;
5. manufacturing export accepts only that same board/token pair.

Failures and partial results remain inspectable but cannot advance the release
gate. Manufacturing output is never written into its requested final directory
until both KiCad and the independent CAM parser succeed.

## Primary sources

- [PathFinder negotiated-congestion router](https://janders.eecg.utoronto.ca/1387_2015/readings/pathfinder.pdf)
- [OpenROAD global router](https://github.com/The-OpenROAD-Project/OpenROAD/blob/master/src/grt/README.md)
- [OpenROAD detailed router / TritonRoute](https://github.com/The-OpenROAD-Project/OpenROAD/blob/master/src/drt/README.md)
- [NS-Place: net-separation-oriented PCB placement](https://arxiv.org/abs/2210.14259)
- [USB-IF USB 2.0 specification](https://www.usb.org/document-library/usb-20-specification)
- [TI high-speed differential layout guidance](https://www.ti.com/document-viewer/lit/html/SLLA653/GUID-A4F1CD83-9D39-45B1-B7A5-0E03429E4305)
- [KiCad 10 PCB Editor and DRC documentation](https://docs.kicad.org/10.0/en/pcbnew/pcbnew.html)
- [KiCad 10 command-line interface](https://docs.kicad.org/10.0/en/cli/cli.html)
- [KiCad board file format](https://dev-docs.kicad.org/en/file-formats/sexpr-pcb/)
- [Ucamco Gerber and XNC specifications](https://www.ucamco.com/en/guest/downloads/gerber-format)
- [IPC-2581C scope](https://www.ipc.org/TOC/IPC-2581C-toc.pdf)

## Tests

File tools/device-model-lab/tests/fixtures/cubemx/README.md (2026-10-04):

# Synthetic STM32CubeMX fixture

This directory is a minimal, synthetic XML tree shaped like a CubeMX
installation. It is test data only and is not copied from or redistributed as
an ST database. Real imports must point at a locally installed CubeMX
`db/mcu` directory.

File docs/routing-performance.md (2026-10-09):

# Routing performance and optimization assessment

## Package-access via search

The preferred plane-contact search stops considering farther via rings once
their minimum possible pad-to-via distance exceeds the best legal choice already
found. The existing 2 mm search cap and exact copper clearance checks remain.
This preserves candidate selection because a route cannot be shorter than its
pad-to-via displacement.

On the full-vertical `candidate-00` package-access preflight with both hard
macros, the same inputs and unprofiled process took 248.3 s with the previous
search and 121.7 s with this pruning. The three plane-stitch passes changed from
67.5/69.2/69.9 s to 21.4/21.3/33.8 s. Both results were ready with 113 plane
contacts, the same critical-route fingerprint, and the same native board and
report digests. These are single-run measurements, not a full-route timing or
manufacturing signoff claim. Ignored diagnostic reports are in
`build/package-access-timing-{unpruned,pruned}-20261009.json`.

## Profiling future runs

Package preflight now negotiates ordinary escape patterns after a bounded
initial pair-search tier (default 6,000 aggregate expanded states per pair/pass),
before committing to historical full-budget searches. If incomplete, it retries
the original pattern at full budget. `--package-initial-pair-states 0` provides
the comparison/disable mode; `--package-pattern-trials 0` also disables staging.
Pass these through the generic build wrapper after `--`. Reports include
`package_access.search_tiers` with all actual probe/revalidation work and the
selected tier. A limited failure is not evidence that no legal route exists.
The read-only run summary includes `critical_expanded_states` across completed
groups, including discarded pattern/probe work, plus tier/fallback details. Do
not add tier totals to the group totals again. The comparison helper allows the
staging knob as an explicit intervention, while preserving other budget,
quality, provenance and uninstrumented-timing checks.
See [the plan and acceptance criteria](routing-search-speed-plan.md).

The complete workflow now enables standard-library `cProfile` function profiling
and streamed phase events by default; no additional dependency is required:

```powershell
make EXAMPLE=full-vertical route
```

Each fresh ignored `build/full-vertical/runs/<UTC-run-id>/` contains:

- `routing.prof`: complete Python call statistics, including callers/callees.
- `profile-summary.txt` and `profile-summary.json`: top 50 functions by self time
  and cumulative time, plus call counts.
- `phase-timings.json`: paired start/finish events, inclusive elapsed spans,
  trial decisions, malformed-event count and unfinished phases.
- `routing.log`: the original events and diagnostics.
- `run.json`: actual launch and routing commands, Python/platform/CPU information,
  Git commit and tracked-diff hash, input hashes, profile status and router exit code.

Direct `python -m copperscript route-board ...` remains unprofiled. To profile
another module invocation, preserving failure exit codes:

```powershell
New-Item -ItemType Directory -Force build/profile | Out-Null
uv run --no-sync python -m pcbir.profiling --output build/profile/routing.prof `
  --module copperscript -- route-board examples/valid_board/board.copper `
  --allow-proxy-footprints --report build/profile/route-report.json `
  -o build/profile/board.kicad_pcb
```

The proxy-footprint invocation above is only a small diagnostic example, not the
full-board or manufacturing workflow. Existing profile files can be inspected
with `uv run --no-sync python -m pstats <path-to-routing.prof>`.

Profiling is observational, not signoff evidence. The router's exit 1 remains
exit 1, even if profile collection succeeds. This wrapper intentionally does not
use `python -m cProfile`: its utility catches `SystemExit`. A forcibly terminated
process may leave no profile; the manifest reports `missing`, not success.
Normal exceptions and in-process interrupts attempt to save partial statistics;
they do not establish a completed routing result. Profiling/report failures are
recorded separately and cannot replace the router's exit status.

Function profiling adds overhead, potentially substantial in a function-call-heavy
maze search. Cumulative times include callees and must not be summed; phase spans
also overlap when trials contain whole pipelines. The profile covers the routing
Python process, not KiCad's internal CPU work; subprocess wait time and the
independent-KiCad phase are visible, but native KiCad internals are not attributed.
See the [Python profiling documentation](https://docs.python.org/3.13/library/profile.html).

For uninstrumented wall-time comparisons, keep progress events but disable
function instrumentation:

```powershell
make EXAMPLE=full-vertical route PROFILE=none
```

Inspect a run (including an unfinished run) without modifying its artifacts:

```powershell
uv run --no-sync python -m pcbir.routing_benchmark summarize "build/full-vertical/runs/<run-id>"
```

For the O1b comparison, first complete the function-profile run, then run these
uninstrumented variants sequentially on the same otherwise idle machine. Repeat
in alternating order before drawing a wall-time conclusion:

```powershell
make EXAMPLE=full-vertical route PROFILE=none EXTRA_ROUTE_ARGS=--no-incremental-placement-repair
make EXAMPLE=full-vertical route PROFILE=none
uv run --no-sync python -m pcbir.routing_benchmark compare "build/full-vertical/runs/<baseline-id>" "build/full-vertical/runs/<candidate-id>"
```

`routing_benchmark` checks named failed signal/critical nets, pending ground,
duplicate-land and fanout pads, native hard finding categories/affected nets,
required native-check coverage, overflow and independent KiCad findings. It
reports selected-route length/via/layer metrics rather than trading them away
implicitly. A comparison with new failures, missing final data, changed recorded
inputs/tools/settings or either run function-profiled produces **no timing ratio**.
Exit 0 means eligible for timing review, 1 means a quality regression, and 2 means
incomparable/incomplete data or an input error; none means manufacturing signoff.
The standalone `summarize` command returns 0 for valid observations, even if a run
is still active, and clearly marks its completion state.

The two explicit repair switches (`--no-incremental-placement-repair` and
`--zone-dependency-expansions`) are interventions under test and may differ. Other
settings, including search budgets, must match. Runtime provenance does not hash
all footprint files or capture machine load, so an eligible ratio still requires
external-library verification and repeated measurements. This is a review aid,
not automatic optimization acceptance. Structured progress provides completed
full/incremental trial and subset/probe counts, including rejected work; a legacy
plain log uses a clearly labelled final-report lower bound instead of inventing
zero work. General-area expanded maze states and peak memory are not yet recorded
by this tool; paired critical searches do report their expanded states.

### Per-net area progress

With `--progress`, detailed routing emits `detailed_pass` and `detailed_net`
start/finish events. A net starts **before grid construction**, so an unfinished
event identifies the active net even if grid preparation or a repair is slow.
Pass events include ordinary-net counts and provisional failed-net names. Net
events include pass/ordinal (where applicable), pad count, requested pitch and
search budget, layer/direction preferences, and final tentative connectivity,
track/via counts and diagnostics. These events do not change the IR, selected
copper, fingerprints, JSON reports or exports.

Repair stages are `failed_first`, `soft_merge`, `soft_ripup`, `evicted_net`
(with its repair owner), and `final_retry`; a normal pass uses `pass`.
`detailed_repair` and `detailed_neutral_fallback` events state whether their
candidate was selected. The same observer is forwarded through placement trials
and local zone dependency reroutes. There are no per-expanded-state callbacks.
The requested budget is not an aggregate net budget: branch searches, guide
expansions and bounded pitch refinements can perform several searches.

Every finished net event also carries a process-local `search_identity`.
Within one repair stage, a search repeated with identical inputs is answered
from a bounded memo (`search_reuse: "hit"`, with the original `reused_search_seconds`); a
`detailed_search_reuse` summary follows `detailed_repair`. The attempt is the
identical earlier result, so copper, reports and fingerprints do not change.
`--search-reuse-entries 0` disables it for comparison runs; see
[exact repair-search reuse](repair-search-reuse.md).

Follow a running build in PowerShell:

```powershell
Get-Content "build/full-vertical/runs/<run-id>/routing.log" -Tail 20 -Wait
```

The read-only summary reports `detailed_net_attempts`,
`failed_detailed_attempts`, `detailed_attempt_stages` and
`reused_detailed_attempts`, including tentative and rejected work. Counts are
**not** unique accepted nets or DRC closure.
Older logs without completed per-net events have unknown (`null`) attempt
counts. Interrupted attempts remain in `work.unfinished`, without an invented
duration or success; a forcibly killed Windows process may also leave the
original manifest unfinalized. Check process liveness as well as its status.
Inclusive phase durations overlap and are not percentages or an ETA.

Compare repeated runs with identical source/lock, actual footprint files, options,
KiCad/Python versions and machine load. The recorded hashes do not fingerprint
every footprint or external tool; record CopperLib revision and KiCad version
alongside a benchmark. Compare connectivity, exact geometry/fingerprints, DRC,
pending escapes, wire length and via counts as well as time. Report wall time and
peak memory; distinguish cold and warm runs. Do not infer speedups by comparing
instrumented and uninstrumented times. An out-of-process sampler such as
[py-spy](https://github.com/benfred/py-spy) is a useful lower-overhead cross-check,
but is not a required dependency or enabled by the shared build workflow.

## Evidence available on 2026-10-02

The latest full run (`20261002T080102482942Z`, routing code `31e515e`) took
**3,985.613 seconds / 66.4 minutes**. Its report contains three full ground-feedback
evaluations after the initial routing pipeline: accepted current-placement
escape, rejected current-placement escape, and accepted `C_CC` 270-degree rotation.
Thus four complete pipeline evaluations were used for a small number of remaining
ground contacts. This establishes repeated work, not a measured breakdown of the
66 minutes: that run predates continuous profiling and streamed phase events.

An earlier pass-13 phase-timed run, using an earlier pipeline order, measured:

| Stage | Seconds |
| --- | ---: |
| Placement/global | 121.067 |
| Critical routing | 87.962 |
| Fanout | 3.720 |
| Detailed routing | 1,247.980 |
| Initial physical closure/native DRC | 9.193 |
| Ground feedback, including local repairs | 117.225 |
| Independent KiCad verification | 3.640 |

Total elapsed was 1,603.499 seconds; detailed routing accounted for about **78%**.
The stages shown do not account for every setup/finalization second. This is
historical evidence, not a current-run profile or a prediction of future timings.
The retained pass-13 timing file lives in the task's review outputs; the latest
full run's manifest/report live in ignored `build/` and are not portable repository
fixtures.

The earlier R9 15-second/734-sample snapshot attributed 27.4% of inclusive samples
to via checks, 13.1% to track checks and 12.8% to neighbor generation. These categories
overlap and cover one routing interval, not the whole board. Search-local full-span
via caching and exact rectangular-outline fast paths have already been implemented;
they must not be counted again as proposed new optimizations.

## Recommended order

1. **Reduce the number of whole-board evaluations.** Extend the existing local
   repair in `escape_feedback.py` to a dependency-bounded repair for small placement
   moves/rotations: invalidate moved-package exits, incident nets and interfering
   copper; expand that affected set if repair collides with additional nets.
   Preserve unrelated copper byte-for-byte and locked critical-group ownership;
   validate native connectivity/DRC and the final filled KiCad board. Recompute
   congestion/clearance state for the affected transaction and fall back to a full
   pipeline if dependency bounds or validation fail. Reserve required ground access
   alongside package exits where appropriate, so ordinary routing cannot consume
   the last escape. Local rip-up and early contact screening already exist; improve
   those mechanisms rather than adding another duplicate repair controller.

2. **Reduce exact-check/allocation work in measured hot paths.** Audit
   `detailed._search_once`, `_Grid.point` and `RoutingClearanceIndex`. Candidate
   targets are repeated `Point`/rounded-shape allocation, immutable pad/keepout
   geometry reconstruction, and broad-phase bucket tuning. The clearance index
   already has spatial hashing and exact narrow-phase checks; searches already
   cache track/via legality, heuristics and obstacle queries. Cache static geometry
   separately from changing routed copper. Any reuse must include placement/grid,
   net width/clearance, via physical span and copper revision; otherwise it can
   create false legal routes. Net-specific grid coordinates mean grids cannot be
   blindly shared. Optimize only where full profiles show significant self time
   or excessive calls, retaining tangency, rotated-pad and all-layer-via tests.

3. **Reduce maze states, not just time per state.** Tighten adaptive guide corridors
   and coarse-to-fine search around the existing progressive guides; expand them
   on failure. Precheck feasible ports/layer reachability before expensive repair
   searches. Evaluate multi-terminal tree-target indexing where target sets are
   large; cached minimum-distance heuristics still scan targets on first use.
   Measure expanded states, guide expansions and budget failures. Retain the
   wide/neutral fallback and exact final geometry checks. Do not claim a speedup
   by shrinking budgets until a formerly routable board simply fails faster.

4. **Parallelize independent candidate evaluation with processes.** Independent
   placement/global candidates and separately routed trial boards are natural
   units. Workers need isolated immutable inputs and their own copper/congestion
   state and KiCad temporary directories. Rank results in original deterministic
   candidate order, not completion order; preserve sequential acceptance semantics
   and discard/recompute speculative candidates based on an obsolete incumbent.
   Cap workers and total speculative work/memory. The latest ground trials depended
   on the previous accepted board, so they cannot all be dispatched unchanged.
   Trial-board serialization is nontrivial (`MappingProxyType` metadata); use a
   tested portable snapshot or reconstruct locked inputs in each worker.

5. **Consider native hot kernels after profiling the above.** Compact search-state
   storage and a compiled geometry/neighbor kernel may help if Python call/allocation
   overhead remains dominant. Keep the existing Python implementation as an oracle;
   prove integer-overflow, exact-clearance and deterministic tie-break behavior
   before replacing it. This is higher implementation risk than avoiding reruns.

These are ranked code-informed recommendations, not implemented router changes or
measured speedup claims for the full board. Implementation status and the detailed
sequence are tracked in the [optimization todos](routing-optimization-todo.md).

## Where parallelism is unsafe or unlikely to help first

Per-net threads are not a straightforward speedup: ordinary searches share mutable
usage, congestion history, rip-up decisions and committed copper. Independent
searches on the same snapshot can produce mutually conflicting routes, requiring
conflict detection, deterministic reconciliation and rerouting. Spatial partitions
likewise require boundary/halo ownership and cross-partition repair. Treat these as
algorithm changes, not a `ThreadPoolExecutor` wrapper.

The usual GIL-enabled CPython build does not run CPU-bound Python bytecode in
parallel through ordinary threads. Processes can bypass that limitation, but need
picklable inputs/results and an importable entry point; Windows spawn costs and
memory copies matter. See [Python's process-executor documentation](https://docs.python.org/3.13/library/concurrent.futures.html#processpoolexecutor).
Parallel rendering/logging or independent CAM checks may improve convenience, but
the historical few seconds of KiCad verification do not justify making them the
first optimization target. No parallel router or relaxed correctness gates have
been enabled by this profiling change.

## Work list and acceptance gates

- [x] Default function profiles, raw call graph and bounded readable/JSON summaries.
- [x] Phase/trial elapsed spans with unfinished-phase accounting.
- [x] Provenance, explicit unprofiled mode and truthful routing exit status.
- [x] Real-module failure and routed-artifact byte-identity regression tests.
- [ ] Capture a complete current-board function profile and uninstrumented baseline.
- [x] Extend affected-net transactional repair; compare full-pipeline count on retained fixtures.
- [x] Add read-only, regression/provenance-aware run summaries and comparison gates.
- [ ] Finish profiled current-board routing and repeated uninstrumented O1b comparisons.
- [ ] Optimize confirmed allocation/geometry hot spots with exact-predicate regressions.
- [ ] Evaluate adaptive search changes against expanded-state and routability metrics.
- [ ] Prototype bounded deterministic process-level candidate evaluation; measure
  IPC, peak memory, speculative waste and worker-count scaling.
- [ ] Consider native kernels only if remaining profile evidence warrants them.

Accept an optimization only if connectivity and hard DRC do not regress, package
and critical constraints remain satisfied, repeated results are deterministic, and
uninstrumented measurements show improvement. Changed routing algorithms may
produce different legal geometry; profiling alone must not change artifact bytes.
The latest board still has non-library dangling-copper warnings and signoff work;
performance telemetry does not remove those remaining gates.

## First optimization: bounded local dependencies

O1a is implemented in `escape_feedback.py`. The existing local ground repair first
displaces the exact ordinary-net blockers of a prospective escape. If rerouting
that subset fails, it can now make a temporary probe without other ordinary area
copper, identify further blockers with the exact clearance index, and retry the
expanded net set with all unrelated copper restored. The probe itself is never
committed. Critical copper, fanout and accepted ground contacts remain fixed.
The existing hard-DRC/connectivity comparisons and full-reroute fallback remain.

The default allows two dependency expansions and respects the existing total local
blocker limit. `--zone-dependency-expansions 0` disables just the new expansion,
not the original local repair. The complete workflow exposes the same option:

```powershell
make EXAMPLE=full-vertical route PROFILE=none EXTRA_ROUTE_ARGS="--zone-dependency-expansions 0"
make EXAMPLE=full-vertical route PROFILE=none EXTRA_ROUTE_ARGS="--zone-dependency-expansions 2"
```

Compare on the same inputs and machine load, recording both accepted geometry and
rejected work. Progress adds inclusive `zone_subset_search` spans with `kind`
(`transaction` or `probe_only`), affected nets, expansion count, failed nets and
overflow. Reports identify `local_dependency`, `incremental_placement`, `full_pipeline` or `early_screen`
strategies; accepted local attempts record repaired nets and expansion rounds.
Failed local searches are visible in progress/profile data, not fabricated as
accepted report attempts. Process parallelism and full-board before/after
measurements are still pending.

## Incremental placement repair

O1b adds conservative placement transactions in `incremental_placement.py`.
For a legal move or allowed rotation of a noncritical, noncrowded component,
invalidate its incident ordinary nets. Rebuild affected zone-net contact trees
(there is not yet pad-level ownership for shared ground contacts), retaining
critical return vias. Exact clearance checks discover further ordinary nets
blocked by moved pads, footprint keepouts or the new early contacts. Repair that
bounded dependency cone with unrelated copper restored and critical copper fixed.

Global guides are recomputed from the new clean placement, not relabelled from
old coordinates. Critical/access stages are rebased on their retained actual
copper; obsolete fanout domain statistics and historical placement trials are
cleared. Whole-board land closure, hard DRC and signal-connectivity nonregression
still gate acceptance, which requires fewer pending ground contacts. Independent
KiCad refill/DRC is still performed on final exported geometry; no fill/signoff
evidence is reused across placements.

Moved critical endpoints, rigid macros, crowded package-access owners, missing
ownership evidence, illegal placement, failed fresh global routing and excessive
or unsuccessful repair cones take the original full-pipeline fallback. This first
scope avoids rebuilding unrelated ordinary maze routes, not all global/DRC work.
To compare against full placement trials while retaining local same-placement
repair, run:

```powershell
make EXAMPLE=full-vertical route PROFILE=none EXTRA_ROUTE_ARGS=--no-incremental-placement-repair
make EXAMPLE=full-vertical route PROFILE=none
```

Progress records `zone_incremental_trial`, `zone_moved_global` and fallback reasons
in `zone_incremental_guard`. Report trials record `changed_references`, `repair_nets`,
`rebuilt_zone_nets` and dependency expansions. Regression fixtures exercise real
incident-net routing, unchanged critical geometry, a 45-degree rotation and access
rebasing. The same controlled improving move needs zero full-pipeline evaluations
with incremental repair and one without it. No full-board wall-time speedup has
yet been measured; O1d benchmarking remains open.

## Python-first geometry and search allocations

The 2026-10-05 full-board profile is saved at `7d7673f` in ignored
`build/full-vertical-staged-indexed-20261005/`. It finished with three ordinary
failures (`GNSS_TX`, `I2C_SDA`, `V3V3`), 34 independent KiCad unconnected items
and one other violation. It is not fabrication-ready.

The next increment remains pure Python: Fraction-free integer clearance
decisions, lazy rational measurements only for DRC violations, immutable
placed-obstacle/grid identity reuse, and elimination of duplicate query rays
and ignored endpoint allocations. Exact tangency, odd-width half-nanometre
thresholds, full via spans, deterministic search selection and reporting are
unchanged. See the [implementation and measurement record](python-routing-optimization-plan.md).

Mixed-shape and passing copper-spacing fixtures show approximately 3.26x and
9.03x kernel speed ratios, with zero Fraction constructions on their Boolean
paths. These are alternating unprofiled observations under concurrent test load,
not full-board speedups. Matched full-board timing and closure comparisons are
still pending; compiled alternatives remain deferred until Python algorithm,
data-structure and allocation opportunities have been measured and used.

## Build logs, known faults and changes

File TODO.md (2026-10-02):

# CopperScript roadmap

This list tracks the implementation sequence for routability-aware PCB
placement. A checked item means the behavior is implemented, documented, and
covered by automated tests; it does not mean the generated board has passed the
later Route or Verify gates.

## Placement engine

- [x] Expand the physical constraint model with courtyards, keepouts, placement
      regions, legal orientations, fixed/relative placement, alignment,
      component groups, and priorities. Lower typed `.copper` constraints into
      physical IR.
- [x] Build hierarchy-aware clustering from module provenance, explicit groups,
      interfaces, and proximity constraints. Preserve cluster membership and
      anchors in placement reports.
- [x] Replace component-center estimates with transformed physical pad
      coordinates. Add orientation-aware wirelength, per-layer crossing, escape,
      and routing-capacity metrics.
- [x] Add a deterministic analytical global-placement phase using smooth
      wirelength, density spreading, semantic group cohesion, and legal discrete
      orientations.
- [x] Add hybrid legalization: fast grid/Hanan-style legalization for ordinary
      rectangles plus bounded exact repair for small dense conflict regions.
- [x] Add detailed refinement with incremental moves, swaps, rotations, and
      periodic coarse-routing feedback while preserving all hard constraints.
- [x] Generate multiple deterministic candidates and return the Pareto frontier
      ranked by wirelength, crossings, congestion, constraint margin, and
      estimated vias. Expose candidate summaries through the CLI and JSON report.

## Completion criteria

- [x] All existing and new tests pass.
- [x] The full-vertical acceptance design produces deterministic, legal
      candidates.
- [x] Generated KiCad PCB files are accepted by the installed KiCad CLI when it
      is available.
- [x] Route remains `not_run` and Verify remains `blocked` until actual copper
      and sign-off implementations exist.

Verified on 2026-09-21 with the full test suite, byte-identical repeated
full-vertical artifacts, and KiCad 10 CLI parsing/DRC. The acceptance board
uses proxy footprints and has no routed tracks, so KiCad DRC violations are
expected and do not satisfy the future Route or Verify gates.

## Routing-to-manufacturing pipeline

- [x] 4. Add a deterministic multilayer congestion estimator/global router
      using capacity guides, multi-source A*, and negotiated congestion. Keep
      guide geometry separate from exact copper.
- [x] 5. Add a transactional placement–global-routing feedback loop with
      bounded legal movement, rollback, convergence control, and full-route
      certification.
- [x] 6. Add profile-driven critical-net routing for differential pairs,
      clocks, buses, RF feeds, and power routes before general routing.
- [x] 7. Add a guide-aware general detailed router with pin access, vias,
      exact tracks, deterministic rip-up/reroute, and cleanup.
- [x] 8. Add fail-closed physical DRC, coverage reporting, waivers, and signed
      signoff tokens tied to exact manufacturing geometry.
- [x] 9. Add gated manufacturing export, release manifests, checksums, and an
      independent CAM re-import/verification pass.

## Global-routing and package-escape refinement

The detailed implementation sequence and remaining acceptance work are in
[global-routing-and-escape-todo.md](docs/global-routing-and-escape-todo.md).
Steps 1–2 are being validated against the full-vertical board; later steps
cover simultaneous escape assignment, global–detailed feedback, and board
closure. This refinement does not change the board's manufacturing gate.

## Production-readiness program

Each item has its own research record and acceptance tests. Work proceeds in
dependency order; a checked item means its implemented scope is documented,
tested, integrated with the common physical IR, and exercised against KiCad
where relevant. It does not imply third-party certification.

- [x] P1. Copper zones and planes: typed zone/keepout IR, priorities, thermal
      relief and island policy; deterministic KiCad emission; content-bound
      fill provenance; and an authoritative, pinned KiCad refill before DRC and
      manufacturing. Native filling remains a preview feature until it passes
      differential tests against the qualified manufacturing filler.
- [x] P2. Arbitrary-angle and push-and-shove routing: exact integer geometry,
      walkaround/hugging, deterministic shove transactions, rollback, acute-
      angle cleanup, locked-object behavior, and detailed-router integration.
  - [x] Exact integer predicates and rational squared-distance comparisons.
  - [x] Deterministic visibility-graph walkaround on expanded obstacle envelopes.
  - [x] Atomic recursive line shove with locked-track rollback.
  - [x] Atomic recursive via shove with locked-object rollback and detailed-router
        any-angle line-of-sight cleanup.
  - [x] Coupled-bundle shove and acute-angle cleanup.
- [x] P3. Differential-pair completion: coupled pad escape, fanout, via-pair
      transitions, uncoupled-length accounting, length/skew measurement,
      bounded trombone tuning, return-path requirements, and DRC.
  - [x] Atomic paired fanout, centerline offset routing, paired transitions,
        coupled/uncoupled measurement, skew and uncoupled-budget enforcement.
  - [x] Local bounded trombone tuning, return-via rules, and field-solver
        evidence binding.
- [x] P4. Stackups and via technology: arbitrary copper/dielectric stacks,
      material properties, through/blind/buried/microvia definitions, legal
      spans, aspect/annular constraints, layer transitions, and KiCad mapping.
  - [x] Ordered copper/dielectric stack, material properties, named through/
        blind/buried/microvia catalog, span/ring/aspect validation, and KiCad
        multilayer/via-kind mapping.
  - [x] Critical and detailed routers select a legal named technology from the
        same catalog consumed by validation and export.
- [x] P5. Exact-shape physical DRC: pad and track shape primitives, polygonal
      broad/narrow phases, exact clearance/intersection/connectivity, concave
      board edges, zones, stable markers, coverage, and differential checks.
  - [x] Shared exact integer segment/capsule predicates and exact copper-spacing
        decisions with deterministic markers.
  - [x] Shape-accurate rotated pads and normalized zone fills, spatial broad
        phase, incremental/full equivalence contract, concave-edge checks, and
        differential geometry checks. Copper arcs remain unavailable in the IR
        and therefore cannot be silently approximated.
- [x] P6. Artwork, assembly, and fabrication DRC: solder-mask and paste rules,
      silkscreen clipping/clearance, courtyard and component-side checks,
      hole/slot constraints, copper balance and documented fab-profile gates.
  - [x] Provenance-bearing process capabilities and separate fabrication,
        stencil, and assembly decisions for drill, mask-web, paste-area,
        courtyard, and height checks.
  - [x] Derived mask/paste/silkscreen geometry, slots, explicit edge-plating
        capability, orientation marks, copper balance, and release-gate
        integration. Unsupported artwork arcs make the process gate incomplete.
- [x] P7. Engineering analyses: stackup-driven impedance estimates, return-path
      continuity, conservative SI/PI checks, DC current/voltage-drop and thermal
      estimates, creepage/clearance profiles, explicit model validity and
      external-solver handoff without overstating signoff.
  - [x] Evidence-grade/status/scope/validity result contract, deterministic DC
        trace resistance and sourced creepage screening.
  - [x] Impedance/delay, return-path, via/DC network, thermal, and external
        solver evidence adapters.
- [ ] P8. Independent CAM qualification: second-tool parsing/rendering and
      comparison, layer/drill/netlist reconciliation, polarity and extents,
      golden corpus, version-pinned qualification matrix, and release evidence.
  - [x] Fail-closed qualification states, exact tool identities, immutable
        inventory hashes, safe input limits, and independent normalized-parser
        agreement contracts.
  - [x] Pinned PyGerber 2.4.3 adapter, isolated libgerbv CLI adapter, strict
        metric-XNC normalization, adversarial fixtures, and optional fail-closed
        publication binding.
  - [x] Reconcile drill multisets and IPC-D-356 net partitions to signed
        physical IR.
  - [x] Bind drill and IPC-D-356 reconciliation to CAM-required release;
        verify KiCad 10 Cartesian-up output, pad locations, and via records.
  - [x] Gate CAM-required release on a freshly run, hashed positive/negative
        corpus; record the corpus hashes in the release manifest.
  - [ ] Qualify an installed libgerbv build and expand the official golden
        corpus/matrix, including polarity and metamorphic render comparisons.
- [ ] P9. Frontend and full-board closure: express every new rule in `.copper`,
      lower it into typed IR, resolve real CopperLib footprints, then place,
      route, DRC, export and independently verify the full acceptance board.
  - [x] Normalized requirement/target/preference/assumption/external modes and
        fail-closed constraint consumer/verifier coverage.
  - [x] Constraint ownership metadata and critical routing profiles have
        concrete syntax and typed physical lowering.
  - [x] Content-addressed package lockfile and whole-board footprint audit.
  - [x] Complete the nRF52832-QFAA QFN48 bond map from the official Nordic
        pin table.
  - [x] Complete STM32G0C1RET6 LQFP64-GP bonds from ST DS13564 Table 12 and
        connect VBAT/VREF+.
  - [x] Correct the nano-SIM C7 I/O mapping and select an exact GCT connector;
        fail closed on unsupported embedded footprint keepouts.
  - [x] Replace the placeholder USB choke with orderable Coilcraft
        0603USB-601MLC and its verified pin-compatible KiCad land pattern.
  - [x] Preserve simple embedded footprint copper keepouts through import,
        physical IR, placement/routing checks, KiCad export, and signoff;
        installed KiCad audit now resolves 19/23 assets.
  - [x] Replace the virtual 5 V source with an orderable power-only USB-C
        receptacle and separate CC1/CC2 sink pull-downs; installed KiCad audit
        now resolves 20/24 assets.
  - [x] Use the Tag-Connect TC2050 bare-PCB SWD target for both processors;
        preserve KiCad connector contacts and footprint-local placement
        keepouts through import, placement checks, physical DRC, and export.
        Installed KiCad audit now resolves 21/24 assets.
  - [x] Generate the MAX-M10S-00B 18-land footprint and T-shaped stencil from
        u-blox UBX-20053088 R05 Tables 44-45; KiCad parses the artifact and
        the two-root footprint audit resolves 23/24 assets; the JLCPCB/EasyEDA
        EG800G-EU physical pattern is covered, but its full electrical model
        and Quectel mechanical/stencil signoff remain open.
  - [ ] Qualify the user's 5 V / 2 A input target with a measured worst-case
        power budget. Decide between a 5 V / 2 A USB-PD contract and a 3 A
        Type-C advertisement while limiting actual draw to 2 A; add input
        overvoltage, inrush, ESD, and reverse-current protection.
  - [ ] Resolve the reported real CopperLib/KiCad footprint gaps and complete
        acceptance-board placement, routing, DRC, manufacturing, and CAM closure.

### Future improvement: full-vertical stackup and copper-fill policy

Proposed on 2026-10-02; not implemented or qualified. Adding this work to the
roadmap does not change the current board, routing run, or manufacturing gate.

- [ ] Evaluate and qualify a six-layer `Signal / GND / Signal / Signal / GND /
      Signal` stack against an actual JLCPCB laminate/copper specification.
      Reserve In1.Cu and In4.Cu as common-GND reference planes, with only
      manufacturer-required RF exclusions. Moving In4.Cu from signal routing
      to GND reduces routing capacity and requires a complete fresh reroute.
- [ ] Express explicit layer roles and distinguish dedicated reference planes
      from auxiliary signal-layer pours; replace plane-role inference from
      zone coverage. Add frontend support for local zone boundaries, stitching
      policy, island removal, and per-pad connection overrides, lowered into
      physical IR rather than electrical connectivity or schematic geometry.
- [ ] Add selective stitched GND fill on F.Cu/B.Cu, retaining the provisional
      0.5 mm board-edge inset. Remove all unconnected fill islands and reject
      ineffective narrow slivers. Use assembly-appropriate thermal reliefs for
      ordinary solder pads and solid connections for ground vias and explicitly
      designated RF/power ground lands. Keep default via/pad overlap forbidden;
      qualified via-in-pad remains an explicit opt-in, never a fill side effect.
- [ ] Keep In2.Cu primarily for signals/USB, without blanket fill initially.
      Use In3.Cu for general signals and localized power distribution; evaluate
      any auxiliary inner-layer GND fill only after routing and reference-path
      review, not as a substitute for a continuous plane.
- [ ] Define local V5 input, V3V8 modem, and V3V3 distribution regions. Size
      copper necks and vias against the declared 2 A input budget, actual rail
      currents, modem transients, voltage drop and thermal requirements. Protect
      the selected regulator's switching-node, feedback and capacitor-return
      geometry; do not flood low-current SIM/1.8 V nets indiscriminately.
- [ ] Add source-backed Johanson antenna clearances and Nordic RF matching
      keepouts before enabling generic fill. Preserve the reference C3
      (`C_BT_MATCH`) ground path through nRF52832 VSS pin 31 rather than allowing
      automatic fill to bypass it; honor required inner-layer copper exclusions.
      Review cellular and GNSS feed ground geometry separately.
- [ ] Qualify USB 90-ohm differential and applicable RF 50-ohm feed geometry
      using the selected stackup, including nearby-fill clearance. Existing USB
      width/gap values remain provisional; the Nordic chip-side matching net
      must not be treated as a generic 50-ohm transmission line.
- [ ] Reserve off-pad ground access and return vias during routing, then refill
      and iterate on actual connected copper. Accept only fresh native/KiCad
      DRC, zero unintended via/pad contacts, connected GND regions/planes,
      reviewed critical return paths, and assembly/copper-balance checks.
      Record profiled full rerouting and individual-layer plots; zone creation
      alone is neither continuity evidence nor manufacturing signoff.

### Physical hard-macro follow-up (CS-136)

- [x] Specify separate electrical/physical ownership, pinned footprint/net roles,
      rigid rotations, immutable copper, ports and protected return paths.
- [x] Implement transactional bind/place/materialize, pad-backed ordinary-router
      ports, private same-net/rip-up reservations and locked KiCad export.
- [x] Test Nordic matching Gerber strokes plus a provisional Johanson tee/corner
      probe at 0/45 degrees with native and KiCad DRC.
- [ ] Support arbitrary via/free boundary ports in global, package-access,
      critical and detailed routing. Account for macro occupancy before coarse
      guides; do not treat owner copper as disposable fanout.
- [ ] Add hierarchical module-to-macro frontend selection and movable-macro
      placement feedback with complete boundary revalidation.
- [ ] Qualify complete Nordic support circuit, actual reference ground/copper,
      Johanson land/tee/corner geometry, via fence, stackup, impedance, tuning and
      enclosure; then integrate into the full-vertical design and reroute.
- [ ] Add explicit qualified local zones/arcs/mirrored macro variants and
      independent export/fill/CAM verification; never infer RF qualification.

### Program completion criteria

- [x] Research recommendation and source record exists for P1–P9.
- [ ] Every new geometry type participates in serialization, fingerprints,
      KiCad export, DRC coverage, and stale-signoff invalidation.
- [ ] Tests include unit geometry, adversarial regression, determinism,
      cross-stage compatibility, and negative release-gate cases.
- [ ] The full acceptance design completes without proxy footprints, unrouted
      nets, unwaived required DRC findings, or incomplete required coverage.
- [ ] A version-pinned independent CAM flow accepts the final manufacturing
      package and its evidence is recorded in the release manifest.

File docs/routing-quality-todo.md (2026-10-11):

# Routed-board quality improvements

Requested 2026-10-10 after inspection of CopperAssetTracker. Generic semantics,
placement/routing algorithms and regression fixtures belong in CopperScript;
reusable part/circuit metadata and macro assets belong in CopperLib. The tracker
owns only its composition, placement choices and validation artifacts.

- [x] Diagnose and enable compatible same-net host/macro ground-zone overlap;
  preserve macro tracks, switching-node exclusions and prescribed RF returns.
  Verify actual native filled copper, not just touching outlines or net names.
- [x] Add reusable decoupling intent with an explicit protected pin/pad association.
  Prefer nearby, same-side pad-to-pad placement and direct surface routing before
  package fanout or plane stitching. Do not guess RF/load/bulk capacitors from a
  reference designator or ban ground-return vias needed to reach a plane.
- [x] Avoid gratuitous same-layer same-net X crossings in package escapes while
  permitting shared endpoints, T junctions and deliberate common trunks. Apply
  the same quality rule to greedy reservations and joint escape assignment.
- [x] Prefer straight outward package exits when legal; retain diagonal/two-leg
  fallback for obstructed escapes, rotated packages and dense-pin access.
- [x] Add regression coverage for ground-zone compatibility and keepouts,
  decoupling placement/routing, adjacent common-net escapes and fallback paths.
- [x] Validate changes on a new tracker candidate; retain prior fabrication files
  and qualification reports as historical artifacts, never overwrite evidence.

Completion and remaining limitations must be recorded below. Geometric routing
quality is not RF/power qualification or production authorization.

## First implementation and tracker evidence

The host-zone overlap gate now scopes blocking keepouts to the owner's protected
region: a remote RF exclusion intersecting a whole-board host pour must not block
an otherwise compatible regulator overlap. Explicit overlap permission is still
required; foreign nets, local exclusions and immutable owner copper remain guarded.
The tracker replaces the four segmented top zones (which left a central hole)
with one same-net-overlap-enabled top GND pour.

Separate `build/routing-quality-20261010/ground-merged.kicad_pcb` passes native
KiCad 10.0.6 refill: zero violations and zero unconnected items. Comparing actual
filled polygons gives zero gap and 58.638 mm of shared boundary for EACH regulator
against the host zone. No positive area overlap is necessary: they abut as
continuous copper. Separate zone objects/settings and owner asset bytes survive.
Previously exported production packages are unchanged.

`role = decoupling; decouples = "U.VDD";` on a capacitor lowers to typed physical
pad/net intent and follows module hierarchy. Placement prefers the same side and
nearby actual feed land, without a guessed universal electrical distance limit.
Ordinary local surface paths are reserved before package exits/plane access;
ground vias remain permitted. Explicit RF/critical routing and macros retain
ownership. The existing `max_distance` and fixed-placement rules are not weakened.

The tracker annotates 14 capacitor/pin associations, not RF/crystal load caps or
the modem bulk reservoir. A read-only probe against the EXISTING routing found
eight associations with blocked direct candidates: C_CC, C_ACCEL, C_LEVEL_A/B,
C_STATUS_A/B, C_DEC4 and C_NRF_VDD3. Its ten proposed surface segments were NOT
committed. Existing fixed placements/obstacles need a fresh routing iteration.
C_DEC3 keeps its explicit critical-router policy.

Greedy and joint package escape selection use the same exact interior-crossing
predicate. Collinear trunks, shared endpoints, T junctions and crossings on
different layers remain allowed. Straight outward rays are tried before diagonal
fallback; a package rotated 45 degrees keeps its diagonal outward normal.
This does not rewrite old copper or prohibit all crossing shapes in area routing.

Verified routing/compiler suite: 210 passed, 2 optional tests skipped; tracker:
27 passed. Retained ground-only native PCB SHA-256:
`f9f4533bc6e1137bb92ed330b2bf49c743d0389f44e42d99ff72cea5fbc7f3a4`;
its clean native DRC JSON SHA-256:
`15dfc2e08a01f3e3a8f73ae2b60873fbdb30406f999d91c6269e9de7cdbe0848`.
No claim is made that the broader full suite or RF/power qualification passes.

- [x] Revisit the eight blocked tracker bypasses using real pad geometry; remove
  obsolete project-fixed poses only where replacement placement is verified.
- [x] Produce and inspect a fresh complete tracker route with the new defaults;
  compare local path lengths, via counts and common-pad escape quality.
- [x] Rebuild candidate manufacturing/qualification evidence after that reroute.
  Earlier qualification reports are historical after source/algorithm changes.
- [x] Add bounded obstacle-aware local bypass search and placement access ranking.
  Preserve verified existing surface chains and earlier bypass reservations.
- [ ] Extend placement feedback to joint repair of mutually blocked decouplers;
  the current bounded greedy ranking reports unresolved cases rather than
  relaxing fixed placement, copper ownership or electrical constraints.
- [ ] Extend same-net crossing preferences beyond package escape assignment to
  ordinary area-route topology, without banning legitimate intentional junctions.

## Pad-access follow-up

On the unrouted tracker geometry, four of the eight original failures were old
copper obstacles. The remaining four had legal straight exits but the simple
elbow candidates turned into adjacent lands too early. The generic router now
tries land-sized straight lead-ins and bounded exact-clearance octilinear A*,
attaches off-grid terminals exactly, rechecks compressed route pieces, honors
breakout widths and reuses verified multi-leg surface chains. No vias or
movable-obstacle exemptions are introduced by the local bypass search.

Placement ranks the outward pin neighborhood and actual surface access, not
just Euclidean distance. Earlier fixed/movable bypasses reserve their corridors;
a candidate's ground land cannot sever one of those earlier paths. The search
is bounded to 64 locally legal copper-access trials per movable capacitor.

The tracker's translator was moved from (20.5,39) to (20.5,42) mm to free room
below the modem. Four translator bypass fixed poses were removed. A separate
`build/decoupling-review-20261010/review.json` records legal placement and 13/13
ordinary associations connected by verified F.Cu chains, zero local-path vias,
27 created surface segments and no pending associations. Their paths measure
1.640–3.321 mm; these are measurements, not electrical qualification limits.
DEC3 retains its specialized policy. Independent native refill of this LOCAL
review has no clearance errors, one expected dangling immutable MODEM_EN port
warning and 106 opens elsewhere on the intentionally unrouted board.
Reading the saved native PCB back through the exact current-source pad/pose
guard confirms all 26 target/feed terminals, no pending links and zero newly
proposed tracks: the thirteen surface chains survive native export and refill.

Current regression coverage: 214 passed / 2 optional skips in the routing and
compiler suite, 65 surface/fanout/plane checks passed, 88 interface/qualification
checks passed; tracker 28 passed. Straight common-net launches legitimately share
one verified via in the adjacent-pad fixture. A separate bounded-radius fixture
retains two drills and checks their actual hole spacing; neither fixture permits
crossed launch paths or unresolved pads.

A fresh all-source reroute passed ordinary exits and the RF/clock groups, but
the modem USB differential pair failed the first bounded package-access search.
Ordinary area routing correctly remained gated. Full routing and new fabrication
qualification are still unchecked; previous production packages are untouched.

A second preflight using the legally reposed review seed (NO historical ordinary
copper) passes all 82 ordinary exits, every critical group including both USB
pairs, and all bypass reservations. This isolates the earlier USB failure to the
new placement candidate/search, not an impossible source connection. The
controlled full reroute is preserved separately with its area/critical/native
reports; it must still pass complete connectivity and final-native checks.
The CLI now creates a fresh report parent directory before writing, with a
nested-output regression: a long routing attempt must not lose its report simply
because its requested output directory did not already exist.

## Failed-net reservations and final review checkpoint

The pose-preserving full attempt connected all critical groups and 58 ordinary
nets; GNSS_TIMEPULSE and V5 needed bounded repairs. GND/V3V3 were deferred fill
nets, not ordinary search failures. Native refill initially showed eight opens.

The general cleanup stage discarded V5's owned escapes when its area search
failed. Later plane stitching then occupied the charger's input-pad exit. A
controlled comparison proves all five dense V5 exits legal BEFORE stitching,
but the charger pin 13 blocked afterwards. CopperScript now retains verified
escapes for failed ordinary nets, as it already did for failed subset repairs.
Successful nets still release unused tails/vias; a preserved exit does not
change partial status or constitute a connected route. Two-leg, mixed-net and
regional-pour regressions cover this policy, without changing width/clearance.

The tracker repair workflow rebuilt these escapes at the saved current-source
area checkpoint, routed V5/GNSS_TIMEPULSE, then stitched planes. The debug-header
contact needed an 8 mm computational search radius rather than 3 mm; no electrical
limit, footprint, stackup or via-in-pad permission was changed. Conservative
native-warning cleanup uses the existing generic stub/unused-escape algorithms,
exact ordinary copper extents and actual connectivity checks. Macro/critical
copper and required via arrays remain protected; the inputs remain recoverable.

`build/fabrication-routing-quality-20261010/board.kicad_pcb` is a new six-layer
tracker review export. Native refill/DRC: zero violations, zero opens. Exact-source
readback confirms all 13 ordinary bypass chains (26 terminals), no proposed repair
tracks and zero local-path vias. Both regulator ground fills meet the host fill
with zero gap and 58.638 mm shared boundary each. DEC3 remains specialized.

This does NOT resolve every visually crossed junction. The exported PCB contains
11 strict same-net X intersections: two immutable macro GND intersections, four
V3V3 stitching/area intersections, two V1V8_MODEM and one each GNSS_TX, MCU_SWDCLK,
NRF_RESET. The nine ordinary intersections remain the next area-topology review
task; do not claim the package-escape preference fixes all copper junctions.

Post-reservation-change regression runs: 274 passed, 3 optional skips across
three focused suites (101/78/98 collected); tracker 34 passed plus 28 subtests.
Broader full-suite success is not claimed. Fresh CAM: 10 pass/3 incomplete;
RF/power: 7 pass/36 incomplete; checkpoint: 19 pass/3 incomplete. Independent
vector CAM, reviewed stackup/operating inputs, RF/power evidence and all 83
assembly approvals remain outstanding. New review archives have
`qualified_release=false`; older fabrication packages are unchanged.

### Local plane-access repair follow-up

Local surface searches now emit and reuse the same region-bounded neckdown
pieces as detailed routing. Both cheap paths and the via-search fallback check
the actual widths; compressed maze paths are rechecked. An existing narrow
trunk outside its declared region cannot silently count as a valid wider path.
The default plane-contact fixture explicitly declares its intended 200 um
profile instead of relying on the former unchecked exact-segment shortcut.

`ripup_mutable_nets` supports a guarded ordinary-net repair transaction. The
caller supplies exact mutable-track/via multisets; unknown, critical, plane,
macro-owned or required via-array copper cannot be evicted. The result is an
incomplete intermediate, not connectivity evidence. A caller must reroute the
evicted nets and run independent native refill/DRC on the saved candidate.

The combined tracker revision exposed a separate package-ordering problem:
its default-width accelerometer supply escape was boxed in by neighboring
I2C clock copper. Reserving its plane contact first and then rerouting that
ordinary clock uses the shared algorithms; no pin, clearance or via-in-pad
permission is changed. Plane outlines and prospective contacts still cannot
prove the actual filled rail joins, especially where different supplies overlap.

`remove_redundant_ordinary_copper` adds a separate exact-connectivity transaction
for identified overlapping stubs that conservative leaf pruning retains. It
requires exact mutable input multisets, excludes critical/plane copper, retains
macro/array guards and checks every affected net's actual pad connectivity
before and after deletion. Failed proof returns no candidate; no native finding
is waived. Tracker native refill exposed obsolete vias after first-pass track
pruning, then two overlapping GNSS escapes; this transaction removed the latter.
The final 91-part candidate has zero native violations and zero opens, with four
verified via-free modem bypass feeds. Hardware/current/RF qualification remains
incomplete. The final focused compiler routing suite has 106 passing tests.

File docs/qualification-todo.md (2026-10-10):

# CAM, RF and power qualification implementation

Requested 2026-10-10. Generic algorithms and command-line validation belong in
CopperScript; reusable part/circuit requirements belong in CopperLib. Projects
own only their selected stackup, operating scenarios, geometry bindings and
measurement evidence. Never copy compiler algorithms into a board project.

## Implementation checklist

- [x] Add content-bound, fail/incomplete/pass evidence and deterministic reports.
  Bind final native PCB, fabrication artwork, parts, stackup, operating inputs,
  tool identities and results. Changed inputs must invalidate prior evidence.
- [x] Add a final-native manufacturing audit command: checksums, layer inventory,
  drill/netlist parsing, pinned independent parser corpus and artifact agreement.
  Keep parsing/render agreement separate from electrical copper connectivity.
- [ ] Add independent vector copper connectivity and geometric fabrication checks.
  Cover clearance, annular rings, mask/paste and drill alignment. Unsupported
  primitives or absent profile capabilities are incomplete, never silently pass.
  - [x] Adapter-neutral polygon connectivity, contact/barrel annulus coverage,
    planar clearance, rectangular paste area ratio and mask-web algorithms.
  - [ ] Qualified Gerber polarity/drill/curve geometry extraction and complete
    fabrication-profile integration. Algorithms alone do not qualify artwork.
- [x] Add reusable RF/power contracts with source/revision/locator provenance,
  explicit unresolved obligations, and strict validated numerical inputs.
- [x] Add RF checks against actual native filled reference copper, including holes,
  signal-layer adjacency and route envelopes. Keep this separate from exported
  Gerber proof. Require exact fabrication stackup and solver-backed impedance.
- [x] Add conductor resistance/voltage-drop/loss and load-envelope calculations,
  including via barrels, capacitor droop and regulator input demand. Do not label
  resistance estimates as thermal/current-capacity or control-loop qualification.
- [ ] Add contract-driven component ratings, capacitance derating, inductor,
  switching-loop/feedback/thermal-layout checks and simulator evidence adapters.
  - [x] Strict mandatory design/simulation/bench contracts, numerical range/width/
    length/distance screens, sourced thermal estimate and byte-bound reviewed
    external solver/report adapters; no report-selected commands are executed.
  - [ ] Source/model-specific automated derating and switching-loop/feedback/
    thermal geometry extraction. Existing hard-macro ownership remains required;
    unresolved detailed review cannot be replaced by simple origin distances.
- [x] Integrate board-specific bindings and run checks on CopperAssetTracker's
  existing final-native six-layer candidate without rerouting or altering copper.
- [x] Add regression tests: broken/missing/stale evidence, plane gaps/holes,
  wrong reference layers, conductor neckdowns, invalid operating scenarios,
  parser disagreement and malformed manufacturing data.
- [ ] Connect all gates to release authorization; CAM/RF/power alone cannot approve
  a BOM, authorize an order or replace assembly/mechanical/battery review.
  - [x] Current-input `qualification-gate` and tracker ordering-target blockers.
  - [ ] Extend the older strict Physical-IR release API with final-native,
    six-layer evidence/profile support. The native file exporter remains
    unqualified; no production authorization or order endpoint was added.

## Verified initial implementation

Commands: `audit-cam`, `assess-engineering`, `qualification-gate`. Generic code
is in this repository; five reusable contracts are in CopperLib. Tracker inputs
and reports are in CopperAssetTracker. No copper/placement was changed.

The actual candidate passes all package hashes, 13 Gerber layer metadata, 295
drill hits, 552 physical contacts, 295 vias and net partition reconciliation.
Cellular/GNSS track envelopes pass filled In1 ground coverage with zero extra
margin (not impedance/return inductance qualification). CAM and RF/power overall
remain incomplete. External evidence is never inferred or falsely marked passed.

Focused compiler/native tests: 141 passed (no skips); reusable library/component
tests: 19 passed; tracker tests: 27 passed. These passes do not claim the full
suite passed. Rechecking the broader run's example failures produced six failures
and two setup errors: CM4/nRF52 example locks expect a different installed KiCad
footprint inventory, and full-vertical hard-macro asset bytes differ from their
recorded identities. Do not bypass the hash checks, rewrite those identities or
replace installed assets merely to turn the tests green.

- [ ] Reconcile the broader example asset/lock mismatches against their intended
  upstream content, preserving local changes; rerun the full suite afterward.

Latest tracker reports are `build/cam-audit-current.json`,
`build/engineering-audit-current.json` and
`build/qualification-gate-current.json`. All artifact/algorithm bindings pass;
overall status remains incomplete. Earlier dated reports are retained history,
not current evidence after native-probe/algorithm changes.

## External qualification checklist (cannot be invented by software)

- [ ] Select and obtain the exact fabricator stackup/capabilities; retain revision
  and reviewed copper thickness, dielectric thickness/Dk and finished plating.
- [ ] Provision and pin a second independently maintained CAM parser; qualify
  positive/negative, polarity, arcs, aperture macros, regions and slot corpus.
- [ ] Review exact SIM7670G-LNGV hardware-guide equivalence and antenna matching.
- [ ] Obtain effective MLCC capacitance and inductance/current/temperature data.
- [ ] Establish battery, USB, peak/RMS load and ambient-temperature envelopes.
- [ ] Run applicable impedance/SPICE/thermal solvers with pinned models/settings.
- [ ] Measure prototype antenna tuning/OTA behavior in the intended enclosure.
- [ ] Measure modem load bursts, low-battery operation, charging/NTC behavior and
  temperatures; review actual pack protection, harness ratings and polarity.
- [ ] Review every BOM/CPL selection and supplier preview; recheck stock at order.

Implementation progress, tested scope and remaining boundaries must be recorded
here. An unchecked item is not satisfied by native ERC/DRC or a generated report.

## Selected-supplier construction follow-up

- [x] Resolve and bind reusable supplier profiles from consumer engineering plans;
  reject consumer overrides and recheck profile bytes at the checkpoint.
- [x] Distinguish published construction from nominal finished thickness using
  sourced tolerance; do not stretch dielectric spacings or guess loss/minimum
  plating from published averages.
- [x] Inventory actual RF/USB widths and reference coverage. Isolated outer
  microstrip screening is auxiliary, never a replacement for external impedance
  evidence. No estimate is assigned to interior routes or unsupported references.
- [ ] Add qualified coupled/embedded/stripline/discontinuity solver integration.
- [x] Add reusable interface qualification contracts and external USB design,
  simulation and bench gates. Auxiliary pair geometry is not USB qualification.
- [x] Extract exact pad-centre/straight-track paths without shortest-path guesses
  on cyclic graphs; preserve branches, unused barrels and bounded return-via
  distances separately. Native contact layers/via type are retained read-only.
  Unsupported copper-edge/pad-area paths remain incomplete.
  Whole-channel USB contract/stage/coverage, path geometry, existing pair/stackup/
  RF-power/checkpoint/CAM and editor-overlay focused tests: 127 passed (2026-10-10).
- [x] Extract actual parallel pair gaps, unique covered length, member copper
  inventory/vias and adjacent plane nets/separations without assuming source
  gap, electrical delay or a ground reference. Auxiliary geometry only;
  focused pair/stackup/engineering/gate/CAM tests: 71 passed (2026-10-10).

CopperLib's JLC06161H-3313 companion profile is reusable. Tracker's selected-
stackup reports and BOM approval remain board-local; old artifacts are untouched.
Focused compiler checks and tracker regression counts are in the board's
`docs/stackup-selection.md`. Production qualification remains incomplete.

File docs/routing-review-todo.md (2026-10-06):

# Routing review implementation and verification

Review baseline: `ddfa9b2`, full-vertical six-layer board, 100 x 80 mm.
Independent KiCad baseline: 74 unconnected items, 68 dangling tracks,
eight footprint-library findings. Earlier substantially connected board:
one GND unconnected item and eight library findings.

This list tracks every finding from the 2026-10-01 routing review.
Completion means tested implementation, not automatic manufacturing signoff.

## Correctness first

- [x] R13: Correct the Coilcraft USB choke internal winding mapping from a visual
  official-source audit (1-2 and 4-3, dotted inputs 1/4). Add CopperLib winding
  regressions and CopperScript physical-net tests, refresh the dependency lock,
  and explicitly invalidate historical USB electrical acceptance. Copper DRC
  cannot detect a part model's incorrect internal conduction. See
  [pass 11](routing-review-pass11.md).
- [x] R13b: Rerun critical and then ordinary routing using that corrected library;
  obtain fresh independent KiCad evidence. Old USB placements/copper are not a
  valid baseline for electrical acceptance or route-quality optimization.
  - [x] Fresh critical preflight: all eight critical nets connected, no placement
    repair trial, zero vias; independent KiCad confirms zero critical opens and
    no hard copper/dangling findings. Eight library findings remain.
  - [x] Full ordinary rerun and independent filled-zone/layer review in
    [pass 13](routing-review-pass13.md): unchanged critical copper/51 poses,
    zero GND/critical opens and no hard copper findings. Three ordinary nets
    remain open (34 KiCad items); this completes the rerun, not routing closure.
- [x] R14 (pass-11 shape finding): Replace oblique exact single-ended RF
  package/grid access links with clearance-checked straight/45-degree access.
  Preserve original terminal contact, widths, layers, earlier reservations and
  full native/profile acceptance; never silently snap endpoints off pads.
  Pass 12 checks identical selection/emission paths and removes all four real
  oblique RF access segments at the unchanged placement. Independent KiCad
  retains zero critical opens and no hard copper/dangling findings.
- [x] R15 (pass-11 shape finding): Remove small paired taper/spine collinear
  reversals in the joint construction/refinement owner, rechecking both lanes
  atomically. The corrected modem DP route backtracks about 0.034 mm; independent
  pruning of one member or assuming fewer segments means fewer bends is unsafe.
  Pass 12 rejects consumed/reversed offset edges and adds bounded two-leg
  terminal collars. Fresh search closes both USB pairs at the unchanged
  placement with zero reversals, original profiles and unchanged maze budgets.
  Modem paths grow slightly; this is not completion of R5 route optimization.
  See [the matched shape review](routing-review-pass12.md).

- [x] R1: Scope fanout cleanup to attempted nets; preserve unrelated copper,
  empty subsets, failed-subset rollback, and pre-existing/shared vias.
- [x] R2: Check complete candidate connectivity during local/placement repair,
  reject new ordinary-net opens, preserve unaffected geometry, and recompute
  committed metrics instead of trusting stale per-net flags.

## Route geometry and costs

- [x] R3: Preserve 45-degree reachability when pad coordinates split search
  axes; retain exact clearance checks and test split-axis invariance.
- [x] R3b (follow-up review): Replace index-space supercover sampling with
  physical-space obstacle/outline sampling on nonuniform rays. An off-ray
  blocked node can still conservatively suppress a restored diagonal edge.
- [x] R4: Normalize global/detailed layer and wrong-way costs by physical
  length; test split-edge and routing-pitch invariance.
- [ ] R5: Bounded improvement of feasible routes: compare wider/projected
  guides for expensive incumbents, without sacrificing connectivity or DRC.
  - [x] Compare bounded local surface-tree alternatives for small single-ended
    critical nets against coarse guides; include all physical lands and preserve
    incumbent copper on failed native/profile validation. General-net guide
    widening and larger-tree optimization remain open.
- [ ] R6a: Add clearance-aware local demand and failure pressure so spare
  signal layers can relieve congested channels; keep GND plane reserved and
  retain explicit layer/reference restrictions.
  Pass-13 cases: MCU_NRF_TX cannot reach U_NRF.10; MODEM_EN exhausts search
  toward U_MCU.64; V3V3 exhausts 200,000 states toward R_RESET_MCU.1. Global
  overflow is zero while these fine-access/tree failures remain. Reproduce
  failures with existing critical/ground copper before forcing layer balance.
  - [x] Analyze immutable legal fanout candidate domains and prioritize low-slack
    pins before easy neighbors, with exact incremental/final clearance and
    per-pin diagnostics. [Pass 15](routing-review-pass15.md) improves 68 to 69
    escapes on the same critical/GND-only checkpoint. MCU.62/.64 have zero
    radial candidates even before ordinary fanout; R6a remains open.
- [ ] R6b: Localize neutral-cost fallback and report effective policy rather
  than silently replacing the whole board with an unreported neutral rerun.
  - [x] Report requested/effective detailed costs and attempted/selected fallback
    per net, with scored scope and pre-closure failure/overflow comparisons.
    Preserve mixed policies through subset repair and keep telemetry out of
    geometry/route fingerprints. See [policy reporting](routing-search-policy.md).
    The full pass-13 run loaded the previous source; its policy choice remains
    unavailable. Whole-scope fallback localization is still open.
- [x] R16 (layer-review code finding): Normalize guide-deviation run cost by
  physical length and separate actual guide-boundary events. The current fixed
  50-unit charge per outside edge varies with pad-inserted coordinate splits.
  Add split/pitch-invariance regressions and matched layer/route comparisons,
  preserving explicit layer rules, reference-plane reservation and acceptance.
  Implemented analytic uncovered-length union and separate via guide-exit
  events. [Pass 14](routing-review-pass14.md) tests split/pitch/search costs and
  replays all three failed nets with identical saved copper/global guides.
  No complete net closes; KiCad retains 34 open items/eight library findings.
  Local package-escape blockage, not guide-cost normalization alone, is now
  the next reproduced R6a case. This does not close R5/R6a/R6b/R7/R9.
- [ ] R17 (pass-15 access finding): Add bounded two-leg straight/45-degree
  package exits and explicitly verified multi-segment fanout anchors. Radial
  allocation alone has zero legal candidates for MCU.62/.64 before ordinary
  routing. Preserve exact pad/via contacts, complete physical span, ground and
  critical reservations, no-via-in-pad rules and transactional ownership/cleanup.
  Compare candidates against immutable geometry first; if no legal exit exists,
  use owned-escape/placement feedback rather than weakening clearance. Then
  rerun the entire pipeline and repeat independent KiCad/layer review.
  - [x] Implement bounded off-ray two-leg alternatives, shared exact access
    checking, verified existing multi-segment anchors and explicit track/via
    ownership through cleanup and pipeline/repair callers. Installed-KiCad
    regression accepts the routed two-leg fixture. [Pass 16](routing-review-pass16.md)
    improves matched partial fanout from 69 to 72 exits without changing prior
    critical/GND copper or any pose. MCU.62/.64 now have ten/three legal initial
    alternatives, but selected neighboring escapes consume them.
  - [x] Add local candidate conflicts and bounded compatible assignment, including
    expansion of competing pins with already legal radial choices. Exact replay
    identifies MCU_NRF_RX / MCU_MODEM_TX blocking the MCU UART/enable exits;
    increasing the area-search budget is not the next experiment.
    [Pass 17](routing-review-pass17.md) implements exact lazy conflicts, affected
    domain expansion, MRV/forward-checking and bounded conflict-driven group
    growth with incumbent rollback. Matched escapes improve 72 to 74 without
    losing any prior identity. MCU.62/.64 still lack a compatible generated
    pattern; endpoint coverage and fully locked local-search controls do not
    close them. This completes the assignment increment, not full R6a/R17.
  - [ ] Generate constrained multi-bend alternatives for both sides of those
    remaining conflicts, with exact multi-leg anchor/ownership checks; compare
    a complete compatible group before committing it. If none exists, use
    bounded legal whole-unit placement/critical-reservation feedback.
  - [ ] After those exits survive allocation, rerun complete ordinary routing,
    independent filled-zone checks and every-layer geometry/congestion review.
  - [x] Add [escape-first preflight](package-access-first.md), reserving ordinary
    local exits before critical long routes, explicit area-routing gate and
    bounded identity-preserving whole-unit placement feedback. This first
    increment does not co-allocate critical or all power/GND domains.
  - [ ] Co-allocate critical/ordinary/plane package access, verify onward ports,
    derive directional placement margins, then perform the full rerun. See the
    implementation sequence in package-access-first; a legal via is not closure.
- [ ] R18 (escape-terminal review of the clean full-vertical rerun): Package
  escapes are reserved before routing and then *replace* the pad as the
  detailed router's terminal. On the clean rerun all 104 boundary ports are
  In2.Cu (the rank-0 layer). The detailed router must start or end at that
  single port: `_route_net` offers no pad access candidates once a
  `RoutingAccess` exists. Observed consequences:
  - Escape via, port stub and router via chains within 0.25-2 mm. V1V8_MODEM
    is 16 mm of F.Cu with four vias, where a direct surface route has none.
    SIM_RST, SIM_IO, GNSS_*, CAN_L/TX/RX show the same chain.
  - Hairpins, because escape and port direction ignore the destination.
    GNSS_TX escapes south, then runs 4 mm north past its own pad.
  - Loops: CAN_H climbs from U_CAN.7's port and crosses its own pad on F.Cu,
    because touching the pad does not count as connected.
  - Every pin of small fine-pitch parts is escaped
    (`escape_small_dense_packages`, 1.5 mm neighbour distance), e.g. a
    VSSOP-8.
  - CS-090 cleanup never removes these escapes: the port stub always counts
    as used.

  Most remaining In2 sharp-turn candidates sit on these ports
  ([layer-balance review](routing-layer-balance-review.md)). They also make
  opt-in layer assignment fragile. Planned work, each exact, transactional
  and ownership-safe:
  - [x] Offer the pad's own surface access as an alternative terminal to its
    reserved escape, and remove unused escape and witness copper after
    routing (CS-163, `escape_terminals`; board router default, opt out with
    `--no-escape-terminals`). The escape stays reserved while routing; after
    it, land/via/witness copper the net does not need is released in tiers,
    each a settled, connectivity-checked transaction.
  - [ ] Choose port edge and layer from the net's guide or destination; allow
    surface and other signal-layer ports. Other-layer and surface exits now
    come from the launch via (a terminal on every permitted layer it spans)
    and the pad itself, so ports stay In2.Cu but 100 of 104 witnesses are
    released. Destination-facing ports exist as opt-in
    `--package-destination-ports`; on nrf52 they added 18.5 mm and three
    sharp turns, so they are not the default. Guide-layer ports remain open.
  - [x] Treat the pad and its connected launch copper as part of the terminal
    set, so a route touching it terminates; remove copper cycles in cleanup.
    Land/witness centre-line nodes and launch-via layers are terminals; a
    connected pad's other terminals are virtual tree roots; a walk through
    the tree starts from its last tree node; released-copper cleanup prunes
    dead ends beyond land/via centres and cuts redundant loop branches.
  - [ ] Collapse escape-via, port-stub and router-via chains when a direct
    replacement validates. Not implemented: after the items above only one
    escape-via/router-via pair within 2 mm remains on full-vertical (35
    before).
  - [x] Escape only pins whose direct access is actually constrained, done as
    the allowed fallback form: every escape is reserved as before but
    dropped if unused. Selection is unchanged on evidence: full-vertical
    still uses 67 of 104 escapes (63 via only, 4 with the port); nrf52
    without small-package escapes closed but kept 3 more vias, 14 mm more
    track and 2 more sharp turns.

  Pass record (unprofiled `make … route`, KiCad 10.0.6 refill + all-severity
  DRC; "before" is the smoothing base; lengths mm / sharp-turn candidates):

  | Board | Run | F.Cu | In2.Cu | In3.Cu | In4.Cu | B.Cu | Total | Vias (router) | Time | KiCad |
  | --- | --- | ---: | ---: | ---: | ---: | ---: | ---: | ---: | ---: | --- |
  | nrf52 | before | 146.1 / 5 | 216.2 / 18 | 11.1 / 0 | 0 | 0 | 373.3 / 23 | 52 (18) | 90.6 s | 0 / 0 |
  | nrf52 | R18 | 171.4 / 6 | 164.6 / 0 | 7.9 / 0 | 0 | 6.3 / 0 | 350.1 / 6 | 34 (5) | 61.2 s | 0 / 0 |
  | full-vertical | before | 874.0 / 22 | 1,325.0 / 76 | 51.6 / 0 | 44.0 / 0 | 98.6 / 1 | 2,393.2 / 99 | 280 (115) | 886.6 s | 0 / 0 |
  | full-vertical | R18 | 966.6 / 33 | 1,132.0 / 6 | 49.1 / 0 | 36.8 / 0 | 95.0 / 1 | 2,279.4 / 40 | 183 (55) | 338 s | 0 / 0 |

  Both boards close with no open ordinary net. On full-vertical 17 F.Cu
  candidates are unchanged GND stitch copper; ordinary candidates fall from
  82 to 23, but F.Cu ordinary ones rise from 5 to 16 (eight on V3V3, half
  with a leg under 0.5 mm: surface lead-in jogs, R7). Of 104 escapes, 37 are
  released completely, 63 keep only land and via, 4 keep their port path.
  Same-net loops fall from 2 (CAN_H, USER_BUTTON) to 0 and escape-via/router
  via chains within 2 mm from 35 to 1. V1V8_MODEM is 12.9 mm with no via
  (19.0 mm, 4 vias before), GNSS_TX/RX 2 vias each (8), CAN_H 31.2 mm with no
  via (48.0 mm, 2). Detailed attempts fall from 201 to 123. Run dirs (this
  worktree): `build/r18-src-v5/build/nrf52-v5`, `…/fv-r18`; the "before"
  nrf52 rerun is `build/r18-src-base/build/nrf52-base`, and
  `--no-escape-terminals` reproduces it exactly (`…/nrf52-v5-off`).

- [ ] R19 (power-rail access finding): 0.3–0.4 mm ordinary rails exhausted
  their search budget at 0.4–0.5 mm-pitch IC pins, because the detailed router
  checked and emitted the full `width` up to the pad, and a full-width track
  cannot land between neighbouring pins.
  - [x] Neck down ordinary nets with breakout properties (CS-164): search
    edges, shortcuts, pad access, escape verification and global pin access
    are checked and emitted as region pieces (`breakout_width` inside,
    `width` outside); merging, chamfers, smoothing, stub pruning and escape
    release keep a necked piece inside its region. Synthetic coverage in
    `tests/test_ordinary_neck_down.py`; nrf52 (no breakout properties)
    routes byte-identically apart from KiCad UUIDs.
  - [ ] Declare `breakout_width`/`breakout_length` on the rails of a board
    that showed the failure, reroute it and review the necked copper,
    search budgets and KiCad DRC. Global demand and the package-escape maze
    still use the full width.

- [ ] R7: Branch-safe straight/45-degree cleanup for multi-terminal trees,
  including orthogonal-first/budget-fallback routes; protect pads, junctions,
  vias, and exact clearance. Improve topology without breaking existing trees.
  Pass 13 retains 57 degree-two 90-degree turns, eight acute 135-degree turns
  and a 1.5 mm GNSS_RX fanout/maze overlap. Preserve real pad/via contacts and
  owned-copper scope when testing seam cleanup; MCU_RESET reports orthogonal
  mode and retains a right-angle staircase on sparse In4.Cu.
- [ ] R8: Exercise critical USB/RF profiles in the full-vertical example;
  reserve critical geometry and protect paired nets in repairs. Do not infer
  controlled impedance or invent electrical limits from names.
  - [x] R8a: Declare explicit profiles; atomically validate critical candidates
    against native geometry/connectivity; protect pair copper through subset
    repairs and duplicate-land closure. Real-footprint preflight connects four
    RF nets with no vias and rejects both unsafe USB pairs. See
    [pass 4](routing-review-pass4.md); this does not complete R8.
  - [x] R8b: Joint same-layer paired package-access search. Enumerate legal
    paired exits, preserve terminal order, search a heading-aware common spine,
    and materialize clearance-checked straight/45-degree corners/tapers.
    Bounded pitch refinement connects both real-footprint USB pairs without
    vias or placement changes. Independent KiCad confirms no critical opens
    or hard copper findings. See [pass 5](routing-review-pass5.md).
    Non-octilinear/multi-terminal pairs remain unsupported by this search,
    not silently approximated. Paired terminal transitions now have a bounded
    owning search; see R8d. Package-placement feedback remains available if
    these finite joint searches fail.
  - [x] R8d: Matched terminal-via collars plus a common-spine route on another
    permitted signal layer. Retain full-span drill/copper and reference-via
    checks, explicit pairing provenance, original budgets and atomic native
    acceptance. USB example profiles allow F.Cu/In2.Cu with two vias/member;
    actual impedance/return-plane qualification remains unfinished. See
    [paired-layer-transitions](paired-layer-transitions.md).
  - [ ] R8c (next): Enforce RF reference-layout/matching clusters and antenna keepouts;
    shorten the Nordic and GNSS paths. Connected long top-layer feeds are not
    evidence of RF performance, matching-ground topology or return continuity.
    - [x] Audit electrical terminals/topology first: replace the generic antenna
      with the source-backed Johanson part, isolate its NC anchor, and move the
      Nordic 0.8 pF shunt to the chip side of the 3.9 nH series inductor.
      Evidence and ERC regressions are in CopperLib/CopperScript.
    - [x] Implement identity-bound rigid physical clusters: anchor-pad local poses,
      explicitly allowed rotations including 45 degrees, whole-unit legalization,
      refinement and feedback, transformed layer-scoped keepouts and digest-bound
      DRC/export. Synthetic regressions verify the mechanism; this does not supply
      a Nordic/Johanson template or qualify RF performance. See
      [rigid-cluster API](rigid-placement-clusters.md).
    - [x] Extract/pin Nordic QFAA LDO U1/C3/L1 center/rotation data and implement
      explicit CLI scene binding with footprint/pad-net identity checks. Retain
      source physical C3 numbering and legal non-overlapping internal courtyards.
      The example scene is a provisional KiCad-footprint adaptation, not the
      vendor matching-ground circuit or complete support/reference layout.
    - [ ] Complete the Nordic support circuit and extract a pin/pad-bound rigid
      matching/reference-ground cluster from the vendor layout, not a guessed
      distance threshold. Preserve its legal translation/rotation transforms.
    - [ ] Implement antenna corner placement and qualified local layer-aware
      copper/ground keepouts without deleting its isolated mechanical land.
    - [ ] Optimize receiver/connector RF clusters and noise-source separation;
      validate the new placement and reroute critical groups transactionally.
      See [RF audit](rf-layout-audit.md). R8c remains open.
    - [x] Compare legal local matching-tree paths against accepted coarse guides:
      pass 7 preserves the macro but still emits a 17.19 mm raw matching tree.
      Protect terminals/branches, bound the search and retain atomic native/profile
      acceptance; do not confuse close placement with short committed copper.
      This is the critical-cluster application of R5, not a second cleanup mechanism.
      [Pass 8](routing-review-pass8.md) reduces the raw tree to 2.31 mm without
      placement changes or hard independent copper findings. RF qualification
      and the wider R5 scope remain open.
    - [x] Reevaluate paired package access/placement for the pass-7 modem USB
      failure (24 searches, 720,000 states, zero candidates), without increasing
      budgets blindly, routing members independently or discarding reservations.
      - [x] Implement opt-in bounded legal whole-unit critical placement feedback;
        rebuild all critical reservations and require strictly fewer failed net
        identities with no fresh hard native DRC. Fixed/rigid/45-degree and
        rollback/integration tests are in place. See
        [controller contract](critical-placement-feedback.md). [Pass 9](routing-review-pass9.md)
        accepts an algorithmic FL_USB rotation, rebuilding all groups; KiCad finds
        zero critical opens and no hard copper errors. Ordinary routing remains open.
      - [ ] Improve the connected paired geometry without weakening profile or
        atomic connectivity checks: pass 9's modem pair uses 214 segments and
        60.37/62.88 mm paths, while the MCU pair becomes longer. This extends R5
        to paired quality comparison; a connected detour is not a minimum-length
        or electrically qualified route.
        - [x] Add bounded shared-spine compaction and straight/45-degree shortcut
          proposals, preserving both package escapes and full profile/native
          acceptance. Synthetic detours shorten; the matched real placement
          only loses redundant collinear segments (modem 214 to 38, MCU 36 to 26),
          not meaningful wirelength. See [paired refinement](paired-route-refinement.md).
        - [ ] Compare alternative joint port/placement topologies on the corrected
          library, retaining the accepted pair on failure. Historical 60.37/62.88 mm
          paths used the incorrect choke model and are superseded, not current
          optimization targets. Pass 12/13 retains 22.98/23.61 mm modem and
          28.30/27.04 mm MCU paths; bounded quality comparison remains R5 work.
  - [ ] R8d: After critical preflight passes, perform the complete rerun and
    independent KiCad layer review. Bind actual impedance/return-path evidence
    to the selected physical stackup before any critical-net signoff claim.
  - [x] Complete corrected-input rerun and all-six-layer review (pass 13).
    Three ordinary opens and production/return-path qualification remain.
- [ ] R9 (follow-up review): Record phase timings/checkpoints for long full
  reruns and cache equivalent physical-span via legality queries within one
  immutable search. A 15 s/734-sample profile during zone-escape feedback
  attributes 27.4% of samples to via checks, 13.1% to track checks, and 12.8%
  to neighbor generation (inclusive categories; not whole-run timing).
  Search-local physical-span via caching is implemented in pass 2; operational
  phase timing/checkpoints and default full-run profiles are now implemented.
  Per-net/search telemetry and resumable geometry remain outstanding.
  - [x] Add exact doubled-integer rectangle edge checks for track capsules and
    via disks, caching only immutable outline classification. Nonrectangular
    outlines retain the original exact predicate. Randomized/tangency regressions
    preserve clearance; the measured microbenchmark is not full-router timing.
  - [x] Add per-critical-group started/finished progress/timing checkpoints;
    interrupted preflights retain the running group without claiming completion.
    Notifications do not participate in route geometry or fingerprints.
  - [x] Stream optional elapsed phase/group/trial events in the normal CLI and
    persist them in the complete workflow's `routing.log`. Include ordinary-area
    start/finish or access-blocked events, ground feedback decisions, native DRC,
    independent KiCad checks and export. Regressions compare observed/unobserved
    geometry, fingerprints, reports, project bytes and exit status.
    See [routing progress](routing-progress.md). This does not make stage geometry
    resumable; per-ordinary-net and within-pair search telemetry remain open.
  - [x] Enable function profiling by default in the complete workflow, retain raw
    statistics and top self/cumulative summaries, derive phase/trial elapsed spans,
    record provenance and preserve failure exit codes. Provide `--profile none`
    for fair wall-time baselines. See [performance assessment](routing-performance.md)
    for measured evidence and algorithm/process-parallel optimization priorities.
- [x] R10 (rerun finding, correctness priority): Replace endpoint-only native
  connectivity with layer-aware copper-contact connectivity. Detect interior
  T/cross junctions, track/via overlap, and pad-shape contacts; retain physical
  via spans and independently verified zone evidence. Native checking flags
  V3V3, V3V8, MODEM_EN, and PWR/MODEM_FB as open on a board where KiCad finds
  none of those opens. An interior-T regression reproduces the defect. Do not
  waive open-net checking or assume every rejected placement trial was valid.
- [x] R11 (rerun finding): Resolve U_CC.3/.10/.11 GND as a joint package-access
  group, reserve its escapes before ordinary routing, and evaluate bounded
  component/decoupler moves only after R10 makes trial acceptance reliable.
  Keep small-pad via drill/clearance rules and explicit fabrication limits.
  Pass 2 implements automatic whole-package same-zone-net reservations;
  independent KiCad refill confirms zero unconnected items in pass 2, without
  moving components or relaxing fabrication limits.
- [x] R12 (pass-2 review): Evaluate duplicate-land closure consistently before
  feedback scoring and final reporting. USER_BUTTON is checked before final
  SW_USER land stitching; the finished board is connected. Reconcile pending
  shield-land helpers with digest-bound filled-zone evidence without inventing
  virtual contacts or suppressing footprint/manufacturing findings.
  Implemented in pass 3: shared exact land roots, pre-scoring closure, measured
  additions/status, and explicit surface-pending versus verified-zone reporting.
  Fresh saved-board KiCad evidence resolves both shield references without
  changing its copper; 313 tests pass. The matched rerun is recorded below.

## Matched rerun and repeated review

- [x] Run focused regressions and the full available test suite.
- [x] Reroute the same full-vertical board/placement and settings, documenting
  any explicit critical-profile or option changes separately.
- [x] Refill zones and run independent KiCad DRC on disposable artifacts.
- [x] Render all six layers and central hotspots; repeat length, density,
  heading, bend, via, detour, and actual-connectivity measurements.
- [x] Compare against both the damaged latest and earlier connected board;
  never credit copper deletion as wirelength/via optimization.
- [x] Record remaining bottlenecks and exact access contributors for subsequent
  bounded placement moves/45-degree rotations. See R11; preserve functional
  decoupling/RF/power clusters rather than spreading components indiscriminately.
- [x] Commit verified feature changes, leaving user-owned draft files alone.

## Acceptance gates

Unchanged nets retain their copper and connectivity. A repair introduces no
new ordinary-net open or hard DRC regression. GND-zone deferral is separate
from signal connectivity. Independent filled-zone KiCad verification remains
mandatory. All production, return-path, footprint qualification, and CAM
requirements remain separate from route completion.

- [x] Clear remaining filled-zone GND opens (R11). Pass-2 independent KiCad
  reports zero unconnected items. This is connectivity, not production signoff.
- [ ] Qualify footprints and resolve the eight independent library findings;
  none were suppressed or fixed by this routing pass.
- [ ] Complete critical-net, return-path, fabrication and independent CAM
  signoff before claiming this example is production-ready.

## First implementation pass

### Ordinary-track stub regression (2026-10-05)

- [x] Reproduce accepted-path backtracking and overlapping access tails.
- [x] Erase physical-node excursions before copper commitment, and prune owned
  unanchored track leaves without severing terminal/interior/via contacts.
- [x] Preserve input occurrences, hard-macro copper and reusable boundary proofs;
  derive reported ordinary copper counts/lengths from the accepted geometry.
- [x] Verify focused routing/ownership regressions and independent KiCad DRC.
- [ ] Reroute and review full-vertical layers using the new cleanup. The running
  `0919f0b` timing experiment uses the earlier implementation.

The mechanism and conservative limits are documented in
[route-stub-cleanup.md](route-stub-cleanup.md).

R1–R4 are implemented with focused regression tests. Subset cleanup filters
its access mapping, requires explicit via ownership before removing input vias,
and preserves fanout on failed repairs. Local acceptance checks unaffected
copper identity and fresh native connectivity. Merge metrics are measured from
committed geometry, and placement/detailed scoring counts actual ordinary-net
opens. Diagonal successors skip inserted coordinate splits. Shared integer
costs use a 1 mm physical reference, independent of routing pitch; fixed bend
and via events remain separate. The matched rerun below determines actual
board quality; R5–R8 remain open for subsequent implementation passes.

Commit: `8b8c896`. All 277 tests pass in an isolated Python 3.12 test runtime
with pinned `pygerber` installed (459 upstream deprecation warnings). This
includes eight new review regressions. The post-commit focused acceptance/flow
rerun passes 16 tests. Independent full-board results are recorded separately.
The initial Python 3.13 run passed 275 tests but lacked the optional CAM
dependency; the Windows Store Python launcher also cannot supply the readable
executable-byte identity required by the CAM adapter. No CAM check or
executable-identity requirement was weakened to work around that environment.

The repeated review is in [routing-review-pass1.md](routing-review-pass1.md).
Independent KiCad finds three GND unconnected items, zero dangling tracks,
and eight library findings, versus 74/68/eight on the damaged baseline. All
57 ordinary nets are connected under KiCad. The earlier best board still has
fewer ground opens (one). At the end of that pass, R10 was the next correctness
task; R3b and R5–R11 were unfinished.

## Second implementation pass

R10 and R3b are implemented. Native connectivity uses exact rounded-shape
contacts on common physical layers, including annular/pad-edge contacts and
interior junctions; it preserves actual gaps and drill voids and does not infer
filled zones. Static ray checks follow physical coordinates and exact polygon
containment for both diagonal and orthogonal moves. R11's whole-package
same-zone-net reservation is implemented and the example's ground closure is
independently verified. R9's search-local physical-span via cache is
implemented, while normal operational timings/checkpoints remain open.

All 297 tests pass in the isolated Python 3.12 runtime, including 20 new tests
since pass 1 and five optional installed-KiCad differential connectivity cases.
Replaying the previous board's copper clears all four false ordinary-net opens;
only GND remains open under native explicit-copper checking. No DRC check was
waived and no geometry/fabrication limit was relaxed. Implementation commit:
`4839b90`. The [second repeated review](routing-review-pass2.md) records the
matched rerun: zero KiCad unconnected items, zero dangling/short/clearance
findings, eight unchanged footprint-library findings. The accepted joint-package
trial retains every component position and rotation. R5–R9 and R12 remain open;
native zone deferral and library findings still prevent production-ready status.

## Third implementation pass

R12 closes duplicate physical lands before full and subset candidate scoring,
using the native exact-contact graph. Existing multilayer/pad-edge paths are
reused; bounded new bridges respect layer and width rules. Single-logical-pad
nets with separated physical lands now correctly fail native connectivity.
Search failure flags and zone deferrals remain failures; closure updates
connectivity, actual added ordinary copper, routing metadata and fingerprints.

Reports retain raw `surface_pending_pads` and identify `zone_verified_pads`
separately. Only fresh board/export-bound KiCad evidence with zero opens/islands
and no non-library violations resolves pending zone-net references. Eight
library findings remain failures, and no native finding or signoff token is
waived. Final-stage and selected-pipeline bridge counts are separate.

All 313 tests pass (16 additions since pass 2, 459 upstream warnings), including
installed-KiCad verification of a single-logical-pin duplicate-land open and its
closure. A read-only replay of the saved pass-2 board adds zero tracks, recognizes
four already-connected references, and resolves J_POWER.SH/J_SIM.SH through a
fresh independent refill while retaining all eight library findings.
Implementation commit: `c1d5e52`. The [third repeated review](routing-review-pass3.md)
records the completed matched rerun: zero KiCad unconnected items, no hard copper
findings, identical physical track/via/pad/placement geometry to pass 2, and
zero reported signal failures in the accepted feedback trial. Sixteen bridges
are now installed before scoring; final stitching adds none. Eight library
findings and native zone deferral remain signoff failures. R8 is the next
implementation priority; R5–R9 remain open.

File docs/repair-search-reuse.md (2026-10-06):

# Exact repair-search reuse — 2026-10-06

This is a detailed-repair work reduction, not a routing-quality change or
fabrication signoff. Every reused answer is the attempt an identical earlier
search produced; selected copper, reports and fingerprints stay unchanged.

## Question

The [full-vertical review](routing-shared-reference-review.md) recorded 77
displaced-net searches (`evicted_net`) taking 842.491 s of a 1,807.862 s run,
with `V5` alone at 20 attempts and 19 failures. Its open item asked whether
these are duplicate states, and to bound any memoization to exact obstacles,
rules, guides, anchors and search options, never reusing a failure after the
blocking geometry changes (CS-087).

## Method

Each `_search_detailed_net` call now has an exact identity:

- the immutable board object (keepouts, zones, placements, footprints, macros,
  locked fanout/critical copper, net rules and board rules) and any resumed
  branch checkpoint, both **by identity**, held so their ids cannot be reused;
- the clearance index as its board, bin size and **ordered** insertions with
  lock flags (`RoutingClearanceIndex.additions()`); all other index state
  derives from the board;
- by value: the net and its terminals, its rule, global guide/corridor, all
  owned fanout/boundary anchors, congestion usage and history, the repair and
  movable-conflict modes, and every `DetailedRouterOptions` field (pitch,
  budgets, costs, heuristic weight, policy switches).

With `--progress`, every `detailed_net` finished event carries a process-local
`search_identity` hash of that key (equal-content boards share a token), so
repeats can be counted in any stage. The search is a pure function of these
inputs: it does not mutate the index, and its grid caches are geometry-only.

Fast iteration used `nrf52` (the smallest example that reaches detailed
repair; `round-led-ring` stops at package access) and synthetic corridor
boards in `tests/test_repair_search_reuse.py`. Full-vertical was run once at the
end, against the unprofiled merged-base baseline on the same machine.

## Measurement

Full-vertical on one Linux machine, CPython 3.12.3, `PROFILE=none`, unchanged
settings. Baseline: the merged base (`build/fv-baseline-noprof/`). Candidate:
this change from a separate worktree (`build/fv-reuse/`). Both are ignored
local evidence; both pass with zero native KiCad violations or opens.

| Detailed work | Baseline | With reuse |
| --- | ---: | ---: |
| All attempts (reused included) | 201 | 201, 16 reused |
| Displaced (`evicted_net`) | 77, 559.3 s | 77, 12 reused, 432.1 s |
| `soft_ripup` | 10, 46.1 s | 10, 4 reused, 22.7 s |
| `final_retry` | 6, 143.2 s | 6, 98.4 s |
| Passes (not memoized) | 98, 233.2 s | 98, 299.6 s |
| `detailed_repair` phase | 783.5 s | 599.5 s |
| Runner wall time | 1,091.5 s | 980.9 s |

The candidate's identity telemetry covers all 201 attempts. Exactly 16 repeat
an earlier identity, all in repair: **12 of 77 displaced searches** and four
`soft_ripup` proposals equal to their `soft_merge` search. When first computed
these searches cost **112.7 s** (91.2 s displaced, 21.6 s soft). No pass or
final retry repeated and the memo evicted nothing (87 of 128 entries).

| Repeated displaced net | Repeats | First-computed cost |
| --- | ---: | ---: |
| `V5` (all failures) | 3 | 50.1 s |
| `USB_C_CURRENT_1` | 2 | 21.1 s |
| `PWR/MODEM_FB` | 2 | 12.1 s |
| `USER_LED_2_A` (failure) | 1 | 6.0 s |
| `MCU_SWDCLK`, `MCU_MODEM_TX`, `USER_LED_1`, `MCU_MODEM_RX` | 1 each | 1.9 s |

Repeated soft proposals were `GNSS_RX`, `GNSS_TIMEPULSE`, `GNSS_TX` (about 7 s
each) and `MCU_NRF_RX`. So duplicates are a minority: 15 of `V5`'s 18 displaced
failures are distinct trial boards.

On `nrf52`, the only repeat is the `XTAL_1` soft proposal (4.7 s); its one
displaced search does not repeat. Its ordinary area routing took 121.4 s
before both changes and 71.1 s after, mostly from cheaper 0.5 mm pass grids
(below); those two runs also saw different machine load.

The pass stage, whose search is unchanged apart from faster grid blocking, took
28% longer in the candidate. The machine carried more concurrent routing load,
so wall and phase times are observations, not a matched speedup. The skipped
search seconds and the grid timings below are the load-independent evidence.
`routing_benchmark compare` finds no quality regression; it withholds a timing
ratio because the checkout paths change the recorded inputs and arguments.

Structure explains the repeats. Every rip-up order rebuilds the same trial
copper, so the first displaced net of two orders is searched twice against an
identical index: with three blockers, three of the six permutations repeat;
with four, the reversed order and the third rotation share a first net. A soft
proposal is also searched twice when no merge changes the board between the
`soft_merge` and `soft_ripup` stages. Repeats deeper in an order are not exact:
the earlier reroutes differ.

## What remains in the displaced searches

Most displaced time is not repeated. `V5` fails by budget exhaustion
("octilinear and fallback search budgets exhausted for U_MODEM.61") against a
different trial board in each order. That cannot be pruned soundly: extra
copper can shrink the explored space so that a budget-limited search that
failed before succeeds, and finite access-candidate sets change with nearby
copper. Even an exhaustive no-path result is not monotone for the same reason.
These failures are left as real searches.

The second driver was grid construction. A displaced net that cannot reach a
terminal refines 1 → 0.5 → 0.25 → 0.125 → 0.1 mm and rebuilt every mesh per
attempt. On the full-vertical outline (100 × 80 mm, six layers, template
placement, concurrent load) the blocked-node scan measured:

| Pitch (mm) | Before (s) | After (s) |
| ---: | ---: | ---: |
| 1 | 0.147 | 0.033 |
| 0.5 | 0.525 | 0.121 |
| 0.25 | 2.225 | 0.463 |
| 0.125 | 8.429 | 1.669 |
| 0.1 | 12.840 | 2.440 |

Material is layer-independent, so each point is now tested once instead of
once per copper layer, and a keepout polygon only inside its inclusive bounding
box (exact: a point outside it is neither on nor inside the polygon). Within a
repair stage, the same board and axes also reuse their blocked-node set from a
16-entry table (63 hits in the candidate); each grid keeps fresh query caches.
In the baseline, `MCU_NRF_TX` failed three displaced searches through this full
chain, an estimated 24 s of meshing each: its four displaced attempts took 93.2 s,
and 24.7 s in the more loaded candidate run.

## Change

`_repair_from_passes` gets one bounded memo per routing run's repair stage
(`--search-reuse-entries`, default 128, LRU; `0` disables). All four repair
stages (`soft_merge`, `soft_ripup`, `evicted_net`, `final_retry`) consult it.
A failure is reused only for an identical key, so any change in blocking copper,
keepouts, rules, guides, anchors, congestion or options is a new search. Pass
searches are not memoized; none repeated on either board, and existing tests
pin their search counts. The single material test per point applies to every
grid build, passes included.

Telemetry only: finished events add `search_reuse` (`hit`/`miss`) and, for a
hit, `reused_search_seconds`; a `detailed_search_reuse` summary follows
`detailed_repair`; `routing_benchmark summarize` reports
`reused_detailed_attempts` and treats the bound like the other explicit
interventions. None of this enters the IR, reports or fingerprints.

## Determinism evidence

Full-vertical, baseline versus candidate:

- The 472 progress events are identical (every stage, net, owner, pitch,
  connectivity, track/via count and diagnostic; elapsed time and reuse
  telemetry and the added reuse summary excluded) except the report path in
  the final export event.
- Global and critical fingerprints, the export digest `077dae49…`, every
  report net/metric and the native KiCad result are identical. The saved
  filled boards differ only in 102 footprint-property UUIDs that KiCad assigns
  on save.
- The detailed fingerprint, board/DRC/filled-board digests and the package
  boundary `source_digest` differ. Each includes `physical_board_digest`, which
  hashes footprint `source_path` metadata: an absolute path into the
  checkout's package cache. The boundary digest differs before detailed
  routing starts, so this is checkout provenance, not routing.

`nrf52` gives an identical 110-event stream for the merged-base grid code with
reuse disabled and for this change;
its build stops at export with a pre-existing `filled-capped via-in-pad`
profile error, after routing, in both runs.

Tests in `tests/test_repair_search_reuse.py` cover: a key change for every
obstacle, board, rule, guide, anchor, congestion, mode, checkpoint and option
field; ordered insertions and lock flags; identical object returned on a hit
without searching; a failure that is searched again after its blocker moves or
disappears; a real displaced-net repair with three exact repeats (13 → 10
searches) and an identical result/event sequence; byte-identical
`route_detailed` JSON and fingerprints with and without reuse; the LRU bound
and disable switch; the blocked-node oracle on keepouts, concave polygons,
holes and cutouts; and benchmark telemetry.

## Limitations

- Scope is one repair stage of one `route_detailed` call. Placement trials,
  zone repairs and the neutral fallback route new board objects or options
  and get their own memo; equal-content boards in different objects are not
  shared (conservative).
- Insertions are keyed in order. A permutation of the same copper is not
  reused, although clearance answers are order-independent.
- Wall times are observations on a shared 14-core machine with other routing
  jobs running; they are not a matched benchmark or a speedup claim.
- This does not reduce budget-exhausted searches, the bulk of displaced time.

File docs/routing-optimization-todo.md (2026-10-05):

# Routing optimization implementation work list

Implement in this order. Correctness gates are shared across every item: preserve
critical ownership and exact clearance/via-span checks, reject connectivity/DRC
regressions, keep deterministic selection, and retain a conservative fallback.
See [the assessment](routing-performance.md) for evidence, limitations and sources.

## O0 — Reproducible measurements

- [x] Enable full-run function profiles, phase timings, provenance and exit-status checks.
- [x] Add read-only run summaries and comparison gates that reject new named-net,
  pad, hard-DRC, coverage and independent-verification failures. Require matching
  recorded inputs/tools/settings and two uninstrumented runs for a timing ratio.
  `tests/test_routing_benchmark.py` covers missing/stale data, mixed profiling,
  dropped or exchanged failed nets, swapped finding categories and legacy logs.
- [x] Expose per-net/pass detailed progress before grid construction, including
  soft/evicted/final repair and neutral-fallback work. Count all completed attempts
  separately from selected nets; preserve unfinished events without claiming
  closure. Observer-on/off tests retain identical geometry, results and exports.
- [x] Capture a current full-board profile. `7d7673f`, saved in ignored
  `build/full-vertical-staged-indexed-20261005/`; exit 1 with three ordinary opens
  and failed native signoff. A finished profile is not a finished board.
- [ ] Capture a matched uninstrumented comparison run.
- [ ] Record expanded states, affected-net count, local/probe searches, full-pipeline
  evaluations and peak memory; distinguish selected work from rejected trials.
- [ ] Retain representative dense-package, power-tree and repair fixtures so
  optimization work does not depend on a 66-minute board run alone.

## O1 — Reduce whole-board reroutes (first implementation)

- [x] O1a: Extend existing same-placement local rip-up with a bounded dependency
  cone. If subset routing fails, route a temporary probe without unrelated ordinary
  area copper, use exact clearance queries to identify further blockers, then
  retry the enlarged subset against all preserved copper. Never commit probe copper.
  Cap net count/expansion rounds; reject locked blockers and fallback on failure.
- [x] O1a tests: secondary blockers, no-progress/cap failures, rollback, locked
  copper, immutable fanout, all-layer via blockers and deterministic repeated results.
- [x] O1a telemetry: expose subset/probe work and accepted affected nets in progress
  and reports; add an explicit zero-expansion comparison mode.
  `tests/test_local_dependencies.py` uses the real detailed router and native DRC
  on a retained corridor fixture: A-only repair fails; the exact probe discovers
  B; A+B repair succeeds after one expansion while C and the fixed reservation
  survive unchanged. Further controller tests check inner-layer via blockers and
  noncommitting probes. This proves bounded repair behavior, not full-board speedup.
- [x] O1b: Extend the transaction to legal small placement moves/rotations. Invalidate
  incident ordinary nets and detect moved-pad/keepout or early-contact collisions;
  preserve unrelated copper and recompute global guides/fingerprints. Rebase access
  evidence, clearing obsolete domain statistics rather than treating them as fresh.
  Rebuild contacts on affected zone nets, retaining critical return vias. Initially
  fallback for moved critical endpoints, rigid clusters, crowded package-access
  owners, unsupported geometry changes or excessive cones. Package exits belonging
  to a moved crowded owner are not reused: that candidate takes the full pipeline.
- [x] O1b tests: real incident-net reroute, unchanged critical copper, deterministic
  replay, explicit 45-degree rotation, refreshed stage evidence, collision/ownership
  and dependency-limit rollback. A controlled real-router comparison performs zero
  full-pipeline evaluations with incremental repair enabled and one when disabled.
  `tests/test_incremental_placement.py` and `tests/test_escape_feedback.py` retain
  these fixtures. This is a work-count measurement, not a full-board timing claim.
- [x] O1b telemetry/comparison: report changed references and rebuilt zone nets;
  `--no-incremental-placement-repair` retains full-pipeline placement trials.
- [ ] Extend incremental ownership to moved crowded packages/rigid macros only after
  explicit pad-level exit ownership and joint access revalidation are available.
- [ ] O1c: Reserve failing package ground groups jointly with required access and
  retain already-accepted contacts. Evaluate whether this avoids late feedback.
- [ ] O1d: Benchmark successful and failed repair cases, then the full board. Require
  fewer full evaluations or lower uninstrumented time without worse closure/DRC.
  The read-only comparison harness is implemented. Current-board profile launched
  from routing commit `39a44d7` on 2026-10-02; completion and uninstrumented paired
  measurements must be recorded before this benchmark item can be checked off.

## O2 — Reduce geometry/allocation overhead

Current measured work: [early negotiation and indexed geometry plan](routing-search-speed-plan.md).
Next sequence: [Python-first exact predicates and lazy DRC distances](python-routing-optimization-plan.md).

- [x] Use full profiles to select significant self-time/call-count hot paths.
- [x] Cache immutable rounded-shape bounds; spatially index static keepouts/macro
  regions separately from mutable copper. Fresh board snapshots build fresh
  indexes; huge envelopes fall back conservatively. Linear-oracle tests retain
  exact tangency, layer/flag, hole-policy and transformed-geometry semantics.
- [x] Negotiate package patterns after bounded initial pair-search slices,
  retaining original-pattern full-budget fallback and strict owner gates.
  The profiled matched-placement preflight passes with unchanged selected
  copper and 6,397 actual states across all passes versus 728,263 in the earlier
  full-budget log. This is a work-count result, not a full-route timing ratio.
- [x] Replace Boolean rational-distance calculations with exact integer products;
  use lazy DRC measurements for violations, preserving half-nanometre thresholds.
  Rational-oracle tests retain complete finding and selected-route identity.
- [x] Cache placed track-keepout shapes per immutable board and coordinate/block
  identities per grid; retain inputs against ID reuse and invalidate replaced
  snapshots. Reuse query rays and avoid ignored endpoint-node/set allocations.
  Seeded uncached-oracle and construction-count tests cover these changes.
- [ ] Extend caching beyond bounds to coordinate/placed-pad/port construction where profiles justify it.
- [ ] Reuse placed-pad/keepout snapshots across search indexes separately from mutable copper;
  define placement, clearance and copper-revision invalidation keys before reuse.
- [ ] Tune spatial-bin sizes on realistic footprints, retaining exact narrow-phase checks.
- [ ] Benchmark each change and run tangency, rotated-pad, drill and full-span-via tests.

## O3 — Reduce maze states

- [ ] Record guide expansions, budget exhaustion, no-path failures and target-set sizes.
- [ ] Add cheap feasible-port/layer reachability screening before costly repairs.
- [ ] Evaluate tighter adaptive/coarse-to-fine corridors with wide/neutral fallback.
- [ ] Index large tree-target sets only if profiles justify the added machinery.
- [ ] Compare expanded states, routability, quality and uninstrumented time; do not
  count lowered search budgets or newly failed routes as performance improvements.

## O4 — Process-level candidate parallelism

- [ ] Define portable immutable worker inputs (existing metadata uses mapping proxies).
- [ ] Implement bounded independent placement/global candidate workers with isolated
  routing state and temporary paths; begin with 1/2 workers and measure memory/IPC.
- [ ] Select in deterministic original candidate order, not completion order.
- [ ] Add interruption/error cleanup and reject stale-incumbent speculative results.
- [ ] Compare 1/2/4 workers before enabling a default. Do not parallelize dependent
  ground trials or per-net shared-copper searches without conflict reconciliation.

## O5 — Native kernels, only if still justified

- Deferred by the Python-first decision: finish and measure applicable Python
  algorithm/data-structure/allocation improvements before evaluating alternatives.
- [ ] Re-profile after O1–O4; select a narrowly bounded remaining hot kernel.
- [ ] Retain the Python oracle and prove integer-overflow/exact-predicate behavior.
- [ ] Verify deterministic tie-breaking and cross-platform deployment before adoption.

Completed implementation entries must name tests and measurements. A benchmark or
prototype is not full-board signoff; remaining board-production gates stay open.

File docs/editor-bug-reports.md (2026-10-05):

# CopperScript editor bug and feature reports

This document records the reported editor behaviours, the verification method,
and the disposition of each item.  Verification was done against the current
`pcbir/editor` implementation, the editor unit tests, and the disposable
Playwright smoke tests where browser interaction was relevant.

## E-001 — keyboard shortcuts are incomplete

**Status: confirmed and fixed.**

The editor already handled arrows, `R`, `+`, `-`, `F`, and `Escape`, but had no
keyboard action for temporary lock/unlock, undo/redo, reverse rotation, or side
flip.  The toolbar remained the only way to perform those actions.

The editor now supports:

| Shortcut | Action |
| --- | --- |
| `L` | Lock the selected temporary pose |
| `Shift+L` or `U` | Unlock the selected temporary pose |
| `R` / `Shift+R` | Rotate to the next / previous allowed orientation |
| `S` | Toggle front/back when the side is not constrained |
| `Ctrl/Cmd+Z` | Undo |
| `Ctrl/Cmd+Shift+Z` or `Ctrl/Cmd+Y` | Redo |
| `Home` or `F` | Fit the board |

Existing arrow movement, zoom, pan, `Enter`, and `Escape` behaviours are
unchanged.

## E-002 — pad names are not visible while inspecting a package

**Status: confirmed and fixed.**

Before this change, pads had a browser `<title>` containing the reference,
number, and net, but no visible label.  The physicalizer now carries optional
part pin names as board metadata.  The scene exposes that name per pad and the
editor renders the name (or physical pad number when no name is available) for
each pad.  Labels are hidden until the pointer hovers the corresponding pad,
use the pad's user-coordinate geometry for their font size, and compress long
names to the available land width.  The complete reference/net tooltip remains
available at every zoom level.

## E-003 — connector body boxes can be offset from the actual footprint

**Status: confirmed and fixed.**

The editor previously drew every body as a `body_size` rectangle centered at the
placement origin.  That is incorrect for footprints whose origin is deliberately
on a contact or mounting datum.  In the resolved full-vertical footprint,
`J_CAN` has a local courtyard from approximately `x=-3..13 mm`, while the old
body box was centered at `x=-8..8 mm`.

The scene now derives an origin-preserving visual body envelope from the
footprint's non-courtyard graphics and pad envelopes, with the old centered box
retained as a fallback for minimal proxy footprints.  Courtyard and placement
legality geometry remain unchanged and continue to use the authoritative
footprint courtyard.

## E-004 — moving a component can snap back when a relative distance rule is
violated

**Status: confirmed and fixed for interactive editing.**

`EditorSession.operation("move")` previously called the full placement legality
predicate.  That predicate includes relative distance/alignment rules, so a
temporary drag was rejected even when board bounds, keepouts, package clearance,
source locks, and rigid macros were all legal.

The editor now uses a hard-geometry legality predicate for temporary move and
apply operations.  Relative rules remain strict for automatic placement,
source validation, routing, and manufacturing signoff.  A temporary pose that
breaks one is accepted as an inspection preview and reports:

* the violated rule, actual measurement, requested limit/tolerance, and excess;
* all participating component references;
* an orange warning outline/marker on each participating component; and
* a warning panel in the editor.

This keeps the source-authoritative workflow intact: saving a source edit still
requires the source placement to satisfy all represented constraints.

## E-005 — wheel zoom and right-click pan

**Status: verified; not a defect.**

The editor already binds the wheel to cursor-anchored zoom and a right-button
drag to pan.  The browser smoke test verifies both interactions, including that
right-dragging a footprint does not move it.  No code change was necessary.

## E-006 — selecting and moving a component group

**Status: requested and implemented.**

The editor now supports Shift-click selection.  A normal click-drag on any
highlighted component moves the complete selection by one snapped translation;
arrow movement uses the same group operation.  Rigid hard-macro members are
included automatically.  The server validates the group as one transaction,
rejecting unknown, source-position-locked, temporarily locked, or physically
illegal members without partially changing the session.  The existing preview /
apply behavior is preserved for preview drags.

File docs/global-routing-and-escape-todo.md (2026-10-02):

# Global routing and package escape implementation

This is a staged implementation checklist, not a claim that the full board is
routed. The original baseline was 51/58 detailed nets, with one global
via-resource overflow and seven pending fanouts. The latest full-route outcome
is [pass 13](routing-review-pass13.md), with three ordinary nets open.
[Pass 18](routing-review-pass18.md) is a partial escape-first experiment: all
76 ordinary exits allocate, but the modem USB pair fails compatibility. Each stage must
retain deterministic output and must not weaken exact native or KiCad DRC.

The new [package-access-first sequence](package-access-first.md#remaining-implementation-sequence)
tracks preflight gating, bounded legal placement repair, joint critical/power/GND
pattern allocation, onward ports and directional demand-derived margins.

## 1. Make global resources physically meaningful

- [ ] Record the current board's tile-size sensitivity and the contributors to
  the (57.5, 42.5) mm via hotspot before changing routing behavior.
- [x] Remove courtyard-as-copper blockage; only copper/keepout geometry may
  obstruct tracks. Test a front-layer route beneath a large courtyard.
- [x] Estimate planar capacity per edge and layer from usable crossing width,
  actual pads/keepouts, and the net's width/clearance demand. Retain explicit
  safety margin rather than claiming exact detailed routability.
- [x] Estimate legal via sites per cell from the actual through-via size, drill,
  pad/hole clearance, and all-layer keepouts. Couple adjacent-layer transitions
  that consume the same physical through-via sites.
- [ ] Reserve or strongly penalize foreign-net use of declared plane layers;
  verify the resulting return-plane continuity after KiCad zone refill.
- [x] Distinguish no geometric route, over-capacity route, and abstract-model
  uncertainty in diagnostics; add focused tests and compare full-board results.

## 2. Represent multiple physical pad accesses

- [x] Enumerate deterministic candidate direct escapes and stub-plus-via
  options for each connected pad, with complete physical geometry, layer/span,
  cost, and rejection reason. Preserve fabrication-rule checks; never infer
  via-in-pad or blind/buried vias.
- [x] Use several candidates per pad in global routing instead of one nearest
  cell. Reserve only a selected access and report when no candidate is legal.
- [x] Make global guides expose the selected physical access and keep critical,
  fanout, and detailed routing compatible with it.
- [ ] Add focused QFP/QFN package tests and a physically realized nearest-
  access trap beyond the current synthetic candidate-selection fixture.
  - [x] Pass-15 fanout regression uses real radial candidate generation and
    rectangular via-only keepouts with two available sites. Low-slack ordering
    escapes both pins; nearest/reference-first allocation strands one. Broader
    QFP/QFN and joint escape coverage remains open.
- [ ] Benchmark candidate count, completion, runtime, and KiCad DRC against the
  baseline; do not call an abstractly connected net physically routed.

## 3. Solve package escapes together

- [x] Build a conflict graph for candidates belonging to nearby pins and nets.
  - [x] Enumerate immutable legal radial domains, prioritize low-slack pins,
    recheck selected escapes incrementally and expose initial/consumed-domain
    diagnostics. This is a tested first increment, not joint matching/search.
  - [x] Expand zero-radial domains with bounded straight/45-degree two-leg exits,
    verify actual multi-segment anchor copper and propagate explicit cleanup
    ownership. Pass 16 improves 69 to 72 matched crowded-pin exits; MCU.62/.64
    alternatives are still consumed by selected neighbors.
  - [x] Attribute local candidate conflicts and expand competing selected-pin
    domains, including pins with legal radial choices. Replay shows MCU_NRF_RX
    blocks every MODEM_EN exit and combines with MCU_MODEM_TX to block MCU_NRF_TX.
    Pass 17 adds exact lazy pair conflicts, both path orders and bounded local
    domain/group expansion, improving matched escapes from 72 to 74. MCU.62/.64
    remain pending; this is not onward area connectivity.
- [ ] Select a compatible set with deterministic bounded matching/search, then
  negotiated swaps for larger clusters; include onward-route cost.
  - [x] Implement bounded MRV/forward-checking with conflict-driven group growth
    and exact materialization/native rollback, preserving prior escaped
    identities and fixed outside/input copper. Onward cost and area-driven
    replacement remain open.
  - [ ] Constrain multi-bend alternatives around competing selected escapes for
    the remaining MCU conflict groups, or legal whole-unit placement feedback;
    reverify multi-leg contacts/ownership before attempting the full rerun.
- [ ] Keep escapes provisional until area routing succeeds and allow local
  replacement of an escape that blocks a later net.

## 4. Upgrade global-to-detailed feedback

- [ ] Re-route hotspot contributors with alternative topologies and layer
  transitions; use multi-terminal topology with width-aware resource demand.
- [ ] Feed exact pin-access failures, via blockers, guide deviations, and
  exhausted searches back into global costs and candidate selection.
- [ ] Prefer guide regions to compulsory single transition coordinates.

## 5. Prove board closure

- [ ] Fix repeated-number physical-pad connectivity accounting.
- [ ] Achieve 58/58 detailed nets, zero KiCad unconnected items after zone
  refill, and no unwaived native/KiCad DRC errors.
- [ ] Verify determinism, routing runtime, plane continuity, and manufacturing
  rules on the pinned four-layer JLCPCB profile before release artifacts.

Primary research: [OpenROAD/FastRoute](https://openroad.readthedocs.io/en/latest/main/src/grt/README.html),
[CUGR](https://cwpui.com/doc/c10.pdf),
[concurrent PCB escape/area routing](https://ieeexplore.ieee.org/document/9586143/),
[variable-rule matching escape routing](https://scholars.lib.ntu.edu.tw/entities/publication/84cb474e-5460-4f5a-a1b7-208929c42bea),
[negotiated PCB escape routing](https://scholars.hkbu.edu.hk/en/publications/a-negotiated-congestion-based-router-for-simultaneous-escape-rout/),
and [TritonRoute pin access](https://vlsicad.ucsd.edu/Publications/Conferences/363/c363.pdf).

## Step 1–2 implementation notes

The current increment replaces surface-courtyard obstruction with pad/keepout
crossing estimates, samples legal independent via sites, couples transitions
using a single through-via cell resource, and exposes multiple candidate
direct or through-via pin accesses. Direct access can use a bounded local
eight-direction search around foreign pads. Selected access geometry is
carried in global guides, and ordinary detailed routing remains free to choose
another legal physical realization. Candidate accesses are checked
**individually**, not as a mutually compatible set. A `region_only` candidate
has a legal pad exit but no proven copper path to its coarse guide center; it
is counted separately, and detailed routing must close it. Simultaneous
selection and replacement are explicitly step 3. A global route remains a guide, never a
DRC signoff or proof that a through-via at a guide cell center is legal.

On the pinned four-layer full-vertical board with a 5 mm global tile, two
negotiated iterations, and one placement trial, this increment produced guides
for **58/58 nets with zero modeled overflow**. Seven selected pad exits are
`region_only` and remain subject to detailed routing. A deliberately bounded
one-pass, 1 mm/2,000-state detailed smoke run routed 27/58 nets and introduced
no hard geometry findings; that run is not comparable to the earlier eight-pass
51/58 detailed baseline and is not signoff.
The like-for-like eight-pass rerun was stopped after more than eight minutes
without a report; its completion count is therefore unknown. Runtime
profiling and the complete detailed/KiCad comparison remain open acceptance
work for step 2.

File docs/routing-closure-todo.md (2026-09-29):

# Routing closure work list

Baseline: the matched four- and six-layer full-vertical experiments each
connected 45/58 nets. The six-layer draft left eight search-budget failures,
four `cannot reach` failures, and GND pending verified fill. It also contained
two same-net via drill-spacing violations; the added In3/In4 layers were unused.

- [x] Reserve dedicated inner GND-zone layers from foreign-net global,
      critical, fanout, and detailed routes.
- [ ] Stitch GND pads and verify the actual KiCad zone fill and continuity.
- [x] Reject or repair vias too close to other vias in the *same candidate
      net*, including branches created within one multi-terminal route.
- [x] Make global guides and detailed search use available signal layers when
      a direct front-layer path is congested, without adding forbidden
      transitions or destroying the return plane.
- [ ] Improve dense-package pad access with compatible escape choices and
      placement feedback; distinguish a genuinely blocked pad from a bounded
      search failure.
- [x] Model duplicated physical lands sharing one logical pad number (the
      TL3342 button has two separate `SW_USER.1` lands). Require a verified
      internal-tie declaration or a legal copper stitch so KiCad and native
      connectivity agree.
- [ ] Resolve the four still-pending duplicated connector shield lands and
      all GND contacts without relying on an unqualified internal tie.
- [x] Rerun matched four/six-layer experiments and KiCad DRC. Record open
      nets, layer usage, via count, and drill spacing.
- [ ] Resolve every open net, verify GND zone fill and all pad stitches, then
      run physical DRC and manufacturing/CAM signoff.

No generated board is manufacturing-ready until every connection and required
physical/electrical/CAM gate passes.

Progress: the layer reservation and tentative-via checks have focused
regression tests. With progressive guides, the detailed router now tries a
layer-projected geometric corridor before its unrestricted search; an
alternate-layer wall-crossing regression passes. A six-layer 1,000-state
smoke run connected 31/58 nets, matching the previous short-run scale, and
confirmed that non-GND global guides avoid In1.Cu. A matched six-layer
5,000-state run *before* the projected-guide fallback connected 43/58 nets;
the prior baseline was 45/58. Independent KiCad 10 DRC with zone refill
found no drill-spacing errors or copper shorts, but 153 unconnected items
and eight footprint-library findings.

The same settings with projected guides and GND-pad stitching produced:

| Draft | Routed nets | Signal-route vias | Pending GND pads | KiCad unconnected items |
|---|---:|---:|---:|---:|
| Four layers | 50/58 | 97 | 12 | 35 |
| Six layers | 51/58 | 96 | 8 | 30 |

Six-layer ordinary copper now uses F.Cu, In2.Cu, In3.Cu, In4.Cu, and B.Cu;
In1.Cu remains the GND plane. Both KiCad DRC reports show eight footprint
library findings, no copper shorts, and no drill-spacing violations.
With dense-pin fanout, bounded rip-up, and a 10x failed-net search repair,
the six-layer late-stitch draft routed all 57 signal nets. The new
duplicate-pad closure connected both button lands, and off-grid reuse of
existing GND vias cut new stitch drills from 66 to 50. KiCad 10 then
reported 14 GND unconnected items and zero signal gaps, copper shorts, or
drill-spacing violations. Eight GND pads and four duplicated connector
shield references remain pending in the closure stages; eight footprint
library lookup/mismatch warnings remain for qualification.

An experimental all-early plane stitch connected every targeted GND pad,
but blocked V3V3 (31 KiCad V3V3 gaps); selectively reserving the eight
previously pending GND pads also blocked V3V3. Early plane reservation is
therefore opt-in only. A broader three-candidate placement experiment with
two detailed-feedback trials again yielded 57/58 logical nets and 14 KiCad
GND opens. Those trials were targeting deliberately deferred GND; placement
feedback now excludes deferred plane nets and reserves a separate plane-aware
objective for future work. Ground escapes now try a bounded two-segment
Manhattan path when a direct pad-to-via trace is blocked, retaining exact
copper and board-edge checks. The first rerun improved the pending GND-pad
count from eight to seven, and KiCad's refilled-zone DRC improved from 14 to
13 GND opens without introducing copper shorts or drill-spacing violations.
Repeated connector shield lands now also try a bounded three-segment lateral
detour. The next rerun stitched J_CELL.2, J_GNSS.2, and J_SIM.SH; only
J_POWER.SH remained pending, and KiCad's open count fell from 13 to 9.
The plane stage now separately escapes every physical SMD land sharing a
logical pad number instead of silently taking the first; a full-board rerun
reduced KiCad's open count from 9 to 7 and resolved the USB-C shield gap.
The remaining seven opens are GND contacts around the CC controller, MCU
decoupling/level shifter, and GNSS. KiCad reports no copper-short or
drill-spacing violations, but eight footprint-library warnings remain.
None of these drafts is production-ready.

A 0.25 mm candidate grid and 5 mm plane-via search radius (versus the
default 0.5 mm/3 mm) reduced KiCad's open count from seven to five, but
introduced one new F.Cu copper-sliver warning. The larger/finer search is
therefore experimental rather than a clean improvement. A bounded
three-segment pad-to-via detour is being compared on the original coarse
grid. The seven-open default-grid draft remains the cleanest independent
DRC result aside from eight footprint-library warnings.

The 1.5 mm three-segment detour on the original coarse grid did not change
the seven-open KiCad count, so it remains opt-in. A 0.12 mm local GND escape
width also left seven opens. Its first draft exposed a project-rule bug:
KiCad inherited a 0.20 mm *minimum* width and rejected all 85 narrow traces.
Minimum track width is now first-class in the physical IR, native DRC, signed
geometry digest, fabrication profile, and exported KiCad project. The
regenerated 0.12 mm draft passed KiCad's corrected width rule, but still had
seven GND opens and eight footprint-library warnings.

A bounded same-net pad-to-escaped-pad rescue can build short surface chains
to one legal plane via instead of requiring a via at every GND pad. Its 5 mm
full-board experiment added one surface track but left seven KiCad opens and
eight footprint-library warnings. It is opt-in (default contact radius zero)
until plane-aware placement, a more capable legal access search, or a targeted
site move shows an actual improvement on this board.

An opt-in six-layer GND via-in-pad experiment is now available with
`--ground-via-in-pad` in the stitched route flow. It attempts a 0.30/0.20 mm
filled-and-capped via at the pad center only when ordinary escape fails, and
reports the manufacturing requirement separately from KiCad geometry. It must
pass independent zone-refilled KiCad DRC and a separately confirmed JLCPCB
plated-over-filled via order before it can count toward board closure.
The first full-board pass provisionally closed U_CC.3 (six opens), but KiCad
found four hole-to-copper clearance errors at that via plus generic minimum
via-rule errors. The corrected planner and native DRC now enforce the board's
0.25 mm hole-to-copper rule; the matched six-layer rerun placed no filled via.
Independent KiCad 10 DRC after zone refill again reports seven GND opens and
eight footprint-library warnings, with no new copper or drill violations.
Completing these pads needs a layout/routing change or a separately reviewed
local fabrication rule, not merely permission to use via-in-pad.

The octilinear-preferred detailed router and plane-first GND flow were tested
on the six-layer full-vertical board. With a 20,000-state base search budget
and the existing 10x repair limit, all 57 ordinary nets routed; GND remains
intentionally deferred to verified filled copper. Signal copper totals about
1,253 mm straight, 321 mm at exactly 45 degrees, and 87 mm of short
non-octilinear lead-ins/critical copper (about 95% straight or 45 degrees).
The local plane-contact stage added 117 short GND tracks and 61 vias, not a
long GND maze tree. Ground via-in-pad was enabled but could not legally reach
the two remaining U_CC ground lands. Independent KiCad 10 DRC after zone
refill reports two GND unconnected items, eight footprint-library warnings,
and no other violations. The board is still not fabrication-ready: U_CC.10 and
U_CC.11 need a component/placement or local geometry solution, and the
footprint warnings still need review. At the smaller 5,000-state budget V3V3
exhausted search, so the full-board verification requires the larger bound.

A bounded octilinear local escape search and transactional zone-pad placement
feedback now target pads that fail late. Explicitly allowed 45-degree component
orientations participate in placement; unconstrained parts remain cardinal. A
matched six-layer rerun with 5 mm same-net contact radius accepted a 0.5 mm
U_CC move: all 57 signal nets still route, and independent KiCad 10 zone-refilled
DRC improved from two GND opens to one, at J_SIM.SH. The iterative feedback now
retargets that newly pending shield while preserving the accepted U_CC early
contacts. Its next two full-route trials found legal provisional shield escapes
but both reopened V3V3; they were correctly rejected. The best board remains
one GND open with eight footprint-library findings and no copper-rule
violations, so it is not manufacturing-ready. Next: inspect J_SIM.SH's local
track/via access against the V3V3 corridor, try finer legal via sites or a
larger placement move, and only accept a candidate after full rerouting plus
KiCad zone-refilled DRC. The four full-route feedback trials are expensive;
cheap blocker-aware preflight ranking is also needed before scaling this loop.

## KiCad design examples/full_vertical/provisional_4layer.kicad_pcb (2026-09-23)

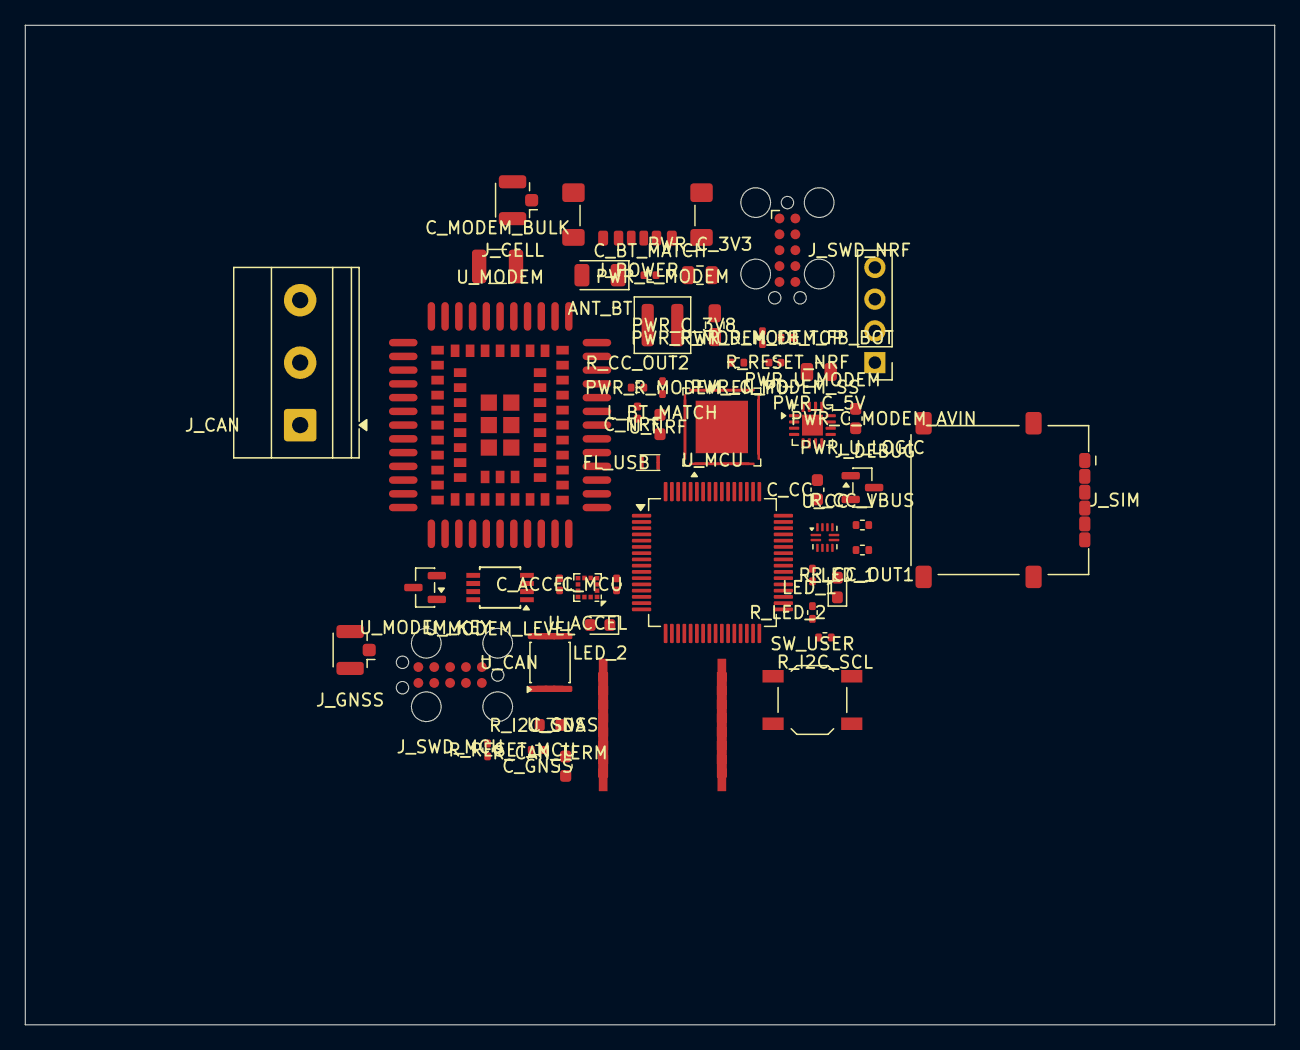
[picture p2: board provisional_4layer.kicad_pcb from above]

Board: 4 copper layers, 100.0 x 80.0 mm, 51 parts (0 on the bottom side), 58 nets, no tracks yet.

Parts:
ANT_BT: RF_ANTENNA; Johanson_2450AT18x100
C_ACCEL: 1E+2 nF; C_0402_1005Metric
C_BT_MATCH: 0.8 pF; C_0402_1005Metric
C_CC: 1 uF; C_0603_1608Metric
C_GNSS: 1 uF; C_0603_1608Metric
C_MCU: 1E+2 nF; C_0402_1005Metric
C_MODEM_BULK: 1E+2 uF; C_1210_3225Metric
C_NRF: 4.7 uF; C_0603_1608Metric
FL_USB: COILCRAFT_0603USB_601MLC; L_CommonModeChoke_Coilcraft_0603USB
J_CAN: CAN_CONNECTOR; TerminalBlock_Phoenix_MKDS-1,5-3_1x03_P5.00mm_Horizontal
J_CELL: RF_CONNECTOR; U.FL_Hirose_U.FL-R-SMT-1_Vertical
J_DEBUG: DEBUG_UART_HEADER; PinHeader_1x04_P2.54mm_Vertical
J_GNSS: RF_CONNECTOR; U.FL_Hirose_U.FL-R-SMT-1_Vertical
J_POWER: GCT_USB4135_GF_A; USB_C_Receptacle_GCT_USB4135-GF-A_6P_TopMnt_Horizontal
J_SIM: SIM8060_6_0_14_00_A; nanoSIM_GCT_SIM8060-6-0-14-00
J_SWD_MCU: SWD_HEADER; Tag-Connect_TC2050-IDC-FP_2x05_P1.27mm_Vertical
J_SWD_NRF: SWD_HEADER; Tag-Connect_TC2050-IDC-FP_2x05_P1.27mm_Vertical
LED_1, LED_2: LED; LED_0603_1608Metric
L_BT_MATCH: 3.9 nH; L_0402_1005Metric
PWR_C_3V3, PWR_C_3V8: 22 uF; C_0805_2012Metric
PWR_C_5V: 1E+1 uF; C_0805_2012Metric
PWR_C_MODEM_AVIN: 1E+2 nF; C_0603_1608Metric
PWR_C_MODEM_SS: 3.3 nF; C_0402_1005Metric
PWR_L_MODEM: XAL4020_222MEC; L_Coilcraft_XAL4020-XXX
PWR_R_MODEM_EN_PD: 1E+2 kohm; R_0402_1005Metric
PWR_R_MODEM_FB_BOT: 2E+2 kohm; R_0402_1005Metric
PWR_R_MODEM_FB_TOP: 7.5E+2 kohm; R_0402_1005Metric
PWR_U_LOGIC: REGULATOR_3V3; SOT-23
PWR_U_MODEM: TPS62130ARGTR; VQFN-16-1EP_3x3mm_P0.5mm_EP1.68x1.68mm
R_CAN_TERM: 1.2E+2 ohm; R_0603_1608Metric
R_CC_OUT1, R_CC_OUT2: 1E+1 kohm; R_0402_1005Metric
R_CC_VBUS: 9E+2 kohm; R_0402_1005Metric
R_I2C_SCL, R_I2C_SDA: 4.7 kohm; R_0402_1005Metric
R_LED_1, R_LED_2: 1 kohm; R_0402_1005Metric
R_RESET_MCU: 1E+1 kohm; R_0402_1005Metric
R_RESET_NRF: 1E+1 kohm; R_0402_1005Metric
SW_USER: BUTTON; SW_SPST_TL3342
U_ACCEL: LIS2DW12; LGA-12_2x2mm_P0.5mm
U_CAN: TCAN334G; VSSOP-8_3x3mm_P0.65mm
U_CC: TUSB320LAI; Texas_X2QFN-12_1.6x1.6mm_P0.4mm
U_GNSS: MAX_M10S_00B; u-blox_MAX-M10S
U_MCU: STM32G0C1RET6; LQFP-64_10x10mm_P0.5mm
U_MODEM: EG800G_EU; Quectel_EG800G
U_MODEM_KEY: OPEN_DRAIN_DRIVER; SOT-23
U_MODEM_LEVEL: DUAL_UART_LEVEL_SHIFTER; TSSOP-8_3x3mm_P0.65mm
U_NRF: NRF52832_QFAA; QFN-48-1EP_6x6mm_P0.4mm_EP4.2x4.2mm

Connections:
ACCEL_INT: U_ACCEL.12, U_MCU.15
CAN_H: J_CAN.1, R_CAN_TERM.1, U_CAN.7
CAN_L: J_CAN.2, R_CAN_TERM.2, U_CAN.6
CAN_RX: U_CAN.4, U_MCU.25
CAN_TX: U_CAN.1, U_MCU.26
CELL_RF: J_CELL.1, U_MODEM.35
DEBUG_RX: J_DEBUG.3, U_MCU.22
DEBUG_TX: J_DEBUG.2, U_MCU.21
GND: ANT_BT.2, C_ACCEL.2, C_BT_MATCH.2, C_CC.2, C_GNSS.2, C_MCU.2, C_MODEM_BULK.2, C_NRF.2, J_CAN.3, J_CELL.2, J_DEBUG.4, J_GNSS.2, J_POWER.A12, J_POWER.B12, J_POWER.SH, J_SIM.5, J_SIM.SH, J_SWD_MCU.3, J_SWD_MCU.5, J_SWD_NRF.3, J_SWD_NRF.5, LED_1.2, LED_2.2, PWR_C_3V3.2, PWR_C_3V8.2, PWR_C_5V.2, PWR_C_MODEM_AVIN.2, PWR_C_MODEM_SS.2, PWR_R_MODEM_EN_PD.2, PWR_R_MODEM_FB_BOT.2, PWR_U_LOGIC.2, PWR_U_MODEM.6, PWR_U_MODEM.7, PWR_U_MODEM.8, PWR_U_MODEM.15, PWR_U_MODEM.16, PWR_U_MODEM.17, SW_USER.2, U_ACCEL.3, U_ACCEL.6, U_ACCEL.7, U_ACCEL.8, U_CAN.2, U_CAN.5, U_CAN.8, U_CC.3, U_CC.10, U_CC.11, U_GNSS.1, U_GNSS.10, U_GNSS.12, U_MCU.9, U_MODEM.1, U_MODEM.10, U_MODEM.27, U_MODEM.34, U_MODEM.36, U_MODEM.37, U_MODEM.40, U_MODEM.41, U_MODEM.45, U_MODEM.46, U_MODEM.47, U_MODEM.48, U_MODEM.70, U_MODEM.71, U_MODEM.72, U_MODEM.73, U_MODEM.88, U_MODEM.89, U_MODEM.90, U_MODEM.91, U_MODEM.92, U_MODEM.93, U_MODEM.94, U_MODEM.95, U_MODEM_KEY.2, U_MODEM_LEVEL.4, U_NRF.31, U_NRF.45, U_NRF.49
GNSS_RF: J_GNSS.1, U_GNSS.11
GNSS_RX: U_GNSS.3, U_MCU.19
GNSS_TIMEPULSE: U_GNSS.4, U_MCU.16
GNSS_TX: U_GNSS.2, U_MCU.20
I2C_SCL: R_I2C_SCL.2, U_ACCEL.1, U_MCU.24
I2C_SDA: R_I2C_SDA.2, U_ACCEL.4, U_MCU.23
MCU_MODEM_RX: U_MCU.61, U_MODEM_LEVEL.3
MCU_MODEM_TX: U_MCU.60, U_MODEM_LEVEL.2
MCU_NRF_RX: U_MCU.63, U_NRF.8
MCU_NRF_TX: U_MCU.62, U_NRF.10
MCU_RESET: J_SWD_MCU.10, R_RESET_MCU.2, U_MCU.12
MCU_SWDCLK: J_SWD_MCU.4, U_MCU.46
MCU_SWDIO: J_SWD_MCU.2, U_MCU.45
MODEM_EN: PWR_R_MODEM_EN_PD.1, PWR_U_MODEM.13, U_MCU.64
MODEM_PWRKEY: U_MODEM.7, U_MODEM_KEY.3
MODEM_PWRKEY_CTL: U_MCU.13, U_MODEM_KEY.1
MODEM_STATUS: U_MCU.14, U_MODEM.25
MODEM_UART_RX: U_MODEM.17, U_MODEM_LEVEL.5
MODEM_UART_TX: U_MODEM.18, U_MODEM_LEVEL.6
NRF_RESET: J_SWD_NRF.10, R_RESET_NRF.2, U_NRF.24
NRF_RF_ANT: ANT_BT.1, C_BT_MATCH.1, L_BT_MATCH.2
NRF_RF_RAW: L_BT_MATCH.1, U_NRF.30
NRF_SWDCLK: J_SWD_NRF.4, U_NRF.25
NRF_SWDIO: J_SWD_NRF.2, U_NRF.26
PWR/MODEM_FB: PWR_R_MODEM_FB_BOT.1, PWR_R_MODEM_FB_TOP.2, PWR_U_MODEM.5
PWR/MODEM_SS: PWR_C_MODEM_SS.1, PWR_U_MODEM.9
PWR/MODEM_SW: PWR_L_MODEM.1, PWR_U_MODEM.1, PWR_U_MODEM.2, PWR_U_MODEM.3
SIM_CLK: J_SIM.3, U_MODEM.13
SIM_IO: J_SIM.7, U_MODEM.11
SIM_RST: J_SIM.2, U_MODEM.12
SIM_VCC: J_SIM.1, U_MODEM.14
USB_C_CC1: J_POWER.A5, U_CC.1
USB_C_CC2: J_POWER.B5, U_CC.2
USB_C_CURRENT_1: R_CC_OUT1.2, U_CC.7, U_MCU.48
USB_C_CURRENT_2: R_CC_OUT2.2, U_CC.8, U_MCU.49
USB_C_VBUS_DET: R_CC_VBUS.2, U_CC.4
USB_DM_MCU: FL_USB.2, U_MCU.43
USB_DM_MODEM: FL_USB.3, U_MODEM.60
USB_DP_MCU: FL_USB.1, U_MCU.44
USB_DP_MODEM: FL_USB.4, U_MODEM.59
USER_BUTTON: SW_USER.1, U_MCU.3
USER_LED_1: R_LED_1.1, U_MCU.38
USER_LED_1_A: LED_1.1, R_LED_1.2
USER_LED_2: R_LED_2.1, U_MCU.39
USER_LED_2_A: LED_2.1, R_LED_2.2
V1V8_MODEM: U_MODEM.24, U_MODEM_LEVEL.8
V3V3: C_ACCEL.1, C_CC.1, C_GNSS.1, C_MCU.1, C_NRF.1, J_DEBUG.1, J_SWD_MCU.1, J_SWD_NRF.1, PWR_C_3V3.1, PWR_U_LOGIC.3, R_CC_OUT1.1, R_CC_OUT2.1, R_I2C_SCL.1, R_I2C_SDA.1, R_RESET_MCU.1, R_RESET_NRF.1, U_ACCEL.2, U_ACCEL.9, U_ACCEL.10, U_CAN.3, U_CC.12, U_GNSS.6, U_GNSS.7, U_GNSS.8, U_MCU.6, U_MCU.7, U_MCU.8, U_MODEM_LEVEL.1, U_MODEM_LEVEL.7, U_NRF.13, U_NRF.36, U_NRF.48
V3V8: C_MODEM_BULK.1, PWR_C_3V8.1, PWR_L_MODEM.2, PWR_R_MODEM_FB_TOP.1, PWR_U_MODEM.14, U_MODEM.42, U_MODEM.43
V5: J_POWER.A9, J_POWER.B9, PWR_C_5V.1, PWR_C_MODEM_AVIN.1, PWR_U_LOGIC.1, PWR_U_MODEM.10, PWR_U_MODEM.11, PWR_U_MODEM.12, R_CC_VBUS.1, U_MODEM.61

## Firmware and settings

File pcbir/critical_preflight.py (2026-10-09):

"""Cheap critical-profile integration check, before ordinary board routing.

Run ``python -m pcbir.critical_preflight --help``. This uses the same placement,
global and critical stages as route-board, but never routes ordinary nets or
claims full-board/impedance signoff. Reports are checkpointed after global
routing so a later interrupted critical search retains useful evidence.
"""
from __future__ import annotations

import argparse
from dataclasses import asdict
from hashlib import sha256
import json
from pathlib import Path
from time import perf_counter
import traceback

from .backends.kicad_pcb import KiCadPcbBackend
from .backends.kicad_project import write_kicad_project
from .critical import (CriticalRoutingStatus, critical_lane_table, critical_net_document,
                       route_critical_nets)
from .critical_bundles import crossing_line, nested_exit_line
from .critical_feedback import improve_critical_placement
from .critical_review import critical_lane_review, lane_review_line
from .critical_tuning import match_tuning_line
from .drc import run_physical_drc
from .erc import check, has_errors
from .footprints import FootprintResolver
from .fanout import FanoutOptions
from .hard_macros import apply_hard_macro_scene
from .loader import BoardLoadError, load_design
from .physical import PadReference, nm_from_mm
from .package_access import preflight_package_access
from .pad_via_arrays import via_in_pad_array_report
from .plane import PlaneStitchOptions
from .physicalize import PrototypePhysicalOptions, prototype_physicalize, resolved_physicalize
from .placement import PlacementPlannerOptions
from .placement_templates import apply_placement_templates
from .routeflow import PlacementRoutingFeedbackOptions, optimize_placement_for_routing
from .routing import GlobalRouterOptions


def main(argv: list[str] | None = None) -> int:
    parser = argparse.ArgumentParser(description=__doc__)
    parser.add_argument("board", type=Path)
    parser.add_argument("--footprint-root", type=Path, action="append", default=[])
    parser.add_argument("--locked", action="store_true")
    parser.add_argument("--offline", action="store_true")
    parser.add_argument("--allow-proxy-footprints", action="store_true")
    parser.add_argument("--layers", type=int, choices=(2, 4, 6), default=6)
    parser.add_argument("--fab-profile", default="jlcpcb-six-layer")
    parser.add_argument("--candidates", type=int, default=1)
    parser.add_argument("--placement-candidate")
    parser.add_argument("--placement-templates", type=Path)
    parser.add_argument("--hard-macro", type=Path, action="append", default=[])
    parser.add_argument("--feedback-iterations", type=int, default=1)
    parser.add_argument("--critical-feedback-trials", type=int, default=0)
    parser.add_argument("--package-access", action="store_true",
                        help="also verify ordinary package exits and plane contacts before area routing")
    parser.add_argument("--stitch-surface-zones", action="store_true")
    parser.add_argument("--plane-contact-radius-mm", default="0")
    parser.add_argument("--prefer-local-ground", action=argparse.BooleanOptionalAction,
                        default=True)
    parser.add_argument("--prefer-local-ground-pad", action="append", default=[], metavar="REF.PAD")
    parser.add_argument("--router-iterations", type=int, default=5)
    parser.add_argument("--tile-size-mm", default="5")
    parser.add_argument("--report", type=Path, required=True)
    parser.add_argument("-o", "--output", type=Path, help="optional partial KiCad PCB")
    parser.add_argument("--debug", action="store_true",
                        help="print the full traceback of an error before its one-line summary")
    args = parser.parse_args(argv)
    timings: dict[str, float] = {}
    report: dict[str, object] = {
        "schema": "copperscript-critical-preflight/v0.1",
        "stage": "loading", "complete": False, "fabrication_ready": False,
    }

    def checkpoint(stage: str) -> None:
        report.update(stage=stage, phase_seconds=timings)
        args.report.parent.mkdir(parents=True, exist_ok=True)
        args.report.write_text(json.dumps(report, indent=2, sort_keys=True) + "\n", encoding="utf-8")
        print(f"CRITICAL PREFLIGHT: {stage}", flush=True)

    try:
        if args.critical_feedback_trials < 0:
            raise ValueError("critical placement feedback trial count cannot be negative")
        if args.package_access and args.critical_feedback_trials:
            raise ValueError("package-access preflight cannot use critical-only placement feedback")
        if not args.package_access and (args.stitch_surface_zones or args.plane_contact_radius_mm != "0"):
            raise ValueError("plane-contact options require --package-access")
        started = perf_counter()
        # The full design, not just its electrical IR: the mechanical block
        # carries the outline, holes, rules, edges and stack-up.
        design = load_design(args.board, locked=args.locked, offline=args.offline)
        diagnostics = check(design.electrical)
        if has_errors(diagnostics):
            for diagnostic in diagnostics:
                print(diagnostic)
            return 1
        options = PrototypePhysicalOptions(copper_layers=args.layers,
                                          fabrication_profile=args.fab_profile)
        board = (
            prototype_physicalize(design, options) if args.allow_proxy_footprints else
            resolved_physicalize(design, FootprintResolver(
                base_directory=args.board.resolve().parent,
                search_roots=tuple(root.resolve() for root in args.footprint_root),
                locked=args.locked, offline=args.offline), options)
        )
        if args.placement_templates:
            board = apply_placement_templates(board, args.placement_templates)
        for scene in args.hard_macro:
            board = apply_hard_macro_scene(board, scene, locked=args.locked, offline=args.offline)
        ground_pads = {
            pad for net in board.nets if net.name == "GND" for pad in net.pads
        }
        preferred_ground_pads: set[PadReference] = (
            set(ground_pads) if args.prefer_local_ground else set()
        )
        for value in args.prefer_local_ground_pad:
            reference, separator, number = value.rpartition(".")
            pad = PadReference(reference, number)
            if not separator or pad not in ground_pads:
                raise ValueError(f"preferred ground pad {value!r} is not a GND pad")
            preferred_ground_pads.add(pad)
        report.update(source=str(args.board.resolve()),
                      source_sha256=sha256(args.board.read_bytes()).hexdigest())
        if args.placement_templates:
            report["placement_template_scene_sha256"] = board.metadata["placement_template_scene_sha256"]
        if args.hard_macro:
            report["hard_macros"] = [{"scene": str(scene.resolve()),
                "scene_sha256": sha256(scene.read_bytes()).hexdigest()}
                for scene in args.hard_macro]
        timings["load_and_resolve"] = perf_counter() - started
        checkpoint("resolved")
        started = perf_counter()
        global_options = GlobalRouterOptions(tile_size_nm=nm_from_mm(args.tile_size_mm),
                                             maximum_iterations=args.router_iterations)
        placement = optimize_placement_for_routing(
            board, PlacementPlannerOptions(candidate_count=args.candidates), global_options,
            PlacementRoutingFeedbackOptions(
                maximum_iterations=args.feedback_iterations,
                initial_movement_nm=global_options.tile_size_nm,
                preferred_candidate_id=args.placement_candidate,
            ),
        )
        timings["placement_and_global"] = perf_counter() - started
        report.update(placement_candidate=placement.placement_candidate,
                      global_route_certified=placement.full_route_certified,
                      global_route=json.loads(placement.global_route.to_json()))
        checkpoint("global_complete")
        started = perf_counter()
        progress = []
        group_started = {}

        def critical_progress(event, nets, result):
            key = ",".join(nets)
            if event == "started":
                group_started[key] = perf_counter()
                progress.append({"nets": list(nets), "state": "running"})
            else:
                progress[-1].update(state="finished", seconds=perf_counter() - group_started[key],
                                    result=critical_net_document(result))
            report["critical_progress"] = progress
            checkpoint("critical_group_running" if event == "started" else "critical_group_complete")
            print(f"  {key}: {event}", flush=True)

        access = None
        if args.package_access:
            def access_progress(phase, event, details):
                progress.append({"phase": phase, "event": event,
                                 "elapsed_seconds": round(perf_counter() - started, 3), **details})
                report["package_access_progress"] = progress
                checkpoint(f"{phase}_{event}")
            access = preflight_package_access(
                placement.board, placement.global_route, FanoutOptions(),
                PlaneStitchOptions(
                    maximum_contact_radius_nm=nm_from_mm(args.plane_contact_radius_mm),
                    include_surface_zones=args.stitch_surface_zones,
                    preferred_ground_pads=frozenset(preferred_ground_pads)),
                on_progress=access_progress,
            )
            critical = access.critical
            report["package_access"] = {
                "ready": access.ready,
                "pending_pads": [f"{pad.component}.{pad.pad}" for pad in sorted(access.pending_pads)],
                "failed_critical_nets": sorted(access.failed_critical_nets),
                "hard_findings": access.hard_findings,
                "search_tiers": [asdict(tier) for tier in access.search_tiers],
                "plane_contacts": len(access.plane_stitch.stitched_pads) if access.plane_stitch else 0,
                "surface_zones": args.stitch_surface_zones,
                "maximum_contact_radius_nm": nm_from_mm(args.plane_contact_radius_mm),
                "preferred_ground_pads": [f"{pad.component}.{pad.pad}"
                                          for pad in sorted(preferred_ground_pads)],
            }
        else:
            critical = route_critical_nets(placement.board, placement.global_route, on_progress=critical_progress)
        if args.critical_feedback_trials:
            report["critical_baseline"] = json.loads(critical.to_json())
            report["critical_placement_feedback"] = []
            def trial_started(index, reference, trial_board):
                pose = next(pose for pose in trial_board.placements if pose.reference == reference)
                report["critical_placement_running"] = {
                    "index": index, "reference": reference, "rotation_degrees": str(pose.rotation_degrees),
                    "position_nm": [pose.position.x_nm, pose.position.y_nm],
                }
                checkpoint("critical_placement_trial_running")
            def trial_progress(trial):
                report["critical_placement_feedback"].append(asdict(trial))
                report.pop("critical_placement_running", None)
                checkpoint("critical_placement_trial_complete")
            repaired = improve_critical_placement(
                placement.board, placement.global_route, critical,
                maximum_trials=args.critical_feedback_trials,
                placement_options=PlacementPlannerOptions(candidate_count=args.candidates),
                global_options=global_options, on_trial_started=trial_started,
                on_trial=trial_progress, on_progress=critical_progress,
            )
            critical = repaired.critical
            report.update(critical_placement_accepted_moves=repaired.accepted_moves,
                          global_route=json.loads(repaired.global_route.to_json()),
                          global_route_certified=repaired.global_route.status.value == "success")
        timings["package_access" if args.package_access else "critical"] = perf_counter() - started
        result_board = access.board if access is not None else critical.board
        lane_review = critical_lane_review(critical.board, critical.nets, critical.match_tuning)
        report.update(complete=True, critical=json.loads(critical.to_json()),
                      critical_lane_review=lane_review,
                      native_drc=json.loads(run_physical_drc(result_board).to_json()))
        via_arrays = via_in_pad_array_report(result_board)
        if via_arrays:
            report["via_in_pad_arrays"] = via_arrays
        checkpoint("package_access_complete" if args.package_access else "critical_complete")
        if args.output:
            manifest = KiCadPcbBackend().generate(result_board)
            write_kicad_project(manifest, args.output)
        for item in critical.nets:
            print(f"{','.join(item.nets)}: {'connected' if item.connected else 'FAILED'} ({item.strategy})")
            for diagnostic in item.diagnostics:
                print(f"  {diagnostic}")
        for lane in critical_lane_table(critical.board, critical.nets):
            delay = (f"{lane['estimated_delay_ps']} ps screening delay"
                     if lane["estimated_delay_ps"] is not None else f"delay n/a ({lane['delay_reason']})")
            print(f"lane {lane['net']}: {lane['routed_length_nm'] / 1e6:.3f} mm, {lane['via_count']} vias, "
                  f"layers {','.join(lane['layers']) or '-'}, {delay}")
        for bundle in critical.bundles:
            print(f"bundle {'-'.join(bundle.components)}: order "
                  f"{', '.join('/'.join(group) for group in bundle.order)}; repairs "
                  f"{bundle.repairs_accepted}/{bundle.repairs_attempted} accepted "
                  f"(limit {bundle.repair_limit})")
            for crossing in bundle.crossings:
                print(crossing_line(bundle, crossing))
            for item in bundle.nested_exits:
                print(nested_exit_line(bundle, item))
        for tuning in critical.match_tuning:
            print(match_tuning_line(tuning))
        if lane_review["nets"]:
            print(lane_review_line(lane_review))
        if access is not None:
            return 0 if access.ready else 1
        return 0 if report["global_route_certified"] and critical.status is not CriticalRoutingStatus.FAILED else 1
    except (BoardLoadError, ValueError, OSError) as exc:
        if args.debug:
            traceback.print_exc()
        print(f"CRITICAL PREFLIGHT ERROR: {exc}")
        return 2


if __name__ == "__main__":
    raise SystemExit(main())

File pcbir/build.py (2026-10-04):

"""Generic profiled routing, saved fill and verification for shared Make rules.

Board sources, library identities, geometry and routing presets belong to the
project, not this runner. Native DRC success is not manufacturing signoff.
"""
from __future__ import annotations

import argparse
from datetime import datetime, timezone
import hashlib
import json
import os
from pathlib import Path
import platform
import shlex
import shutil
import subprocess
import sys
import time

from .compiler import compile_design_file
from .profiling import phase_summary, profiled_command, profile_summary
from .syntax import CopperScriptError


def default_kicad_cli() -> Path:
    configured = os.environ.get("KICAD_CLI") or shutil.which("kicad-cli")
    return Path(configured or Path(os.environ.get("ProgramFiles", "C:/Program Files"))
                / "KiCad/10.0/bin/kicad-cli.exe")


def default_footprints(cli: Path) -> Path:
    configured = os.environ.get("KICAD10_FOOTPRINT_DIR")
    bundled = cli.resolve().parent.parent / "share/kicad/footprints"
    return Path(configured) if configured else (
        bundled if bundled.is_dir() else Path("/usr/share/kicad/footprints"))


def routing_command(source: Path, output: Path, cli: Path, footprints: Path,
                    options: list[str], *, locked: bool = True) -> list[str]:
    reserved = {"-o", "--output", "--report", "--verify-plane-fill", "--locked", "--offline"}
    if any(arg.split("=", 1)[0] in reserved or arg.startswith("-o") and not arg.startswith("--")
           for arg in options):
        raise ValueError("output, report, verification and resolution flags are controlled by the build runner")
    command = [sys.executable, "-u", "-m", "copperscript", "route-board", str(source),
        *(["--locked"] if locked else []), "--offline", "--footprint-root", str(footprints), *options,
        "--verify-plane-fill", str(cli), "--report", str(output / "route-report.json"),
        "-o", str(output / "board.kicad_pcb")]
    from .cli import _parser
    _parser().parse_args(command[4:])
    return command


def completed(output: Path) -> bool:
    """Fail closed: subprocess exit alone is not completion evidence."""
    try:
        route = json.loads((output / "route-report.json").read_text(encoding="utf-8"))
        native = json.loads((output / "kicad-drc.json").read_text(encoding="utf-8"))
        return (route["status"] == "pass" and route["erc_pass"] is True
            and route["routing_complete"] is True
            and route["connectivity"]["native_fill_verified"] is True
            and route["connectivity"]["unrouted_ordinary_nets"] == []
            and native["violations"] == [] and native["unconnected_items"] == []
            and (output / "board.kicad_pcb").is_file())
    except (OSError, ValueError, KeyError, TypeError):
        return False


def run_logged(command: list[str], cwd: Path, log: Path) -> int:
    with log.open("w", encoding="utf-8") as stream:
        process = subprocess.Popen(command, cwd=cwd, stdout=subprocess.PIPE, stderr=subprocess.STDOUT,
            text=True, encoding="utf-8", errors="replace",
            env={**os.environ, "PYTHONUNBUFFERED": "1", "PYTHONIOENCODING": "utf-8"})
        try:
            assert process.stdout is not None
            for line in process.stdout:
                print(line, end="", flush=True)
                stream.write(line)
                stream.flush()
            return process.wait()
        except BaseException as exc:
            # A CI process-group interrupt also reaches the profiled child.
            # Let its finally block save statistics before terminating it.
            if isinstance(exc, KeyboardInterrupt):
                try:
                    process.wait(timeout=10)
                    raise
                except subprocess.TimeoutExpired:
                    pass
            process.terminate()
            try:
                process.wait(timeout=10)
            except subprocess.TimeoutExpired:
                process.kill()
                process.wait()
            raise
        finally:
            if process.stdout is not None:
                process.stdout.close()


def save_performance(output: Path, mode: str, exit_code: int) -> dict:
    result = {"mode": mode, "status": "disabled" if mode == "none" else "missing",
              "process_interrupted": exit_code == 130}
    try:
        if (output / "routing.log").is_file():
            (output / "phase-timings.json").write_text(
                json.dumps(phase_summary(output / "routing.log"), indent=2) + "\n", encoding="utf-8")
            result["phase_timings"] = "phase-timings.json"
        if mode == "cprofile" and (output / "routing.prof").is_file():
            summary, report = profile_summary(output / "routing.prof")
            (output / "profile-summary.json").write_text(json.dumps(summary, indent=2) + "\n", encoding="utf-8")
            (output / "profile-summary.txt").write_text(report, encoding="utf-8")
            result.update(status="saved", raw="routing.prof", summary="profile-summary.json",
                          text="profile-summary.txt")
    except Exception as exc:
        result.update(status="error", error=str(exc))
        print(f"PERFORMANCE REPORT ERROR: {exc}", file=sys.stderr)
    return result
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

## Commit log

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2026-09-22 Add fail-closed physical DRC signoff
    [drc.py]
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2026-09-23 Make detailed routing fail closed on physical copper
    [cli.py, critical.py, detailed.py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]
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2026-09-24 Add source ground-plane intent and correct KiCad pad rotation
    [constraint_coverage.py, model.py]
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2026-09-25 Refine detailed routing grid for exhaustive no-path failures
    [detailed.py]
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2026-10-01 Fix scoped routing repair and grid-independent search costs
    [detailed.py, escape_feedback.py, flow.py]
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2026-10-01 Shorten critical surface trees with atomic local alternatives
    [critical.py, critical_preflight.py, local_critical.py]
2026-10-01 Repair failed critical routing with bounded placement feedback
    [cli.py, critical_feedback.py, critical_preflight.py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]
2026-10-01 Fix octilinear pin access and forward paired terminal miters
    [detailed.py]
2026-10-01 Report per-net routing policy and review corrected full-board layers
    [detailed.py]
2026-10-01 Normalize detailed guide exposure by physical length and replay failed nets
    [detailed.py]
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2026-10-03 Refine unreachable failed nets to bounded configurable fine pitch
    [cli.py, detailed.py]
2026-10-03 Reserve narrow launches during failed-first routing passes
    [detailed.py]
2026-10-04 Export native-DRC-clean manufacturing files with optional independent CAM skip
    [cli.py, manufacturing_files.py]
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2026-10-04 Fix continuous editor dragging and add wheel zoom, right-pan and source patch foundation
    [lexer.py]
2026-10-04 Add importable mechanical board profiles and explicit anchored connector bindings
    [compiler.py, design.py, mechanical_profiles.py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]
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2026-10-04 Resolve footprint dependencies through pinned modules and library bindings
    [cli.py, clusters.py, compiler.py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]
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2026-10-05 Fix portable footprint identities for physical examples
    [clusters.py, hard_macros.py]
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2026-10-05 Negotiate package escape patterns and fix compatibility budget starvation
    [cli.py, escape_assignment.py, flow.py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]
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2026-10-05 Optimize exact Python clearance and immutable grid snapshots
    [detailed.py, drc.py, geometry.py]
2026-10-06 Fix routing occupancy after copper cleanup and record full rerun
    [detailed.py]
2026-10-06 Add signal-integrity routing intent and critical-routing improvements
    - Declare board stack-ups in the mechanical block; screen differential and
    single-ended impedance, reference planes, layer groups and length-match
    groups before routing (copper si-check).
    - Apply mode-group defaults to bonds and pads; add absolute-maximum pin
    limits, including limits relative to another pin's supply.
    - Critical routing: first-failing-gate rejection diagnostics, a lane length
    and delay table, skew compensation near the mismatch, corridor
    reservation for placement, mismatched-pitch pair tapers, bundle-aware
    ordering with bounded rip-up repair, breakout regions and length-match
    group tuning.
    - A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
    [breakout.py, cli.py, compiler.py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]
2026-10-06 Reuse exact-repeat repair searches and speed up fine-pitch grid builds
    Displaced-net rip-up orders rebuild the same trial copper, so the first
    blocker of two orders, and soft proposals with nothing merged in between,
    repeat a detailed search exactly. Repair stages now keep a bounded memo
    keyed by the full search identity: board and resumed checkpoint by
    identity, the ordered clearance additions, net, pads, rule, guide,
    anchors, usage, history, modes and every option. A hit returns the
    earlier attempt, so a failure is reused only while nothing blocking it
    has changed. --search-reuse-entries sets the bound (0 disables).
    Grid construction tests board material once per point instead of once per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
    [cli.py, detailed.py]
2026-10-06 Cache exact outline admission in fanout and grid node points
    Fanout tested every candidate via site against every outline edge with
    Fraction distances and a float square root. Sites are now admitted with
    the exact integer distance predicate, skipping edges whose
    margin-expanded bounds miss the site, and each (site, margin) answer is
    kept for the fanout run. Detailed grids keep one Point per node instead
    of constructing it on every edge evaluation; the cache belongs to the grid
    instance, so a replaced grid with other axes never reads it.
    Results are unchanged; on curved outlines the fanout stage is about 30%
    faster, and detailed routing spends less time building points.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
    [detailed.py, fanout.py]
2026-10-06 Smooth accepted ordinary copper and add opt-in layer balancing
    Route smoothing (CS-162, on by default in route-board):
    walk owned track chains between anchors (vias, branches, width changes,
    immutable copper and interior contacts) and greedily replace each chain,
    longest span first, with one straight or one 45-degree-plus-straight pair
    when that is never longer, never sharper, and shorter or less sharp
    overall. Every replacement passes exact clearance, keepout and outline
    checks and keeps all pad and via contacts; a net whose explicit-copper
    connectivity would change keeps its original copper. Vias and critical,
    reserved, immutable and zone copper are never touched.
    --no-route-smoothing disa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
    [cli.py, detailed.py, layer_assignment.py]
2026-10-06 Record escape-terminal and corner-wrap corridor findings
    R18 in the routing review: reserved package escapes replace the pad as the detailed router's terminal (all boundary ports on the rank-0 layer), causing via chains, hairpins and loops. Lists the planned fixes. R8 in the D-PHY plan: reserve corridors for corner-wrapping bundles as a whole.
2026-10-06 Keep the fabrication profile in editor projection digests of via-in-pad boards
    projection_digest stripped all board metadata before hashing, but via-in-pad permissions are validated against the fabrication profile in that metadata, so route-board failed at export (writing the editor intent) for every board with a via_in_pad constraint. Boards with permissions now keep only their fabrication profile; digests of all other boards are unchanged.
2026-10-06 Offer escaped pads as alternative terminals and release unused escapes
    Reserved package escapes replaced the pad as the detailed router's only
    terminal: one rank-0 inner-layer port per escaped pad. That produced
    escape-via/router-via chains, hairpins past the pad and same-net loops.
    With escape terminals (CS-163, on in route-board, --no-escape-terminals to
    disable), an escaped pad also offers its land and witness centre-line nodes,
    its launch via on every allowed layer, and its normal checked surface
    access. The escape stays reserved while routing, so constrained pins keep
    a legal exit. After routing, release_unused_escapes removes the unused
    land/via/witness copper per access, keeping a re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
    [boundary_access.py, cli.py, detailed.py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]
2026-10-06 Neck down ordinary nets with breakout properties near their pads
    Breakout regions (R1) were only honoured by the critical-pair router. The
    ordinary detailed router kept a net's full width up to the pad, so wide
    rails could not legally reach fine-pitch pins: a 0.4 mm track on a 0.4 mm
    pitch pin row has no clearance to its neighbours, and global pin access
    already failed.
    Ordinary (general) nets that declare breakout properties now check and
    emit every edge, access leg, shortcut and smoothing segment as the
    BreakoutRegions pieces they will have: breakout width inside a terminal
    land's region, rule width outside (CS-164). Copper is never emitted
    narrower than it was checked. A final neck-down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
    [breakout.py, detailed.py, pin_access.py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]
2026-10-07 Improve local placement and preserve verified power routing
    Pack companions around fixed anchors using pad geometry, validate regulator hard macros and retain via finish metadata. Add reserved power-region access and physical via capacity handling, and preserve real copper contacts through routing and cleanup.
    Validation: 1916 tests passed, 47 skipped and one deselected, with the documented pre-existing CM4 fixture and native LoadBoard exclusions. A six-layer board route completed all 87 ordinary nets with zero native DRC errors, warnings or opens.
    [boundary_access.py, cluster_placement.py, copper_connectivity.py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]
2026-10-07 Prefer short local plane contacts for selected GND pads
    [cli.py, critical_preflight.py]
2026-10-07 Plan paired layer swaps for crossing bundle pairs
    When the pair order at the two ends of a critical bundle is inverted,
    the bundle planner now decides which pairs cross before routing: pair
    ranks are read by angle around each component's courtyard centre, the
    surface keeps the largest non-crossing set, and every other pair gets
    one paired layer swap on an allowed layer that no crossing partner
    uses. Moving pairs route first through the paired-via proposer on that
    layer only, with transitions kept out of breakout regions and the
    reserved corridor tried first; every candidate passes the unchanged
    gates. A pair that cannot swap is reported impossible without a
    fallback. Bundle records and the c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
    [breakout.py, critical.py, critical_bundles.py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]
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2026-10-08 Keep placed lands clear of hard-macro copper outside its regions
    Placement kept non-member courtyards out of a hard macro's protected
    regions but never checked their lands against the macro's own tracks
    and vias. Port vias and lead-in stubs may lie outside those regions, so
    a passive could be placed on a port via; materialization then failed
    its physical acceptance DRC and the whole placement was lost. Legality
    now also requires every non-member land to clear the macro's foreign
    tracks and vias by the copper clearance, and each via drill by the hole
    clearance, on the layers they share.
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2026-10-08 Repair a squeezed bundle pair against its nearest neighbours
    Bundle repair only ripped up a routed group that a failed candidate's
    spacing finding named. A middle pair squeezed between pairs routed
    before it, by a pair-to-pair clearance larger than the package pitch
    leaves, finds no candidate at all, so nothing was repaired and the pair
    failed. Such a pair now tries its two physically nearest routed bundle
    pairs (by mean land position at both components) under the same repair
    limit and atomic validation: it routes first and its neighbour routes
    around it.
    [critical.py]
2026-10-08 Plan nested exits for bundles that wrap a package corner
    When a bundle's pairs leave a package across a corner, the side-edge
    pairs overshot their far column and came back: the joint search's ports
    need a straight step on its lattice before any turn. The bundle planner
    now nests the side pairs, innermost first (reordered within the
    bundle's slots), and plans each pair's turn on its far column, or just
    outside the inner pair. A dedicated candidate (shortest port, one
    45-degree diagonal, the run, and a jog back if needed) routes it first;
    the turn steps outward against committed copper, and every candidate
    passes the unchanged gates, falling back to the previous search. On a
    QFN-32 corner wrap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
    [critical.py, critical_bundles.py, critical_preflight.py]
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2026-10-08 Add S-shaped serpentines and tune bundle pairs as they route
    R10: a routing property tuning_style = "serpentine" (default "bumps")
    and an optional tuning_spacing make length-match tuning use two-sided
    legs that cross the original line, with R9's 45-degree corners and one
    chamfer per unit, so each member gains exactly the same length and a
    pair's own skew is unchanged. Each line takes at most one serpentine
    window and falls back to bumps when only one side has room; serpentine
    units also join collinear pieces split at breakout boundaries.
    R12: after each accepted bundle pair of a length_match group, every
    accepted bundle pair short of the longest accepted member is tuned with
    the same tuner,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
    [compiler.py, critical.py, critical_tuning.py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]
2026-10-08 Support fixed netted copper polygons in hard macros
    [drc.py, geometry.py, hard_macros.py]
2026-10-08 Prefer a shorter exact tree for multi-terminal critical nets
    A single-ended critical net that joins three or more lands kept its
    coarse global-guide tree whenever that tree connected, even when its
    junction sat far from the lands: on a crystal net (IC pin, crystal,
    load capacitor) the guide routed past the crystal and branched back,
    11.5 mm for about 4 mm of distance, and boxed in the neighbouring net.
    Such a tree is now also compared with the bounded single-net maze,
    which replaces it only when valid, strictly shorter and using no more
    vias. Clock and RF-feed nets keep the guide.
    [critical.py]
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2026-10-08 Place required via arrays in exposed pads
    A via_in_pad permission may now ask for rows and columns (and an
    optional pitch): a required, centred grid of 0.30/0.20 mm filled-capped
    GND through-vias inside the land, as IC layout guides ask for in an
    exposed pad that carries both heat and the IC's ground return. The array
    is placed with the hard-macro copper, before package access, critical
    routing and ordinary routing, so every later stage treats it as fixed
    copper and plane stitching adds no other contact for that pad. The
    default pitch spreads the vias one cell apart; every site is checked for
    land containment, board edge, GND zone, keepouts, copper, other lands
    and drill spacing, and any fai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
    [cli.py, critical_preflight.py, detailed.py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]
2026-10-08 Trim a released dogbone back to the land it crosses
    When a route reached a land along a package-access dogbone that passes
    through it, cleanup deleted the dogbone's launch via (left on one layer)
    but could not touch the owned, non-disposable stub, which then ran on
    past the land with an open end: KiCad reported a dangling track and plane
    verification failed. Escape release now cuts such an owned stub back to
    the centre of the same-net land it crosses, on its own octilinear line,
    and keeps the cut only if the net stays connected and loses the open
    end. Disposable tracks keep their existing, conservative pruning.
2026-10-08 Trim a fanout stub back to the land it reaches when its via is pruned
    The detailed router removes a provisional fanout via that a successful
    route uses on only one layer, keeping its surface stub. When the route
    reached the target land along that stub, the stub still ran on past the
    land to where the via had been, leaving a dangling end that failed
    native plane verification. Nets whose fanout via is pruned now have
    their owned copper pruned with overhang trimming, so such a stub ends at
    the centre of the land it crosses. Other nets are unchanged; an nrf52
    route is identical apart from UUIDs and paths.
    [detailed.py]
2026-10-08 Sweep open overhangs past lands before final DRC
    A track can still end past a land of its own net that it crosses, for
    example a package-access dogbone that connects its net through that
    land and is kept as input copper while another stage deletes its launch
    via, which then fails native plane verification as a dangling track.
    Before final DRC, route-board now sweeps ordinary nets and cuts such a
    routed track back to the land's centre, keeping a net's change only when
    it stays connected and loses open ends. Input, hard-macro, critical and
    zone copper never change.
    [cli.py]
2026-10-08 CI: warm every standalone example's package cache
    The examples migrated to their own copper.mod/copper.lock (nRF52 and the
    nRF antenna macro alongside CM4), each with its own package cache, but
    the CI preparation only warmed CM4's. The nRF52 compile then ran offline
    against an empty cache and failed with PKG011, so every later step was
    skipped. Preparation now compiles each standalone example once online
    and once offline; the nRF52 route also needs the antenna macro's cache
    for its hard-macro scene.
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2026-10-09 Check out managed packages with repository line endings
    A dependency's own .gitattributes decides line endings on checkout: the
    KiCad footprint library marks *.kicad_mod `text=auto`, so git converted
    it per core.eol, whose default is native. core.autocrlf=false does not
    override that, so a Windows checkout produced CRLF and recorded CRLF
    hashes in the lock, which no Linux checkout can reproduce: every locked
    resolution there failed with PKG008, one byte per line apart.
    The resolver now also pins core.eol=lf on clone, fetch and checkout, so
    every platform sees the repository's own bytes, and the three locks that
    recorded the converted footprints are regenerated from them.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
    [packages.py]
2026-10-09 CI: warm the requirements compilation never resolves
    Preparation warmed each project's cache by compiling it, but compiling
    resolves only the modules its imports name. Footprint libraries are
    resolved later, by the backend, so a footprint-only requirement such as
    the KiCad library stayed unfetched and the offline layout failed with
    PKG011 on the first example that needed one.
    Every module a project's copper.mod requires is now fetched directly,
    for the repository's own module as well as each standalone example; a
    requirement the lock does not record is skipped, since no locked stage
    could use it either. Its test now states the warming contract instead of
    counting one online compile.
    Co-Aut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
2026-10-09 Prefer short local vias for distribution zones
    Compare existing contacts with nearby legal vias for pads over non-GND zones, preserving the GND override. Cover reuse and repeated stitching, and record the verified V3V3 full-route result.
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2026-10-12 Reduce placement and routing geometry overhead
    Avoid physical-board clones for surface chamfering and canonical footprint
    rendering. Cache exact immutable macro land geometry, placement envelopes and
    courtyards, and search-local symmetric edge costs with compact node keys.
    Preserve fresh permission checks, exact geometry tests and search ordering.
    Add isolated method comparisons and cache/context regressions. The matched
    full-vertical cProfile run drops from 1391.918 s to 724.974 s (47.9%), with
    identical routed copper, zero native DRC violations and zero unconnected items.
    Record the 2687 passing / 18 skipped regression results and evidence scope.
2026-10-12 Support partially assembled boards in the selection BOM
    A board whose passives and common ICs the assembler stocks, with a few
    specialist parts it does not, could not export a BOM at all: write_jlcpcb_bom
    refused any lock containing a non-jlcpcb supplier, and the only alternative was
    the library-level assembled=false, which means "not a populated component"
    (bare-board targets), not "populated but sourced elsewhere".
    Add a per-selection populate mode:
    supplier (default) the assembler sources and places it in BOM/CPL
    consigned fitted, supplied/placed outside the order excluded
    none deliberately not fitted excluded
    Only supplier-assem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
2026-10-12 Verify fixed-placement edge clearance against declared body overhangs
    The legalizer and the requirement verifier disagreed about the same
    declaration. placement.py legalizes a pose with body_in_material, which honours
    a declared overhang window; requirement_verification._placement re-checked the
    same pose with bare shape_in_board and had no notion of overhangs at all. A
    component legally overhanging the board edge therefore always failed its own
    fixed_placement requirement.
    On CopperVigo both I-PEX CSI-2 receptacles hit this: their courtyards extend
    past the bottom edge under declared overhangs, with lands staying 0.375 mm
    inside, yet every route reported "declared edge clearance is violate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
2026-10-13 Add reusable RF/CAM review and strengthen routing validation
    Validate with 2802 passing CopperScript tests (17 explicit environment skips), native artwork integration and a fresh 97-footprint Tracker route: 61 ordinary nets connected, 21 surface decoupling feeds, zero native opens or included violations. Preserve incomplete RF/USB/power/CAM qualification gates. Keep this tested snapshot isolated from concurrent physical-macro language work.
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2026-10-13 Use board designators in the supplier BOM and hand-assembly list
    The KiCad export flattens hierarchical source references, so BUCK_1V2/C_AVIN is
    placed and printed as BUCK_1V2_C_AVIN. The BOM still wrote the source path, and
    an assembler matches BOM, CPL and silkscreen by designator, so every
    hierarchical component was unmatched against its own placement.
    export-manufacturing caught it ("BOM references missing from position
    export") on the first board with hierarchy to order; flat boards never hit it.
    Both writers now map references through kicad_reference, the mapping the PCB
    backend, native checkpoint and editor overlay already share. Two references
    that flatten to one designator are refu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
2026-10-14 Allow copper.mod to replace a module with another remote repository
    `replace MODULE => SOURCE REVISION` fetches a module's content from another
    GitHub/GitLab repository while every import, footprint binding and macro
    member URL keeps the module's own identity. The lock keeps the required
    version as its key and records the fetched source and revision, so
    retargeting the replacement is a lock change. CI still refuses any
    replacement of CopperLib.
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2026-10-15 Score registered terminal-via congestion during global target selection
    Use the existing present/history penalty units for a target's registered
    physical via resource before selecting its access. Preserve exact per-net
    physical-site multiplicity, skip reused sites already charged by the path or
    tree, and reject unsupported registration without inventing capacity.
    Root selection, graph capacities, geometry gates and search bounds stay intact.
    Validation: 12 focused cases and 66 existing global/routing regressions pass.
    Frozen review manifest: 97024fe3b2c3228e0f9d1c78185706d2d360bbc7edd92794e1203dfa9e32df19
    No real-device overflow closure is established by these tests.
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2026-10-19 Add benchmark ladder, never-block pipeline and unified router prototype
    - copper bench: route a ladder of boards and compare completion, DRC and time
    - route-board reports a pipeline-independent summary block
    - incomplete package access or rejected power preparation no longer stop
    ordinary routing; --legacy-gates keeps the old behaviour
    - pcbir/unified_router.py: one negotiated-congestion loop over a numpy
    legality raster with exact commit checks (--router unified)
    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
2026-10-19 Unified router: breakout neck-down, macro ports, BGA dogbones and plane estimate
    - neck down only inside declared breakout regions, as DRC requires
    - hard-macro pad groups attach at their routing ports
    - deterministic quadrant dogbone fanout for full-grid BGAs (pcbir/bga_fanout.py)
    - raster estimate of zone fill connectivity for runs without KiCad
    - unified mode skips package-access search and the power-preparation allocator
    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
